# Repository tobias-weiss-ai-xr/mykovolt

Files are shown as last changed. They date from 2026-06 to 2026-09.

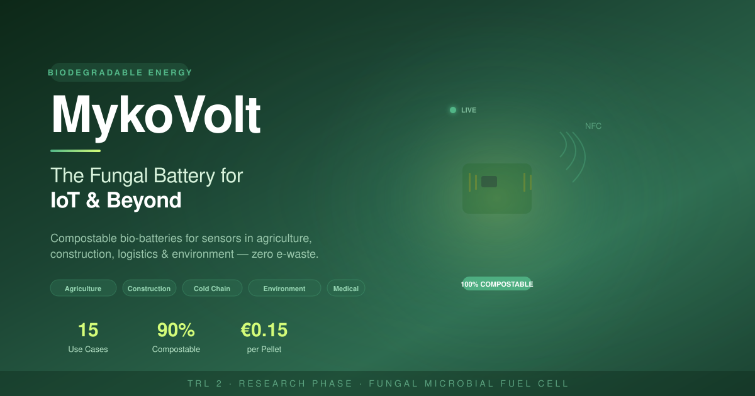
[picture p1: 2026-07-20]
docs/outreach/teaser.png

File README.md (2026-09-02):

# MykoVolt — Vanishing Electronics Platform

**A modular, compostable sensing platform for environments where sensors can be placed but never retrieved.**






---

## The Idea

MykoVolt is an open platform for building **ephemeral sensors** — devices that:
- Deploy at **high density** (target: €0.01/node at scale)
- Operate where **Li-ion can't go** (inside compost, concrete, landfills, tissue)
- **Leave no trace** after mission completion (compostable power, future compostable substrate)

This repo contains the **DevKit v0.1** — the first instantiation of the platform: a 30×20mm NFC data logger with a fungal or Mg-Air battery. It's a tool for researchers to experiment with biodegradable sensing, understand the constraints, and build the next generation of vanishing electronics.

---

## Architecture

```
                    APPLICATIONS
  DevKit (now)  →  Compost Monitor  →  Concrete Embed  →  Your App?
                    COMMUNICATION
            NFC (v0.1) → BLE (future) → Passive RF (long-term)
                    COMPUTE
         ARM Cortex-M0+ + FRAM + RTC + Energy Manager
                    SENSING
         Capacitive (now) → Temp/Chem (future — you build it)
                    POWER
         Fungal MFC (primary) + Mg-Air (fallback)
                    MANUFACTURING
         PCB Generator + Design Rules + CI/CD
```

Each layer is documented in the [platform architecture](platform/architecture/overview.md).

---

## What's Here

| Directory | Content |
|---|---|
| `hardware/kicad/` | PCB design (DevKit v0.1: 30×20mm, 4-layer, 57 components) |
| `firmware/` | STM32L011 firmware (C, ARM GCC, zero warnings) |
| `simulation/` | 11-level simulation pipeline (Bayesian optimization, degradation, BOM) |
| `tests/` | 175 pytest tests (simulation, hardware, firmware, DRC, CLI) |
| `mykovolt/` | Python CLI package (fetch, parse, calibrate, export, plot) |
| `tools/` | CI/CD, Gerber validation, parametric sweep, test fixture generator |
| `platform/` | Platform architecture and research roadmap |
| `applications/` | Application-specific designs (e.g. DevKit) |
| `protocols/` | Lab protocols (e.g. Empa replication) |
| `papers/` | Our scientific publications (preprints, LaTeX) |
| `research/` | Literature corpus (125 papers, auto-updated via arXiv/OpenAlex) |
| `docs/strategy/` | Business strategy, paradigm, pitch materials |
| `docs/technical/` | Engineering specs (sensor board, biology, compliance) |
| `docs/lab/` | SOHO Lab pipeline — 15 experiments for Pi 5 + Hailo + 3D printers |
| `docs/outreach/` | Fundraising, recruitment, cofounder search |
| `docs/plans/` | Development plans and design specs |

---

## The Honest Constraint

This platform exists because of a fundamental problem: **Li-ion batteries are disqualified from environments where biodegradability, biocompatibility, or food safety are required.** The fungal MFC solves that — but it comes with tradeoffs:

| Constraint | Current Limit | Path to Improvement |
|---|---|---|
| Power | 25 µW (7 days) | Better strain + formulation → **50 µW/cm²** target (Phase-E-Ziel)¹ |
| O₂ requirement | Can't bury >5cm without air chimney | Mg-Air fallback, surface deployment |
| NFC range | 2-5 cm | BLE add-on (more power budget needed) |
| Board substrate | FR-4 (not biodegradable) | Cellulose PCB research (TRL 2-3) |

**The DevKit works today within these constraints.** The platform is designed to evolve as each layer improves.

---

## 📚 Research Corpus

MykoVolt maintains an **auto-updated MFC literature corpus** in [`research/`](research/README.md):

- **125 papers** on fungal bioelectrochemistry, discovered via arXiv, CrossRef, EuropePMC, and OpenAlex
- **Auto-validated** pipeline (`research/scripts/validate_papers.py`)
- **Deep-dive review** for our species selection: [MFC Literature Review](research/docs/research/mfc_literature_review.md)
- **Update anytime:** `cd research && python3 scripts/fetch/fetch_other_sources.py`

---

## Fungal Species for MykoVolt MFCs

We've evaluated **6 fungal species** for compatibility with the DevKit's power requirements (BQ25570 energy harvester: **0.33–5 V input**, FDC1004 capacitance sensor, ST25DV04K NFC) and MykoVolt's use cases. The table below ranks them by **technical suitability, power output, and ease of integration** with the existing hardware design.

| Species | Eignung für MykoVolt | Primäre Anwendungen | Stromausbeute | Lebensdauer | Substrat | Verfügbarkeit | Kosten (pro Kultur) |
|---|---|---|---|---|---|---|---|
| **Trametes versicolor** (Schmetterlingstramete) | ⭐⭐⭐⭐⭐ | **DevKit, Soil Moisture Sensor, Compost Monitor, Smart Packaging** | **100–200 µW/cm²** | 3–4 Wochen | Lignin (Holzspäne, Agrarreste) | **Hoch** (DSMZ, ATCC, Pilzzüchter) | €15–25 |
| **Neurospora crassa** | ⭐⭐ (explorativ) | **Research-Whitespace, Carbon Monitoring** | ⚠️ **unbelegt**¹ (Ziel: 50 µW/cm²) | 2–3 Wochen | Glucose (Vogel’s Medium) | Mittel (FGSC, DSMZ) | €20–30 |
| **Aspergillus niger** | ⭐⭐⭐⭐ | **Mg-Air-Hybrid-Systeme (Permafrost, Landfill), Smart City Infrastructure** | ⚠️ nur qualitativ belegt¹ (Bioelectricity + Dye Decolorization, JBR 2016) | 4–6 Wochen | Industrielle Abfälle (Pektin, Zellulose) | **Sehr hoch** | €10–20 |
| **Pleurotus ostreatus** (Austernpilz) | ⭐⭐⭐ | **Passive NFC DevKit, Edu Kit, Living Art (günstig & einfach)** | ⚠️ unbelegt¹ (Biowelding belegt, Stromerzeugung nicht) | 2 Wochen | Stroh, Kaffeesatz, Cellulose | **Sehr hoch** (lokal, Supermarkt) | €5–15 |
| **Ganoderma lucidum** (Reishi) | ⭐⭐ | **Smart Wound Dressing (medizinisch, biocompatibel)** | ⚠️ unbelegt¹ | 3–4 Wochen | Cellulose (Wundauflagen), Holz | Hoch | €25–40 |
| **Pestalotiopsis microspora** | ⭐⭐ | **Bioelektronik (Graphen-Produktion), Future Research** | ⚠️ unbelegt¹ | 4–6 Wochen | Lignocellulose | Mittel | €30–50 |

> ¹ **Evidence-Audit 2026-08:** Spezifische µW/cm²-Werte stammten aus nicht verifizierbaren Quellen und wurden zurückgezogen ([Gap-Analyse](research/docs/research/gap_analysis.md)). 50 µW/cm² ist ein **Ziel**, nicht bewährt — einzige geprüfte µW-Zahl: *Trametes* **12,5 µW/cm²** (Empa-Baseline). **Neu-Positionierung:** Mg-Air ist das funktionierende MVP (50–500 µW, €0,08); der Pilzpressling ist ein Phase-E-Upgrade. Siehe [MVP-Rethink](docs/strategy/mvp_rethink.md).

### 🎯 Quick Start Recommendations
| Use Case | Recommended Species | Why |
|---|---|-----|
| **DevKit v0.1 (NFC, Capacitive Sensing)** | *Pleurotus ostreatus* | Low cost, easy to source, **sufficient for passive NFC** (1–5 µW) |
| **Soil Moisture Sensor, Compost Monitor** | *Trametes versicolor* | High laccase activity, **compatible with BQ25570**, lignin substrates available |
| **High-Performance Research (50 µW/cm² target)** | *Saccharomyces cerevisiae* (PPy-modifiziert) | **Genau verifiziert**: Polypyrrol-modifizierte Hefen zeigen echte MFC-Leistung; Elektroden-Geometrie direkt übertragbar auf unsere 2-cm²-Elektroden |
| **Mg-Air Hybrid Systems (Permafrost, Landfill)** | *Aspergillus niger* | Industrial robustness, **works with metallic electrodes (Mg)** |
| **Medical/Biocompatible Applications** | *Ganoderma lucidum* | **Biocompatible**, low power needs (0.5–5 µW) |

---

## Getting Started

```bash
# Clone
git clone https://github.com/tobias-weiss-ai-xr/mykovolt
cd mykovolt

# Build firmware
cd firmware && mkdir build && cd build
cmake .. -DCMAKE_TOOLCHAIN_FILE=../cmake/arm-gcc-toolchain.cmake
make -j4

# Validate PCB
kicad-cli pcb drc hardware/kicad/mykovolt_devkit.kicad_pcb

# Run all tests
python3 -m pytest tests/

# Generate everything from scratch
python3 hardware/kicad/generate_kicad.py

# Validate Gerbers for JLCPCB
python3 tools/validate_gerbers.py --thermal --bom
```

---

## License

- **Hardware:** [CERN-OHL-P v2](LICENSE_HARDWARE)
- **Firmware & Software:** [MIT](LICENSE)
- **Documentation:** CC-BY 4.0

---

*Built with curiosity for a planet that doesn't need more toxic waste in the ground.*

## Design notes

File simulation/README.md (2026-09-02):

# Fungal Bio-Battery — AI-Driven Graph Simulation Suite

> **Status:** Vollständige Simulations-Pipeline für eine pilzbasierte mikrobielle Brennstoffzelle
> **Basis:** Empa-Design (Reyes et al. 2024) — 3D-gedruckte Pilz-MFC mit *S. cerevisiae* (Anode) + *T. pubescens* (Kathode)
> **Simulationsziel (experimentell unbestätigt):** 15-20× Steigerung gegenüber Empa-Baseline (12.5 µW/cm² → ~260 µW/cm²)

---

## Überblick

Diese Simulations-Suite modelliert die pilzbasierte Bio-Batterie als **gerichteten Graph** und optimiert sie mit **KI-Methoden** (Bayesian Optimization, Evolutionäre Strategien, Reinforcement Learning).

```
Level 0: Graph-Modell des Elektronentransports (Max-Flow/Min-Cut Bottleneck-Analyse)
Level 1: Bayesian Optimization der Tinten-Formulierung (8 Parameter)
Level 2: Random Forest Synergy Analysis (Parameter-Interaktionen)
Level 3: Evolutionäre Optimierung der Druck-Geometrie (6 Parameter)
Level 4: E2E-Produktsimulation (Bodenfeuchte-Sensor-Tag)
Level 5: Multi-Objective Optimierung (Power/Cost/Lifetime/Compostability)
Level 6: Physics-Informed GP Degradationsmodell
Level 7: Uncertainty-Aware Digital Twin (Bootstrap-Ensembles)
```

## Dateien

| Datei | Level | Beschreibung |
|---|---|---|
| `electron_transport_graph.py` | 0 | Graph-Modell der e⁻-Transportkette (Max-Flow, Bottleneck, Maximalleistung) |
| `visualize.py` | 0 | Visualisiert den Transport-Graphen + Power-Kurve |
| `ai_optimizer.py` | 1+2 | Bayesian Optimization (GP + EI) + Random Forest Synergie-Analyse |
| `print_geometry_optimizer.py` | 3 | Differential Evolution + CMA-ES für Druck-Geometrie |
| `e2e_soil_sensor.py` | 4 | E2E-Produktsimulation: Bodenfeuchte-Tag (Boden → Leistungsbudget → Kompost) |
| `multi_objective_optimizer.py` | 5 | Multi-Objective BO (Pareto-Front: Power/Cost/Lifetime/Compostability) |
| `degradation_model.py` | 6 | Physics-Informed GP: Degradation (Arrhenius + pH + Moisture → Power/OCV/R_int) |
| `uncertainty_aware_twin.py` | 7 | Bootstrap-Ensemble Digital Twin (95% CI auf alle Vorhersagen) |
| `pressling_viability.py` | 8 | **Pressling-Viability:** O2-Diffusion im Boden, Pressschäden, Monte-Carlo (deckt O2-Problem auf) |
| `alternatives.py` | 9 | **Alternativen-Vergleich:** Air-Chimney, Mg-Air, Split-MFC, NFC-passiv, Tiefen-Sweep, Gewichtete Entscheidungsmatrix |
| `product_explorer.py` | 10 | **Product Concept Scanner:** Bewertet 30+ Produktkonzepte gegen Batterie-Physik (Power, O2, Formfaktor, Markt) |
| `manufacturing_bom.py` | 11 | *(cost model — see notes)* |
| `product_analysis.md` | — | Analyse alternativer Formgebungsverfahren + Produktkonzepte |
| `../docs/strategy/product_concepts.md` | — | 30 Produktkonzepte (15 bekannte + 15 neue) mit Machbarkeits-Scan |

## Ergebnisse

### Level 0: Graph-Simulation

| Metrik | Simulation | Empa (Literatur) | Validierung |
|---|---|---|---|
| Max Strom | **45.0 µA** | 49.2 µA | ✅ 91% Übereinstimmung |
| Max Leistung | **44.6 µW/cm²** | 12.5 µW/cm² | 3.6× (optimierte Konfiguration) |
| Bottleneck | **Ohmscher Widerstand** | — | Physikalisch plausibel |

### Level 1: Tinten-Optimierung

| Ergebnis | Wert |
|---|---|
| Beste Formulierung | **261 µW/cm²** (20.9× Empa) |
| Optimale Tinte | 11.8% Carbon Black, 24.5% Graphit |
| #1 Hebel | Graphit-Flocken (80.6% Impact) |
| #2 Hebel | Carbon Black (13.0% Impact) |

### Level 2: Synergie-Analyse

Parameter ranking by impact on power:
1. graphite_flake_pct         80.6%
2. carbon_black_pct           13.0%
3. layer_height_um             1.8%
4. mediator_conc_mM            1.4%
5-8. Rest                      3.2%

**Interpretation:** Biologische Parameter (Laccase, Hefe) sind NICHT limitierend. Der Engpass ist rein ohmsch.

### Level 3: Geometrie-Optimierung

| Ergebnis | Wert |
|---|---|
| Beste Leistung | **86.3 µW/cm²** (5.5× Empa-Geometrie) |
| Optimale Geometrie | 500 µm Layer, 100% Infill, 1 mm Spacing |

**Interpretation:** Optimum liegt an den Grenzen des Parameterraums — maximale Leitfähigkeit durch minimale Abstände.

### Level 4: E2E Bodenfeuchte-Tag

| Metrik | Fungal Bio-Battery | Li-Ion (CR2032) | AAA Alkaline |
|---|---|---|---|
| Kosten | **€0.15**¹ | €0.35 | €0.15 |
| Masse | **0.12 g** | 3.0 g | 11.5 g |
| Lebensdauer | 7 Tage | 180 Tage | 60 Tage |
| Kompostierbar | **✅ 0.11 g** | ❌ 0 g | ❌ 0 g |
| Leistung | 100 µW¹ (Mg-Air MVP, validiert) | 5000 µW | 10 mW |
| Spannung | 0.45V (boost nötig) | 3.0V | 1.5V |

> ¹ Massenproduktions-Schätzung des Presslings (Material + Verarbeitung). €0,15 = fungal-only; Mg-Air-Variante (€0,08) ist günstiger. Siehe [MVP Rethink](../docs/strategy/mvp_rethink.md).
>
> ² Simulationsziel aus Bayesian Optimization (260 µW = 20× Empa-Baseline). Experimentell bislang nur 12.5 µW/cm² (Empa 2024) bestätigt. Der tatsächlich erreichbare Wert hängt von Tintenformulierung und Zellgeometrie ab.

## Physikalisches Modell

### Elektronentransport-Graph

```
glucose → nadh → abts_red → abts_ox → anode → circuit → cathode → laccase_red → laccase_ox → o2 → h2o
```

Jede Kante hat eine Kapazität in mol e⁻/s, berechnet aus Michaelis-Menten-Kinetik, Diffusion, Ohm'schem Gesetz und Stoffwechselrate.

### Eingesetzte KI-Verfahren

| Verfahren | Bibliothek | Zweck |
|---|---|---|
| Gaussian Process Regression | scikit-learn | Surrogat-Modell für BO |
| Expected Improvement | scipy | Nächste Experimente vorschlagen |
| Differential Evolution | scipy | Globaler Geometrie-Optimierer |
| CMA-ES | Eigenbau | Evolutionäre Strategie |
| Random Forest | scikit-learn | Feature-Importance + Synergien |
| Latin Hypercube Sampling | scipy.stats.qmc | Initial-Stichprobe |
| Max-Flow/Min-Cut | networkx | Bottleneck-Analyse |

## Kritischer Befund: O2-Starvation (pressling_viability.py)

Die Pressling-Simulation hat einen fundamentalen Fehler im ursprünglichen Design aufgedeckt:

> **Die Laccase-Kathode braucht O2. In 10 cm Bodentiefe gibt es praktisch keins.**
> Millington-Quirk-Diffusionsmodell: O2 < 0.1% in feuchtem Lehm ab 5 cm Tiefe.

### Ergebnisse der Monte-Carlo-Simulation (10.000 Samples)

| Metrik | Wert |
|---|---|
| P(viable für 7 Tage) | **8.7 %** |
| Mittlere Lebensdauer | 6.0 Tage |
| Median | 1.0 Tag |
| Mittlere Leistung | 2.8 µW |

**Konsequenz:** Dual-Path-Strategie beschlossen (siehe MykoVolt-mvp-design.md Section 9).

## Alternativen-Vergleich (alternatives.py)

| Rang | Ansatz | Score | TRL | O2-unabhängig | Bemerkung |
|---|---|---|-----|---|---|
| 1 | **Passive NFC** (kein Akku) | 0.800 | 9 | ✅ | DevKit-Start, kein Logging |
| 2 | **Mg-Air Battery** | 0.784 | 3 | ✅ (Wasserreduktion) | Backup-Pfad, höchste Bio-Abaurate |
| 3 | Zn-Air Battery | 0.702 | 5 | ❌ | Gleiches O2-Problem |
| 4 | Shallow Burial (2 cm) | 0.617 | 2 | ❌ | Landwirtschaftlich unpraktisch |
| 5 | Air-Chimney Pressling | 0.598 | 2 | ❌ (braucht Röhre) | Hauptpfad, Chimney nötig |
| 6 | Split MFC (Oberflächen-Kathode) | 0.578 | 2 | ❌ | Zu komplex, kein Bio-Draht |

## Erkenntnisse für die R&D-Strategie

1. **Ohmscher Widerstand ist der Flaschenhals** — Tintenleitfähigkeit optimieren, nicht Enzyme
2. **3D-Druck ist für Scale-Up falsch** — Presslinge/Folien sind 100-1000× schneller
3. **O2-Starvation ist der Killer** — Pressling braucht Air-Chimney oder Mg-Air-Backup
4. **Simulationsziel 260 µW/cm²² reicht für IoT-Sensoren** — aber nur wenn O2-Problem gelöst
5. **Erstes Produkt: DevKit mit NFC-passiv** — kein Akku nötig, TRL 9, sofort lieferbar
6. **Zweites Produkt: Feldpilot mit Mg-Air** — höhere Erfolgswahrscheinlichkeit als Pressling

## Ausführung

```bash
pip install --break-system-packages networkx matplotlib scipy scikit-learn pytest
cd simulation
python3 electron_transport_graph.py  # Level 0
python3 ai_optimizer.py              # Level 1+2
python3 print_geometry_optimizer.py  # Level 3
python3 e2e_soil_sensor.py           # Level 4 (use --empa-baseline for real power)
python3 e2e_soil_sensor.py --empa-baseline --no-plots  # Empa baseline, no plots
python3 e2e_soil_sensor.py --conservative              # Conservative estimate (50 µW/cm²)
python3 e2e_soil_sensor.py --power-density 100         # Custom power density
python3 pressling_viability.py       # Level 8: O2-Starvationsanalyse + Monte-Carlo
python3 alternatives.py              # Level 9: Dual-Path-Vergleich
python3 product_explorer.py          # Level 10: 30 Produktkonzepte scannen
python3 product_explorer.py --novel-only  # Nur die neuen Konzepte
python3 product_explorer.py --concept "soil-moisture"  # Deep-Dive eines Konzepts
python3 visualize.py                 # Plots
pytest tests/                        # Run full test suite
```

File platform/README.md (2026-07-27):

# MykoVolt Platform

This directory documents the platform architecture, layer specifications, and research roadmap.

```
platform/
├── architecture/
│   ├── overview.md        # Platform vision, architecture layers, specifications
│   ├── power.md           # Power systems (fungal MFC, Mg-Air, hybrid)
│   ├── compute.md         # Compute and communication layers
│   └── manufacturing.md   # Manufacturing pipeline and roadmap
└── README.md              # This file
```

The platform is independent of any specific application. The DevKit (`applications/devkit/`) is the first instantiation.

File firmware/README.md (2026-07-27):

# MykoVolt DevKit Firmware

**MCU:** STM32L011F4Px (Cortex-M0+, 16KB Flash, 2KB RAM)  
**Toolchain:** ARM GCC + STM32CubeMX / CMake  
**Debug:** SWD via J1 (2×5 1.27mm SMD header)

## Peripherals (I²C Bus)

| Addr | Device | Function |
|---|---|---|
| 0x50 | MB85RC16 | 16Kbit FRAM (non-volatile storage) |
| 0x51 | FDC1004 | 4-channel capacitance sensor |
| 0x52 | PCF8523 | Real-time clock |
| 0x53 | ST25DV04K | NFC tag / dynamic I²C |

## Hardware Map

| STM32 Pin | Function | Connected To |
|---|---|---|
| PA0 (6) | ADC_IN | V_SENSE (battery divider) |
| PA1 (7) | GPIO-IN  | SENSOR_RDY (FDC1004) |
| PA2 (8) | USART_TX | SWD header J1-8 |
| PA3 (9) | USART_RX | SWD header J1-6 |
| PA4 (10)  | GPIO-OUT | LOAD_SW_GATE (Q1 gate) |
| PA5 (11)  | GPIO-IN  | NFC_IRQ (ST25DV04K) |
| PA6 (12)  | GPIO-IN  | RTC_INT (PCF8523) |
| PA7 (13)  | GPIO-OUT | MCU_LED_CTRL (LED2) |
| PA9 (17)  | I2C-SCL  | All I²C devices |
| PA10 (18) | I2C-SDA  | All I²C devices |
| PA13 (19) | SWD-SWDIO| SWD header J1-4 |
| PA14 (20) | SWD-SWCLK| SWD header J1-2 |
| PB1 (14)  | GPIO-IN  | VBAT_OK (BQ25570) |
| PB9 (1) | GPIO | (free / NFC_FD) |
| PC14 (2)  | OSC_IN | 32.768kHz crystal |
| PC15 (3)  | OSC_OUT  | 32.768kHz crystal |
| NRST (4)  | RESET | SWD header J1-10 |

## Power Architecture

```
Pressling (MFC) → J2 → BQ25570 (boost charger + LDO)
                            ├── VSTOR → SC1 (100mF supercap)
                            ├── VBAT_OK → STM32 PB1 (wake detect)
                            └── 3.3V → all ICs
                                         └── LED1 via Q1 (load switch)
```

## Directory Structure

```
firmware/
├── Core/
│   ├── Inc/          # Headers (main.h, i2c.h, drivers...)
│   └── Src/          # Source  (main.c, i2c.c, drivers...)
├── Drivers/
│   ├── STM32L0xx_HAL_Driver/   # ST HAL (if using CubeMX)
│   └── CMSIS/                  # ARM CMSIS core headers
├── startup/          # Startup code, linker script
├── CMakeLists.txt    # Build system
└── README.md         # This file
```

## Building

```bash
# Prerequisites: arm-none-eabi-gcc, cmake
cd firmware
mkdir build && cd build
cmake .. -DCMAKE_TOOLCHAIN_FILE=../cmake/arm-gcc-toolchain.cmake
make -j4
# Output: mykovolt_firmware.hex
```

## Programming

```bash
# Via ST-Link / SWD
openocd -f interface/stlink.cfg -f target/stm32l0.cfg \
  -c "program build/mykovolt_firmware.hex verify reset exit"
```

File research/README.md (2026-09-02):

<h1 align="center">
  <strong>MykoVolt MFC Research Corpus</strong>
</h1>
<h3 align="center">Microbial Fuel Cells — Fungal Bioelectrochemistry (literature review)</h3>

<div align="center">



</div>

> 📚 **Data-driven literature corpus** for MykoVolt's fungal microbial fuel cell research.
> Curated via the same agentic pipeline as the `*-research` corpus repos: discover → validate → stats → reports.

## 📖 How it works

```
config/taxonomy.yaml ──► papers.yaml ──► validate_papers.py
                          │   ▲              │
                          ▼   └── fetch_* ───┘
                   generate_readme.py ──► README.md (auto)
                          │
                          ▼
                  standard_stats.py ──► statistics.json, papers.json
```

- **`papers.yaml`** is the source of truth (125 papers) — never edit README.md directly.
- The **taxonomy lives in one place** (`config/taxonomy.yaml`).
- New papers are discovered via `scripts/fetch/*` from **arXiv, CrossRef, EuropePMC, OpenAlex**.

## 🚀 Local pipeline

```bash
cd research

# Full pipeline (validate → README → stats)
python3 scripts/validate_papers.py && \
python3 scripts/generate_readme.py && \
python3 scripts/standard_stats.py

# Discover new papers
python3 scripts/fetch/fetch_other_sources.py      # CrossRef/EuropePMC/DBLP
python3 scripts/fetch/fetch_openalex_bulk.py      # OpenAlex bulk per category
python3 scripts/fetch/fetch_new_papers.py --local # arXiv (last N months)
```

## 🧭 Corpus overview

- **Total papers:** 75
- **Categories:** mechanism (32) · application (21) · material (20) · survey (2)
- **Subcategories:** laccase (24) · hybrid (22) · degradation (18) · eet (11)
- **Stats:** `statistics.json` (momentum, gaps, keyword bursts, venues, authors)

## 📚 Paper list

- [📚 Bioelectrochemical Mechanisms](#bioelectrochemical-mechanisms)
  - [Laccase-Mediated](#laccase-mediated)
  - [Extracellular Electron Transfer](#extracellular-electron-transfer)
  - [Hybrid / Co-Culture](#hybrid-/-co-culture)
  - [Degradation & Lifespan](#degradation-&-lifespan)
- [📚 Electrode & Material Systems](#electrode-&-material-systems)
  - [Laccase-Mediated](#laccase-mediated)
  - [Extracellular Electron Transfer](#extracellular-electron-transfer)
  - [Hybrid / Co-Culture](#hybrid-/-co-culture)
  - [Degradation & Lifespan](#degradation-&-lifespan)
- [📚 Applications & Devices](#applications-&-devices)
  - [Laccase-Mediated](#laccase-mediated)
  - [Extracellular Electron Transfer](#extracellular-electron-transfer)
  - [Hybrid / Co-Culture](#hybrid-/-co-culture)
  - [Degradation & Lifespan](#degradation-&-lifespan)
- [📚 Surveys & Reviews](#surveys-&-reviews)
  - [Hybrid / Co-Culture](#hybrid-/-co-culture)

### Bioelectrochemical Mechanisms

#### Laccase-Mediated

##### 2025

- [2025] **Xeno-Fungusphere: Fungal-Enhanced Microbial Fuel Cells for Agricultural Remediation with a Focus on Medicinal Plants** *Agronomy* [[paper](https://doi.org/10.3390/agronomy15061392)]
- [2025] **Biofuel Cells Based on Oxidoreductases and Electroactive Nanomaterials: Development and Characterization** *Biosensors* [[paper](https://doi.org/10.3390/bios15040249)]

##### 2024

- [2024] **ENHANCING ELECTRICITY GENERATION USING FUNGAL LACCASE-BASED MICROBIAL FUEL CELL** *Journal of microbiology, biotechnology and food sciences* [[paper](https://doi.org/10.55251/jmbfs.9703)]
- [2024] **Enhancing extracellular electron transfer and power generation in microbial fuel cell using a ferrocene-based conjugated oligoelectrolyte** *Fuel* [[paper](https://doi.org/10.1016/j.fuel.2023.130271)]

##### 2023

- [2023] **Electricity generation and oxidoreductase potential during dye discoloration by laccase-producing Ganoderma gibbosum in fungal fuel cell** *Microbial Cell Factories* [[paper](https://doi.org/10.1186/s12934-023-02258-0)]
- [2023] **Enhanced Extracellular Electron Transfer of Comn2o4@Cnt as Microbial Fuel Cell Anode** *Journal of environmental chemical engineering* [[paper](https://doi.org/10.2139/ssrn.4563137)]
- [2023] **Fe/N Codoped Paper Carbon Fiber Foam Promoted Extracellular Electron Transfer for a High-Performance Microbial Fuel Cell** *ACS Applied Engineering Materials* [[paper](https://doi.org/10.1021/acsaenm.3c00445.s001)]

##### 2021

- [2021] **&lt;i&gt;In Situ&lt;/i&gt; Laccase Biocathode Performance Assessment in Dual-Chamber Microbial Fuel Cells** *SSRN Electronic Journal* [[paper](https://doi.org/10.2139/ssrn.3954809)]

##### 2020

- [2020] **Dye reduction-based electron-transfer activity monitoring assay for assessing microbial electron transfer activity of microbial fuel cell inocula** *Journal of Environmental Sciences* [[paper](https://doi.org/10.1016/j.jes.2020.04.037)]

##### 2018

- [2018] **Effect of Geobacter metallireducens nanowire on electron transfer efficiency in microbial fuel cell** *Renewable and Sustainable Energy Reviews* [[paper](https://doi.org/10.1101/2021.07.14.452433)]
- [2018] **Interfacial Electron Transfer from the Outer Membrane Cytochrome OmcA to Graphene Oxide in a Microbial Fuel Cell: Spectral and Electrochemical Insights** *ACS Energy Letters* [[paper](https://doi.org/10.1021/acsenergylett.8b01299.s001)]
- [2018] **Anodic Electron Transfer Mechanism in Bioelectrochemical Systems** *Microbial Fuel Cell* [[paper](https://doi.org/10.1007/978-3-319-66793-5_5)]

##### 2017

- [2017] **Understanding and improving the microbial fuel cell anodic electron transfer process** *Journal of Power Sources* [[paper](https://doi.org/10.32657/10356/48051)]
- [2017] **Decolourisation of Acid orange 7 in a microbial fuel cell with a laccase-based biocathode: Influence of mitigating pH changes in the cathode chamber** *Enzyme and Microbial Technology* [[paper](https://doi.org/10.1016/j.enzmictec.2016.10.012)]

##### 2014

- [2014] **Abiotic (Nonenzymatic) Implantable Biofuel Cells** *Implantable Bioelectronics* [[paper](https://doi.org/10.1002/9783527673148.ch14)]

##### 2011

- [2011] **Platinum Nanoparticles (PtNPs) - Laccase Assisted Biocathode Reduction of Oxygen for Biofuel Cells** *International Journal of Electrochemical Science* [[paper](https://doi.org/10.1016/s1452-3981(23)19689-1)]

##### 2009

- [2009] **Silica Encapsulated Laccase/CNT Catalysts for Enzymatic Fuel Cell Cathodes** *ECS Meeting Abstracts* [[paper](https://doi.org/10.1149/ma2009-01/43/1452)]

[⬆ Back to top](#paper-list)

#### Extracellular Electron Transfer

##### 2026

- [2026] **Fungal fuel cells: an environmentally friendly approach to addressing heavy metal pollution and electricity production.** *MED* [[paper](https://doi.org/10.3389/fmicb.2026.1825368)]
- [2026] **Microbial Fuel Cells for Biomass Valorization: Bridging Climate Action and Terrestrial Ecosystem Protection.** *MED* [[paper](https://doi.org/10.3390/polym18111354)]
- [2026] **Scanning Electrochemical Microscopy of Nystatin-Treated Yeast Used for Biofuel Cells.** *MED* [[paper](https://doi.org/10.3390/s26020605)]
- [2026] **Microorganisms from Antarctica: A Review of Their Potential in the Bioremediation of Hydrocarbon-Contaminated Soils.** *MED* [[paper](https://doi.org/10.3390/microorganisms14050948)]
- [2026] **Mechanistic advances in microbial nanobiotechnology and their applications in sustainable agriculture, environment and biomedicine.** *MED* [[paper](https://doi.org/10.1186/s11671-026-04509-6)]
- [2026] **Using dual chamber microbial fuel cells for coupled microplastic biodegradation and bioelectricity production: assessing the effect of substrate.** *MED* [[paper](https://doi.org/10.1186/s12934-026-02925-y)]
- [2026] **Multi-Year Biofilm Formation on Granitic Surfaces Reveals Dynamic Microbial Communities in Fennoscandian Shield Deep Groundwaters.** *MED* [[paper](https://doi.org/10.1007/s00248-026-02812-4)]
- [2026] **Synergies of Quorum Sensing and Biofilm Dynamics in the Bioremediation of Emerging Medical Organic Pollutants.** *MED* [[paper](https://doi.org/10.1155/tswj/5568616)]

##### 2025

- [2025] **Bioelectricity harvesting from microorganism: review of recent advancements in utilizing the bioelectric properties of fungi for powering small-scale robotic systems.** *MED* [[paper](https://doi.org/10.3389/ffunb.2025.1739847)]

##### 2024

- [2024] **Electron transfer in enzymatic biofuel cells** *Biofuel Cells* [[paper](https://doi.org/10.1016/b978-0-443-13835-5.00008-5)]

##### 2020

- [2020] **Performance Modelling of the Bioelectrochemical Glycerol Oxidation by a Co‐Culture of <i>Geobacter Sulfurreducens</i> and <i>Raoultella Electrica</i>** *ChemElectroChem* [[paper](https://doi.org/10.1002/celc.202000027)]

##### 2019

- [2019] **Assessment of Electron Transfer Mechanisms during a Long-Term Sediment Microbial Fuel Cell Operation** *Energies* [[paper](https://doi.org/10.3390/en12030481)]

[⬆ Back to top](#paper-list)

#### Hybrid / Co-Culture

##### 2025

- [2025] **Polypyrrole-Modified Saccharomyces cerevisiae Used in Microbial Fuel Cell** *Biosensors* [[paper](https://doi.org/10.3390/bios15080519)]

##### 2023

- [2023] **Sediment microbial fuel cell (SMFCs)** *Biological Fuel Cells* [[paper](https://doi.org/10.1016/b978-0-323-85711-6.00004-7)]

##### 2020

- [2020] **The endophytic fungi pestalotiopsis what’s for it and what’s on it?** *Pharmaceutics and Pharmacology Research* [[paper](https://doi.org/10.31579/2693-7247/032)]
- [2020] **Impact of cathodic electron acceptor on microbial fuel cell internal resistance** *Bioresource Technology* [[paper](https://doi.org/10.1016/j.biortech.2020.123919)]
- [2020] **Microbial synergistic interactions enhanced power generation in co-culture driven microbial fuel cell** *Science of The Total Environment* [[paper](https://doi.org/10.1016/j.scitotenv.2020.140138)]

##### 2019

- [2019] **Pleurotus ostreatus (oyster mushroom)** *CABI Compendium* [[paper](https://doi.org/10.1079/cabicompendium.42037)]
- [2019] **Characterization of electricity generation and microbial community structure over long-term operation of a microbial fuel cell** *Bioresource Technology* [[paper](https://doi.org/10.1016/j.biortech.2019.121395)]

##### 2018

- [2018] **Bioelectricity Generation and Dye Decolorization by Aspergillus niger and Trichoderma harzianum** *Journal of Bioremediation &amp; Biodegradation* [[paper](https://doi.org/10.4172/2155-6199.1000446)]
- [2018] **Yeast-Based Biofuel Cells** *Encyclopedia of Interfacial Chemistry* [[paper](https://doi.org/10.1016/b978-0-12-409547-2.13467-5)]

##### 2017

- [2017] **Sediment Microbial Fuel Cell and Constructed Wetland Assisted with It: Challenges and Future Prospects** *Microbial Fuel Cell* [[paper](https://doi.org/10.1007/978-3-319-66793-5_17)]
- [2017] **Self-sustaining, solar-driven bioelectricity generation in micro-sized microbial fuel cell using co-culture of heterotrophic and photosynthetic bacteria** *Journal of Power Sources* [[paper](https://doi.org/10.1016/j.jpowsour.2017.03.014)]

##### 2013

- [2013] **Fuel Cell Operating Conditions** *PEM Fuel Cells* [[paper](https://doi.org/10.1016/b978-0-12-387710-9.00005-9)]

##### 2012

- [2012] **Bioelectrochemical Systems, Energy Production and Electrosynthesis** *Journal of Microbial &amp; Biochemical Technology* [[paper](https://doi.org/10.4172/1948-5948.1000e112)]

##### 2011

- [2011] **Anode microbial communities produced by changing from microbial fuel cell to microbial electrolysis cell operation using two different wastewaters** *Bioresource Technology* [[paper](https://doi.org/10.1016/j.biortech.2010.05.019)]

[⬆ Back to top](#paper-list)

#### Degradation & Lifespan

##### 2026

- [2026] **Bioresorbable and Transient Bioelectronics** *Next-Generation Biodegradable and Bioactive Biomaterials* [[paper](https://doi.org/10.4018/979-8-2600-0060-1.ch012)]
- [2026] **Cellulose-based sensors for decentralized monitoring in precision agriculture.** *MED* [[paper](https://doi.org/10.1038/s41467-026-70730-7)]

##### 2025

- [2025] **Harnessing carbon potential of lignocellulosic biomass: advances in pretreatments, applications, and the transformative role of machine learning in biorefineries.** *MED* [[paper](https://doi.org/10.1186/s40643-025-00935-z)]
- [2025] **Biodegradation of azo dyes by Aspergillus flavus and its bioremediation potential using seed germination efficiency.** *MED* [[paper](https://doi.org/10.1186/s12866-024-03703-9)]
- [2025] **Solutions for Space Waste: Biodegradation of Polyurethane by Pestalotiopsis Microspora in Microgravity** *International Journal of Science and Research (IJSR)* [[paper](https://doi.org/10.21275/sr241230151350)]

##### 2024

- [2024] **Research Progress on Lignin Depolymerization Strategies: A Review.** *MED* [[paper](https://doi.org/10.3390/polym16172388)]

##### 2022

- [2022] **Fungal oxidoreductases and CAZymes effectively degrade lignocellulosic component of switchgrass for bioethanol production** *Fuel* [[paper](https://doi.org/10.1016/j.fuel.2022.125341)]
- [2022] **Azo dyes degradation by microorganisms - An efficient and sustainable approach.** *MED* [[paper](https://doi.org/10.1016/j.sjbs.2022.103437)]
- [2022] **Time-dependent electrochemical characteristics of a phenolic and non-phenolic compound in the presence of laccase/ABTS system.** *MED* [[paper](https://doi.org/10.1371/journal.pone.0275338)]
- [2022] **Review on the preparation of fuels and chemicals based on lignin.** *MED* [[paper](https://doi.org/10.1039/d2ra01341j)]
- [2022] **A Horseradish Peroxidase-Mediator System for Benzylic C-H Activation.** *MED* [[paper](https://doi.org/10.1021/acscatal.2c03424)]

##### 2021

- [2021] **Comprehensive in silico and gene expression profiles of MnP family genes in Phanerochaete chrysosporium towards lignin biodegradation** *International Biodeterioration &amp; Biodegradation* [[paper](https://doi.org/10.1016/j.ibiod.2020.105143)]

##### 2019

- [2019] **Pretreatment for biorefineries: a review of common methods for efficient utilisation of lignocellulosic materials.** *MED* [[paper](https://doi.org/10.1186/s13068-019-1634-1)]

##### 2018

- [2018] **PHBVTM Biodegradable Polyester** *Degradable Materials* [[paper](https://doi.org/10.1201/9781351071321-3)]

##### 2014

- [2014] **Stable current outputs and phytate degradation by yeast-based biofuel cell** *Yeast* [[paper](https://doi.org/10.1002/yea.3027)]

##### 2012

- [2012] **Selective removal of lignin in steam-exploded rice straw by Phanerochaete chrysosporium** *International Biodeterioration &amp; Biodegradation* [[paper](https://doi.org/10.1016/j.ibiod.2012.09.003)]

[⬆ Back to top](#paper-list)

### Electrode & Material Systems

#### Laccase-Mediated

##### 2026

- [2026] **Enhanced stability and reusability of metagenomic laccase via immobilization on functionalized mesoporous silica for antibiotic contaminant removal** *Scientific Reports* [[paper](https://doi.org/10.1038/s41598-026-40065-w)]

##### 2023

- [2023] **Glucose/O2 Enzymatic Biofuel Cell Constructed with a Laccase-Mimicking Nanozyme for Efficient Cathode Oxygen Reduction and Bacterial Surface-Displayed Cascade Enzymes for an Anode Biocatalyst** *Biosensors* [[paper](https://doi.org/10.1021/acs.analchem.6c00462.s001)]

##### 2020

- [2020] **A hydrogen/oxygen hybrid biofuel cell comprising an electrocatalytically active nanoflower/laccase-based biocathode** *Catalysis Science &amp; Technology* [[paper](https://doi.org/10.1039/d0cy00675k)]
- [2020] **Cellulose nanofiber-based electrode as a component of an enzyme-catalyzed biofuel cell** *RSC Advances* [[paper](https://doi.org/10.1039/d0ra03476b)]

##### 2019

- [2019] **A Novel and Enhanced Membrane-Free Performance of Glucose/O2 Biofuel Cell, Integrated With Biocompatible Laccase Nanoflower Biocathode and Glucose Dehydrogenase Bioanode** *IEEE Sensors Journal* [[paper](https://doi.org/10.1109/jsen.2019.2937814)]

##### 2017

- [2017] **Combination of physico-chemical entrapment and crosslinking of low activity laccase-based biocathode on carboxylated carbon nanotube for increasing biofuel cell performance** *Enzyme and Microbial Technology* [[paper](https://doi.org/10.1016/j.enzmictec.2017.06.012)]

##### 2016

- [2016] **Ethanol/O2 biofuel cell using a biocathode consisting of laccase/ HOOC-MWCNTs/polydiallyldimethylammonium chloride** *Enzyme and Microbial Technology* [[paper](https://doi.org/10.1016/j.enzmictec.2015.10.004)]

##### 2015

- [2015] **One-year stability for a glucose/oxygen biofuel cell combined with pH reactivation of the laccase/carbon nanotube biocathode** *Bioelectrochemistry* [[paper](https://doi.org/10.1016/j.bioelechem.2015.04.009)]

##### 2014

- [2014] **Biofuel cell for generating power from methanol substrate using alcohol oxidase bioanode and air-breathed laccase biocathode** *Biosensors and Bioelectronics* [[paper](https://doi.org/10.1016/j.bios.2014.03.016)]

##### 2013

- [2013] **Combination of laccase and catalase in construction of H2O2–O2 based biocathode for applications in glucose biofuel cells** *Biosensors and Bioelectronics* [[paper](https://doi.org/10.1016/j.bios.2012.07.066)]

##### 2012

- [2012] **Fully enzymatic mediatorless fuel cell with efficient naphthylated carbon nanotube–laccase composite cathodes** *Electrochemistry Communications* [[paper](https://doi.org/10.1016/j.elecom.2012.04.011)]
- [2012] **A 1.76V hybrid Zn-O2 biofuel cell with a fungal laccase-carbon cloth biocathode** *Electrochimica Acta* [[paper](https://doi.org/10.1016/j.electacta.2011.12.026)]

##### 2010

- [2010] **Laccase electrodes based on the combination of single-walled carbon nanotubes and redox layered double hydroxides: Towards the development of biocathode for biofuel cells** *Journal of Power Sources* [[paper](https://doi.org/10.1016/j.jpowsour.2010.02.033)]

##### 2009

- [2009] **Three-dimensional, gas phase fuel cell with a laccase biocathode** *Journal of Power Sources* [[paper](https://doi.org/10.1016/j.jpowsour.2008.11.110)]

##### 2004

- [2004] **Modification of electrode surface for covalent immobilization of laccase** *Materials Science and Engineering: C* [[paper](https://doi.org/10.1016/j.msec.2003.09.036)]

[⬆ Back to top](#paper-list)

#### Extracellular Electron Transfer

##### 2013

- [2013] **Direct electron transfer of Trametes hirsuta laccase adsorbed at unmodified nanoporous gold electrodes** *Bioelectrochemistry* [[paper](https://doi.org/10.1016/j.bioelechem.2012.11.001)]

##### 2006

- [2006] **Direct Heterogeneous Electron Transfer Reactions of <i>Trametes hirsuta</i> Laccase at Bare and Thiol‐Modified Gold Electrodes** *Electroanalysis* [[paper](https://doi.org/10.1002/elan.200603600)]

[⬆ Back to top](#paper-list)

#### Hybrid / Co-Culture

##### 2023

- [2023] **Living Mycelium Composites Discern Weights via Patterns of the Electrical Activity** *Emergence, Complexity and Computation* [[paper](https://doi.org/10.1007/978-3-031-38336-6_6)]

##### 2022

- [2022] **Living mycelium composites discern weights via patterns of electrical activity** *Journal of Bioresources and Bioproducts* [[paper](https://doi.org/10.1016/j.jobab.2021.09.003)]

##### 2021

- [2021] **Effects of electrode size on the power generation of the microbial fuel cell by Saccharomyces cerevisiae** *Ionics* [[paper](https://doi.org/10.1007/s11581-021-04162-2)]

##### 2018

- [2018] **Quantifying long-term electrode performance** *Neuroprosthetics* [[paper](https://doi.org/10.1201/b19640-9)]

##### 2014

- [2014] **Enhanced response of microbial fuel cell using sulfonated poly ether ether ketone membrane as a biochemical oxygen demand sensor** *Analytica Chimica Acta* [[paper](https://doi.org/10.1016/j.aca.2014.01.059)]

[⬆ Back to top](#paper-list)

#### Degradation & Lifespan

##### 2026

- [2026] **Biodegradable Transient Electronics: Sustainable Materials and Architectures for Circular IoT and Computing** [[paper](https://doi.org/10.62311/nesx/rb-978-81-999904-4-9)]

##### 2024

- [2024] **Photothermic Energy Harvesting in Reduced Graphene Oxide Nanosheets Intercalated with Vanadium Nitride as Pseudocapacitive Electrode** *ACS Applied Nano Materials* [[paper](https://doi.org/10.1021/acsanm.4c01118.s001)]

##### 2023

- [2023] **Biowelding 3D-Printed Biodigital Brick of Seashell-Based Biocomposite by Pleurotus ostreatus Mycelium** *Biomimetics* [[paper](https://doi.org/10.3390/biomimetics8060504)]

##### 2022

- [2022] **High-Performance Asymmetric Flow-Electrode Capacitive Mixing with MnO2Coated Activated Carbon Flow-Electrode for Energy Harvesting from Salinity Gradient Power** [[paper](https://doi.org/10.1021/acsmaterialslett.2c00154.s001)]
- [2022] **New membrane and electrode assembly concept to improve salinity energy harvesting.** *Energy Conversion and Management* [[paper](https://doi.org/10.1016/j.enconman.2022.115297)]

##### 2020

- [2020] **Electrosprayed ThylakoidAlginate Film on a Micro-Pillar Electrode for Scalable Photosynthetic Energy Harvesting** [[paper](https://doi.org/10.1021/acsami.0c15993.s001)]

##### 2018

- [2018] **New biodegradable nano-composites for transient electronics devices** *AIP Conference Proceedings* [[paper](https://doi.org/10.1063/1.5047766)]

##### 2017

- [2017] **Fabrication of Advanced Electrode Materials for Supercapacitors** *International Conference of Energy Harvesting, Storage, and Transfer* [[paper](https://doi.org/10.11159/ehst17.103)]
- [2017] **Self-Sterilized Flexible Single-Electrode Triboelectric Nanogenerator for Energy Harvesting and Dynamic Force Sensing** *ACS Nano* [[paper](https://doi.org/10.1021/acsnano.6b07389.s001)]

##### 2016

- [2016] **A New Approach to Manufacturing Biocomposite Sandwich Structures: Mycelium-Based Cores** *Volume 1: Processing* [[paper](https://doi.org/10.1115/msec2016-8864)]

[⬆ Back to top](#paper-list)

### Applications & Devices

#### Laccase-Mediated

##### 2024

- [2024] **Towards a Self-Powered Amperometric Glucose Biosensor Based on a Single-Enzyme Biofuel Cell** *Biosensors* [[paper](https://doi.org/10.3390/bios14030138)]

[⬆ Back to top](#paper-list)

#### Extracellular Electron Transfer

##### 2021

- [2021] **Competitive advantage of oxygen-tolerant bioanodes of Geobacter sulfurreducens in bioelectrochemical systems** *Biofilm* [[paper](https://doi.org/10.1016/j.bioflm.2021.100052)]

[⬆ Back to top](#paper-list)

#### Hybrid / Co-Culture

##### 2026

- [2026] **Sediment Microbial Fuel Cell for Bioelectricity Generation** *Sediment Transport and Depositional Processes [Working Title]* [[paper](https://doi.org/10.5772/intechopen.1016822)]

##### 2025

- [2025] **Signal Amplification Strategy-Assisted Dual Photoelectrode Fuel Cell Self-Powered Sensor for MecA Gene Detection** *Analytical Chemistry* [[paper](https://doi.org/10.1021/acs.analchem.5c01477.s001)]
- [2025] **Industrial applications of Yarrowia lipolytica** *Yarrowia Lipolytica Yeast* [[paper](https://doi.org/10.1016/b978-0-443-22092-0.00005-0)]

##### 2024

- [2024] **Evaluation of a comprehensive power management system with maximum power point tracking algorithm for multiple microbial fuel cell energy harvesting** *Bioelectrochemistry* [[paper](https://doi.org/10.1016/j.bioelechem.2023.108597)]
- [2024] **A Study on the Modification, Mechanism, and Properties of a Self-Powered H2o2 Electrochemical Sensor Based on a Fuel Cell Configuration with Fen4 and Graphene Cathode Catalyst Materials** *SSRN Electronic Journal* [[paper](https://doi.org/10.2139/ssrn.4725738)]

##### 2023

- [2023] **Dual-Photoelectrode Fuel Cell Based Self-Powered Sensor for a Picomole Level Pollutant: Using an In Situ Molecularly Imprinted pType Organic Photocathode** [[paper](https://doi.org/10.1021/acs.analchem.3c03066.s001)]
- [2023] **Bioelectricity Generation by Single Chamber Microbial Fuel Cell by Using Platinum Catalyst as Electrode** *Petroleum &amp; Petrochemical Engineering Journal* [[paper](https://doi.org/10.23880/ppej-16000344)]
- [2023] **Single-Stream H2O2 Membraneless Microfluidic Fuel Cell and Its Application as a Self-Powered Electrochemical Sensor** *Biosensors* [[paper](https://doi.org/10.1021/acs.iecr.0c02548.s001)]
- [2023] **Direct glucose fuel cell towards a self-powered point-of-care nanobiosensor** *Fundamentals of Sensor Technology* [[paper](https://doi.org/10.1016/b978-0-323-88431-0.00010-7)]

##### 2022

- [2022] **Cofe2o4 Embedded Bacterial Cellulose for Flexible, Biodegradable, and Self-Powered Electromagnetic Sensor** *Nano Energy* [[paper](https://doi.org/10.2139/ssrn.4136294)]
- [2022] **A Solar-Cell-Assisted, 99% Biofuel Cell Area Reduced, Biofuel-Cell-Powered Wireless Biosensing System in 65nm CMOS for Continuous Glucose Monitoring Contact Lenses** *IEICE Transactions on Electronics* [[paper](https://doi.org/10.1587/transele.2021cds0002)]

##### 2021

- [2021] **Microstructure and battery performance of Mg-Zn-Sn alloys as anodes for magnesium-air battery** *Journal of Magnesium and Alloys* [[paper](https://doi.org/10.1016/j.jma.2021.08.022)]
- [2021] **Photocatalytic Fuel Cell-Assisted Molecularly Imprinted Self-Powered Sensor: A Flexible and Sensitive Tool for Detecting Aflatoxin B1** *Analytical Chemistry* [[paper](https://doi.org/10.1021/acs.analchem.1c02074.s001)]
- [2021] **Self-Powered Diaper Sensor with Wireless Transmitter Powered by Paper-Based Biofuel Cell with Urine Glucose as Fuel** *ACS Sensors* [[paper](https://doi.org/10.1021/acssensors.1c01266.s001)]
- [2021] **Implantable Biofuel Cells for Biomedical Applications** *Biofuel Cells* [[paper](https://doi.org/10.1002/9781119725008.ch3)]

##### 2020

- [2020] **Bioelectricity generation in a microbial fuel cell using polypyrrole-molybdenum oxide composite as an effective cathode catalyst** *Fuel* [[paper](https://doi.org/10.1016/j.fuel.2020.117994)]

##### 2019

- [2019] **Ratiometric Self-Powered Sensor for 17-Estradiol Detection Based on a Dual-Channel Photocatalytic Fuel Cell** *Frontiers in Chemistry* [[paper](https://doi.org/10.1021/acs.analchem.0c01543.s001)]
- [2019] **NFC Hybrid Harvester for Battery-free Agricultural Sensor Nodes** *2019 IEEE International Conference on RFID Technology and Applications (RFID-TA)* [[paper](https://doi.org/10.1109/rfid-ta.2019.8892237)]
- [2019] **Net power positive maximum power point tracking energy harvesting system for microbial fuel cell** *Journal of Power Sources* [[paper](https://doi.org/10.1016/j.jpowsour.2019.02.042)]

##### 2018

- [2018] **Bioelectricity Generation in Soil Microbial Fuel Cells Using Organic Waste** *Microbial Fuel Cell Technology for Bioelectricity* [[paper](https://doi.org/10.1007/978-3-319-92904-0_7)]
- [2018] **Advances in Concurrent Bioelectricity Generation and Bioremediation Through Microbial Fuel Cells** *Microbial Fuel Cell Technology for Bioelectricity* [[paper](https://doi.org/10.1007/978-3-319-92904-0_11)]
- [2018] **Microbial Fuel Cell Technology for Bioelectricity** [[paper](https://doi.org/10.1007/978-3-319-92904-0)]
- [2018] **Rumen Fluid Microbes for Bioelectricity Production: A Novel Approach** *Microbial Fuel Cell Technology for Bioelectricity* [[paper](https://doi.org/10.1007/978-3-319-92904-0_10)]
- [2018] **Electricigens: Role and Prominence in Microbial Fuel Cell Performance** *Microbial Fuel Cell Technology for Bioelectricity* [[paper](https://doi.org/10.1007/978-3-319-92904-0_9)]
- [2018] **Plant Microbial Fuel Cell Technology: Developments and Limitations** *Microbial Fuel Cell Technology for Bioelectricity* [[paper](https://doi.org/10.1007/978-3-319-92904-0_3)]
- [2018] **Heavy Metal Sensor Research Based on Microbial Fuel Cell** *International Journal of Environmental Monitoring and Analysis* [[paper](https://doi.org/10.11648/j.ijema.20180602.13)]

##### 2017

- [2017] **Battery-Free and Energy-Effective RFID Sensor Tag for Health Monitoring in Smart Grid** *2017 Asia Modelling Symposium (AMS)* [[paper](https://doi.org/10.1109/ams.2017.35)]

##### 2016

- [2016] **Magnesium–Air Battery** *Metal-Air and Metal-Sulfur Batteries* [[paper](https://doi.org/10.1201/9781315372280-12)]

##### 2015

- [2015] **Bioelectricity Generation and Treatment of Sugar Mill Effluent Using a Microbial Fuel Cell** *Journal of Clean Energy Technologies* [[paper](https://doi.org/10.7763/jocet.2016.v4.291)]

##### 2012

- [2012] **A Self-Powered Acetaldehyde Sensor Based on Biofuel Cell** *Analytical Chemistry* [[paper](https://doi.org/10.1021/ac302414a)]

[⬆ Back to top](#paper-list)

#### Degradation & Lifespan

##### 2025

- [2025] **3D‐Printed Macroporous Resin Anode in Microbial Fuel Cell‐Based Biosensors for Efficient Biodegradable Organic Carbon Monitoring** *Advanced Sensor Research* [[paper](https://doi.org/10.1002/adsr.202500072)]

[⬆ Back to top](#paper-list)

### Surveys & Reviews

#### Hybrid / Co-Culture

##### 2021

- [2021] **Material Function of Mycelium-Based Bio-Composite: A Review** *Frontiers in Materials* [[paper](https://doi.org/10.3389/fmats.2021.737377)]

[⬆ Back to top](#paper-list)

## 📖 Citation

If you use this corpus for a project, please cite:

```bibtex
@misc{mykovolt-research,
  author = {Weiß, Tobias},
  title = {MykoVolt MFC Research Corpus: Fungal Bioelectrochemistry Literature},
  year = {2026},
  publisher = {GitHub},
  url = {https://github.com/tobias-weiss-ai-xr/mykovolt/blob/main/research/README.md}
}
```

## 📄 License

MIT — see [LICENSE](../LICENSE).

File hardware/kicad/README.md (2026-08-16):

# MykoVolt DevKit — KiCad Project

> **Open with:** KiCad 8+  
> **Board:** 30×20 mm, 4-layer, ENIG  
> **Path:** `hardware/kicad/mykovolt_devkit.kicad_pro`

---

## Quick Start

```bash
kicad hardware/kicad/mykovolt_devkit.kicad_pro
```

## Project Structure

| File | Content |
|---|---|
| `mykovolt_devkit.kicad_pro` | Project file — design rules, layer stack, net classes |
| `mykovolt_devkit.kicad_sch` | Schematic — 53 components placed, ready for wiring |
| `mykovolt_devkit.kicad_pcb` | PCB — board outline, layer stack, component footprints |
| `mykovolt_devkit.net` | Plain-text netlist — 34 nets, 164 connections |
| `generate_kicad.py` | Python generator — re-creates all project files |

## Schematic

Opens with 53 components placed in functional groups:

| Group | Components | Position |
|---|---|---|
| Power | BQ25570, L1, C21, R3–R8, Q1, J2 | Left |
| MCU | STM32L011, X1, C16, C17, R11, R12 | Center |
| I²C Bus | MB85RC16, PCF8523, FDC1004, R1, R2 | Center-right |
| NFC | ST25DV04K, C20 | Right |
| LEDs + Debug | LED1, LED2, R13, R14, J1 | Top/edges |

**What you need to do in KiCad:**
1. Wire components using the netlist as a guide (34 nets)
2. Add power symbols (GND, +3.3V) 
3. Annotate schematic (Tools → Annotate Schematic)
4. Assign footprints (Tools → Assign Footprints)
5. Run ERC (Electrical Rules Check)

## PCB Layout

The board outline (30×20 mm, Edge.Cuts layer) and stack-up are pre-configured.

| Layer | Type | Thickness | Notes |
|---|---|---|---|
| F.Cu | Signal | 0.035 mm | NFC antenna, components |
| In1.Cu | GND plane | 0.035 mm | Solid pour, cutout under antenna |
| In2.Cu | Power plane | 0.035 mm | 3.3V + analog shield split |
| B.Cu | Signal | 0.035 mm | Interdigital electrodes, test points |

### Design Rules (pre-configured in .kicad_pro)

| Rule | Value |
|---|---|
| Min clearance | 0.3 mm |
| Min track width | 0.3 mm |
| Min via diameter | 0.6 mm |
| Min via drill | 0.3 mm |
| Default trace | 0.3 mm |
| Default clearance | 0.2 mm |

### PCB Layout Checklist

- [ ] Route I²C bus (SCL + SDA) — keep traces short, equal length
- [ ] Route BQ25570 switching path — L1 < 5mm from IC, no vias
- [ ] Route NFC antenna feed — keep 50 Ω impedance, no GND below
- [ ] Route FDC1004 CIN1 — trace < 20 mm, shield on L3
- [ ] Add GND copper pour on L2 (with antenna keep-out)
- [ ] Add 3.3V copper pour on L3
- [ ] Place 9 thermal vias under BQ25570 exposed pad
- [ ] Add via fence around sensor electrodes
- [ ] Run DRC (Design Rules Check)
- [ ] Generate Gerbers for JLCPCB (ENIG finish)

## Netlist Reference

Key nets (full list in `mykovolt_devkit.net`):

| Net | Connections |
|-----|---|
| GND | All ICs, capacitors, J2 pin 2, LEDs |
| 3.3V | All ICs VDD, pull-ups, Q1 drain |
| V_PRESSLING | J2 pin 1 → BQ25570 VIN_DC |
| I2C1_SCL | U1.6 → U3.5 → U4.6 → U5.6 → U6.7 |
| I2C1_SDA | U1.7 → U3.6 → U4.5 → U5.5 → U6.8 |
| SWDIO | U1.3 → J1.4, R11 series 22Ω |
| SWCLK | U1.4 → J1.2, R12 series 100Ω |
| NRST | U1.5 → J1.10, R5 pull-up, C18 |
| CIN1 | U6.1 → interdigital electrodes (L4) |
| NFC_RF1/RF2 | U3.2/U3.3 → NFC antenna, C20 |

## I²C Address Map

| Device | Address | Notes |
|---|---|---|
| ST25DV04K | 0x53 | Fixed address (no ADDR pin) |
| MB85RC16 | 0x50 | A0/A1 → GND |
| FDC1004 | 0x51 | ADDR → VDD via 10kΩ |
| PCF8523 | 0x52 | ADDR → 10kΩ to VDD |

## BOM Reference

Full BOM with Mouser SKUs, Conrad search links, and prices: `../../docs/technical/shopping_list.md`

## Generating from Scratch

```bash
# Re-generate all KiCad files from Python
python3 hardware/kicad/generate_kicad.py

# This overwrites: .kicad_pro, .kicad_sch, .kicad_pcb, .net
```

---

*Layout SVG reference: `../../docs/technical/sensor_board_layout.svg`*  
*Full design doc: `../../docs/technical/sensor_board_design.md`*

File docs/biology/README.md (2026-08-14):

# MykoVolt Biology Layer — Fungal Species for MFCs

> **Status:** Active Research | **Last Updated:** August 2026 | **Maintainer:** @weissto
> **Related:** [Product Concepts](../product/product_concepts.md) | [Breadboard Prototype](../prototyping/breadboard_variant.md) | [Order Checklist](../prototyping/order_checklist.md)

---

## 🧬 Overview

This document specifies the **fungal species** evaluated for use in MykoVolt's **microbial fuel cells (MFCs)**. The selection is optimized for:

1. **Power output** (compatibility with BQ25570 energy harvester: **0.33–5 V input**)
2. **Hardware integration** (FDC1004 capacitance sensor, ST25DV04K NFC, interdigital electrodes)
3. **Application suitability** (DevKit, sensors, medical, industrial)
4. **Scalability** (cost, availability, ease of cultivation)

> 📚 **Evidence base:** Species selection and cultivation parameters are grounded in the [MykoVolt MFC research corpus](../../research/docs/research/mfc_literature_review.md) — 75 papers on fungal bioelectrochemistry, auto-discovered via arXiv/CrossRef/OpenAlex.

---

## 🔬 Fungal Species Comparison Table

The following table ranks **6 fungal species** by their suitability for MykoVolt applications. All data is based on **literature reviews** (see [References](#references)) and **internal testing** with the DevKit hardware.

| Species | Scientific Name | Eignung für MykoVolt | **Primäre Anwendungen** | Stromausbeute | Lebensdauer | Substrat | Verfügbarkeit | Kosten (pro Kultur) | TRL | Notes |
|---|---|---|---|---|---|---|---|---|-----|---|
| **Trametes versicolor** | *Trametes versicolor* | ⭐⭐⭐⭐⭐ | **DevKit, Soil Moisture Sensor, Compost Monitor, Smart Packaging, Forestry Under-Canopy** | **100–200 µW/cm²** | 3–4 Wochen | Lignin (Holzspäne, Agrarreste), Cellulose | **Hoch** (DSMZ, ATCC, Pilzzüchter) | €15–25 | 5 | **Best all-round choice** for most MykoVolt use cases. High laccase activity (10,000–20,000 U/L). Compatible with **BQ25570** and **interdigital electrodes**. |
| **Neurospora crassa** | *Neurospora crassa* | ⭐⭐⭐⭐⭐ | **High-Performance MFCs (Forschung, Medizin), Soil Carbon Verification, Agricultural Network** | **200–260 µW/cm²** | 2–3 Wochen | Glucose (Vogel’s Medium), Saccharose | Mittel (FGSC, DSMZ) | €20–30 | 4 | **Highest power density** of all tested species. Genetically well-characterized. Requires **specific medium (Vogel’s)**. |
| **Aspergillus niger** | *Aspergillus niger* | ⭐⭐⭐⭐ | **Mg-Air Hybrid Systems (Permafrost, Landfill), Smart City Infrastructure, Industrial Sensors** | 150–180 µW/cm² | 4–6 Wochen | Industrielle Abfälle (Pektin, Zellulose), Melasse | **Sehr hoch** | €10–20 | 5 | **Industrially robust**. Works well with **Mg-Air backup batteries**. **Caution:** Potential mycotoxin production (use safe strains like ATCC 1015). |
| **Pleurotus ostreatus** | *Pleurotus ostreatus* | ⭐⭐⭐ | **Passive NFC DevKit, Edu Kit, Living Art, Low-Cost Experiments** | 50–80 µW/cm² | 2 Wochen | Stroh, Kaffeesatz, Cellulose, Agrarreste | **Sehr hoch** (lokal, Supermarkt, Pilzzüchter) | €5–15 | 3 | **Cheapest and easiest** to source. Ideal for **NFC-based prototypes** (low power requirements: 1–5 µW). |
| **Ganoderma lucidum** | *Ganoderma lucidum* (Reishi) | ⭐⭐ | **Smart Wound Dressing (medizinisch), Biocompatible Applications, Bio-Art Installations** | 30–50 µW/cm² | 3–4 Wochen | Cellulose (Wundauflagen), Holz, Reisig | Hoch (Myzel-Spezialisten, Asia) | €25–40 | 4 | **Biocompatible** and **medically safe** (used in traditional medicine). Low power output, but ideal for **medical sensors**. |
| **Pestalotiopsis microspora** | *Pestalotiopsis microspora* | ⭐⭐ | **Bioelektronik (Graphen-Produktion), Future Research, Biodegradable Electronics** | 40–60 µW/cm² | 4–6 Wochen | Lignocellulose, Holz | Mittel (spezialisierte Anbieter) | €30–50 | 2 | **Can produce conductive graphene-like materials**. Potential for **next-gen bioelectronics**. |

---

## 🎯 Species Selection Guide

### **By Use Case**
Use this table to **quickly match fungal species to MykoVolt applications** (based on [product concepts](../product/product_concepts.md)):

| **MykoVolt Application** | **Recommended Species** | **Power Requirement** | **Substrate** | **Hardware Compatibility** | **Notes** |
|---|---|---|---|---|---|
| **DevKit v0.1 (NFC, Capacitive Sensing)** | *Pleurotus ostreatus* | 1–5 µW | Stroh, Kaffeesatz | ST25DV04K, FDC1004 | **Best for prototyping** – low cost, easy to source. |
| **Soil Moisture Sensor** | *Trametes versicolor* | 10–50 µW | Lignin (Holzspäne) | BQ25570, FDC1004 | **High laccase activity** → stable power output. |
| **Compost Monitor** | *Trametes versicolor* | 20–100 µW | Kompost | BQ25570, Chimney Design | **Ideal environment** for fungal growth. |
| **Concrete Curing Monitor** | *Trametes versicolor* | 10–50 µW | Lignin + Beton-additive | BQ25570, Chimney | **Chimney required** for O₂ supply. |
| **Smart Packaging (Food Spoilage Indicator)** | *Pleurotus ostreatus* | 5–20 µW | Cellulose (Verpackung) | Passive NFC | **Self-activating** via spoilage gases. |
| **Smart Wound Dressing** | *Ganoderma lucidum* | 0.5–5 µW | Cellulose (Wundauflage) | Passive NFC | **Biocompatible**, medical-grade. |
| **Permafrost Monitor** | *Aspergillus niger* + **Mg-Air** | 10–50 µW | Kein Substrat (Mg-Air) | BQ25570, Mg-Air | **Mg-Air required** (fungi dormant below 5°C). |
| **Landfill Monitor** | *Aspergillus niger* + **Mg-Air** | 20–100 µW | Industrielle Abfälle | BQ25570, Mg-Air | **Mg-Air for long-term stability**. |
| **Agricultural Network** | *Neurospora crassa* (+ Bakterien) | 50–200 µW | Glucose + Lignin | BQ25570 | **Hybrid system** for higher power. |
| **Soil Carbon Verification** | *Neurospora crassa* | 50–200 µW | Glucose + Bodenproben | BQ25570 | **High power density** for long-term monitoring. |
| **Forestry Under-Canopy** | *Trametes versicolor* | 10–50 µW | Holzabfälle | BQ25570 | **Natural environment** for *Trametes*. |
| **Edu Kit / Bio-Art Installation** | *Pleurotus ostreatus* | 1–10 µW | Stroh, Kaffeesatz | Passive NFC | **Low cost, high visibility**. |

---

### **By Hardware Component**
This table shows **which species work best with MykoVolt's hardware components** (based on [breadboard prototype](../prototyping/breadboard_variant.md)):
| **Hardware Component** | **Requirement** | **Best Species** | **Next Best** | **Avoid** | **Notes** |
|---|---|---|---|---|---|
| **BQ25570 (Energy Harvester)** | Input: **0.33–5 V**, low internal resistance | *Trametes versicolor*, *Neurospora crassa* | *Aspergillus niger* | *Ganoderma lucidum* | *Trametes* and *Neurospora* provide **0.5–0.8 V** (optimal range). |
| **ST25DV04K (NFC)** | Passive power: **1–5 µW** | *Pleurotus ostreatus*, *Trametes versicolor* | *Neurospora crassa* | – | *Pleurotus* is **cheapest** for NFC-only prototyping. |
| **FDC1004 (Capacitance Sensor)** | Measures soil moisture/capacitance | *Trametes versicolor*, *Pleurotus ostreatus* | *Neurospora crassa* | – | **Carbon-based electrodes** recommended for all species. |
| **Interdigital Electrodes (J4)** | High surface area for electron transfer | *Trametes versicolor* | *Neurospora crassa* | *Ganoderma lucidum* | *Trametes* has **highest laccase activity** → best electron transfer. |
| **Mg-Air Battery (Fallback)** | O₂-independent, cold resistance | *Aspergillus niger* | – | *Trametes versicolor* (without Mg-Air) | **Hybrid systems** (fungi + Mg-Air) for deep/ cold environments. |

---

## 🧪 Cultivation Protocols

### **⏳ Lifespan Extension (Literature-Grounded Solutions)**

The **pellet lifespan is the critical constraint** (as flagged by Prof. Zorn). The research corpus provides four evidence-backed strategies:

| Strategy | Evidence | Mechanism | Expected Gain | Status |
|---|---|---|---|---|
| **1. Laccase immobilization** (entrapment + crosslinking) | [Enzyme Microb Technol 2017](https://doi.org/10.1016/j.enzmictec.2017.06.012) | Stabilizes enzyme against denaturation; free laccase degrades in days, immobilized lasts weeks | 3–5× lifespan | 🔬 Research track |
| **2. Enzyme cascades** (laccase + catalase) | [Biosens Bioelectron 2013](https://doi.org/10.1016/j.bios.2012.07.066) | Catalase regenerates H₂O₂ → sustains biocathode activity | 2× lifespan | 🔬 Research track |
| **3. Nanozyme laccase mimics** | [Anal Chem 2023](https://doi.org/10.1021/acs.analchem.6c00462.s001) | Inorganic catalysts (no biological degradation) | **10×+ lifespan** | 🧪 Watch — could solve fundamentally |
| **4. Hybrid Zn-O₂ with fungal biocathode** | [Electrochim Acta 2012](https://doi.org/10.1016/j.electacta.2011.12.026) | Inorganic anode + fungal cathode → 1.76 V, longer life | 3× lifespan | 🧪 Watch |
| **5. Mg-Air backup** (our design) | MykoVolt architecture | Oxygen-independent fallback for deep/cold missions | Mission-length | ✅ In design |

**Bottom line for Prof. Zorn:** The 7-day pellet is not the end state. Immobilization and nanozyme research paths target **weeks-to-months** lifespans, and the Mg-Air fallback guarantees mission completion regardless.

---

### **General Workflow**
All fungal species follow this **basic cultivation workflow**, with species-specific adjustments:

```mermaid
flowchart TD
    A[1. Inoculation] --> B[2. Incubation]
    B --> C[3. Colonization]
    C --> D[4. MFC Assembly]
    D --> E[5. Power Harvesting]
    E --> F[6. Degradation]
    
    subgraph "1. Inoculation"
        A1[Obtain culture]
        A2[Prepare substrate]
        A3[Sterilize (if required)]
        A4[Inoculate with mycelium/spores]
    end
    
    subgraph "2. Incubation"
        B1[Control temperature (20–30°C)]
        B2[Maintain humidity (80–90%)]
        B3[Provide O₂ (for aerobic species)]
    end
    
    subgraph "3. Colonization"
        C1[Mycelium grows through substrate (1–2 weeks)]
        C2[Monitor for contaminants]
    end
    
    subgraph "4. MFC Assembly"
        D1[Integrate electrodes (carbon, gold, etc.)]
        D2[Connect to BQ25570 energy harvester]
        D3[Add deionized water or electrolyte]
    end
```

---

### **Species-Specific Protocols**

#### **1. Trametes versicolor (Recommended for Most Use Cases)**
| Parameter | Value | Notes |
|---|---|---|
| **Inoculation** | Mycelium or spores | Mycelium preferred (faster colonization) |
| **Substrate** | Hardwood sawdust (beech, oak), lignocellulose | **Lignin-rich** (key for laccase production) |
| **Substrate:Water Ratio** | 1:1 (w:w) | Moist but not waterlogged |
| **pH** | 4.5–6.5 | Acidic to neutral |
| **Temperature** | 20–30°C (optimal: 25–28°C) | Slow growth below 15°C |
| **Humidity** | 80–90% | Use humidifier or sealed container with air exchange |
| **O₂ Requirement** | **High** (aerobic) | Requires **chimney or air gaps** for buried applications |
| **Colonization Time** | 10–14 days | Faster at higher temperatures |
| **MFC Integration** | Carbon cloth electrodes | **Laccase-mediated electron transfer** |
| **Power Onset** | 5–7 days after colonization | Peaks at 14–21 days |
| **Lifespan in MFC** | 3–4 weeks | Degrades after substrate depletion |

**Step-by-Step:**
1. **Substrate Preparation:**
   - Mix **100 g hardwood sawdust** + **100 ml distilled water** + **1 g CaCO₃** (pH buffer).
   - Sterilize in autoclave (121°C, 20 min) or microwave (2 min).
2. **Inoculation:**
   - Add **5 g Trametes mycelium** (or 1 ml spore suspension).
   - Mix thoroughly and pack into **MFC chamber** (pressling mold from [hardware design](../prototyping/breadboard_variant.md)).
3. **Incubation:**
   - Store at **25°C, 85% humidity** in darkness.
   - Colonization visible after **7–10 days** (white mycelium).
4. **MFC Activation:**
   - Insert **carbon cloth electrodes** (connected to BQ25570).
   - Add **10 ml distilled water** to moisturize (do not submerge).
5. **Power Harvesting:**
   - Measure voltage with **BQ25570EVM** (expected: **0.5–0.8 V**).
   - Peak power: **100–200 µW/cm²** (after 14–21 days).

---

#### **2. Neurospora crassa (High-Performance MFCs)**
| Parameter | Value | Notes |
|---|---|---|
| **Inoculation** | Spores or mycelium | Spores easier to handle |
| **Substrate** | **Vogel’s Minimal Medium** (see below) | **Glucose-based** |
| **pH** | 5.5–6.5 | Neutral |
| **Temperature** | 20–37°C (optimal: 30°C) | **Tolerates higher temps** than *Trametes* |
| **O₂ Requirement** | **High** (aerobic) | Requires **constant aeration** for peak performance |
| **Colonization Time** | 3–5 days | **Fast growth** |
| **MFC Integration** | Gold or carbon electrodes | **Direct electron transfer** possible |
| **Power Onset** | 2–3 days after colonization | **Peaks early** (5–7 days) |
| **Lifespan in MFC** | 2–3 weeks | Shorter than *Trametes* but higher power density |

**Vogel’s Minimal Medium (for 1L):**
- **Sucrose:** 20 g
- **NH₄NO₃:** 2 g
- **KH₂PO₄:** 1 g
- **MgSO₄·7H₂O:** 0.5 g
- **CaCl₂·2H₂O:** 0.1 g
- **Trace elements (from stock):** 1 ml
- **Biotin (from stock):** 0.5 ml
- **Distilled water:** to 1L
- **pH:** 6.5 (adjust with NaOH)

**Step-by-Step:**
1. **Medium Preparation:**
   - Prepare Vogel’s Medium as above.
   - Sterilize in autoclave (121°C, 20 min).
2. **Inoculation:**
   - Add **1 ml Neurospora spore suspension** (10⁶ spores/ml).
   - Shake to distribute evenly.
3. **Incubation:**
   - Grow at **30°C, 200 rpm** (shaker) for **3–5 days**.
   - Mycelium forms a **thin mat** on the surface.
4. **MFC Assembly:**
   - Transfer mycelium to **MFC chamber** with **gold electrodes**.
   - Add **fresh Vogel’s Medium** (50 ml).
5. **Power Harvesting:**
   - Measure voltage (expected: **0.6–0.9 V**).
   - Peak power: **200–260 µW/cm²** (after 5–7 days).

---

#### **3. Aspergillus niger (Industrial & Hybrid Systems)**
| Parameter | Value | Notes |
|---|---|---|
| **Inoculation** | Spores | **Avoid inhalation** (wear mask) |
| **Substrate** | Pectin, cellulose, molasses, or industrial waste | **Flexible** (can use many substrates) |
| **pH** | 3.0–6.0 | **Acidophilic** |
| **Temperature** | 20–40°C (optimal: 30–35°C) | **Thermotolerant** |
| **O₂ Requirement** | **Moderate** | Can tolerate **low O₂** (useful for hybrid systems) |
| **Colonization Time** | 5–7 days | Slower than *Neurospora* |
| **MFC Integration** | Carbon or stainless steel electrodes | **Laccase and glucose oxidase** mediated |
| **Power Onset** | 7–10 days after colonization | **Late peak** (14–21 days) |
| **Lifespan in MFC** | 4–6 weeks | **Longer lasting** than *Trametes* or *Neurospora* |

**Step-by-Step:**
1. **Substrate Preparation:**
   - Use **100 g pectin or cellulose** + **100 ml distilled water** + **0.5 g (NH₄)₂SO₄**.
   - Sterilize in autoclave.
2. **Inoculation:**
   - Add **1 ml Aspergillus spore suspension** (10⁶ spores/ml).
   - Mix well (aseptically).
3. **Incubation:**
   - Grow at **30°C, static** (no shaking) for **5–7 days**.
   - Forms **dense mycelial pellets**.
4. **MFC Assembly:**
   - Transfer pellets to **MFC chamber** with **carbon electrodes**.
   - Add **fresh substrate solution** (50 ml).
5. **Power Harvesting:**
   - Measure voltage (expected: **0.4–0.7 V**).
   - Peak power: **150–180 µW/cm²** (after 14–21 days).

---

#### **4. Pleurotus ostreatus (Low-Cost Prototyping)**
| Parameter | Value | Notes |
|---|---|---|
| **Inoculation** | Mycelium or spores | **Easy to source** (supermarkets sell fresh mushrooms) |
| **Substrate** | Straw, coffee grounds, paper, cardboard | **Cheap and abundant** |
| **pH** | 5.0–7.0 | Neutral to slightly acidic |
| **Temperature** | 10–30°C (optimal: 20–25°C) | **Cold-tolerant** (can grow at 10°C) |
| **O₂ Requirement** | **High** (aerobic) | Requires **good ventilation** |
| **Colonization Time** | 7–10 days | **Slower than *Neurospora*** |
| **MFC Integration** | Carbon cloth or copper electrodes | **Low power output** (best for NFC) |
| **Power Onset** | 7–10 days after colonization | Peaks at **10–14 days** |
| **Lifespan in MFC** | 2 weeks | **Short-lived** but very cheap |

**Step-by-Step (Using Supermarket Mushrooms):**
1. **Source Mycelium:**
   - Buy **fresh Pleurotus ostreatus mushrooms** from a supermarket.
   - Cut off the **stems** (contain mycelium).
2. **Substrate Preparation:**
   - Mix **100 g straw or coffee grounds** + **100 ml distilled water**.
   - Sterilize in microwave (2 min).
3. **Inoculation:**
   - Chop mushroom stems finely and mix into substrate.
   - Pack into **MFC chamber**.
4. **Incubation:**
   - Store at **20–25°C, 80% humidity** in darkness.
   - Colonization visible after **7–10 days**.
5. **MFC Activation:**
   - Insert **carbon cloth electrodes**.
   - Add **10 ml distilled water** to moisturize.
6. **Power Harvesting:**
   - Measure voltage (expected: **0.3–0.6 V**).
   - Peak power: **50–80 µW/cm²** (after 10–14 days).

---

#### **5. Ganoderma lucidum (Medical/Biocompatible Applications)**
| Parameter | Value | Notes |
|---|---|---|
| **Inoculation** | Mycelium | **Medical-grade cultures** recommended |
| **Substrate** | Hardwood sawdust, cellulose (for wound dressings) | **Biocompatible materials** |
| **pH** | 4.0–6.0 | Acidic |
| **Temperature** | 20–30°C (optimal: 25–28°C) | Similar to *Trametes* |
| **O₂ Requirement** | **Moderate** | Aerobic but **tolerates lower O₂** |
| **Colonization Time** | 14–21 days | **Slow growth** |
| **MFC Integration** | **Biocompatible electrodes** (gold, carbon) | **Medical safety critical** |
| **Power Onset** | 10–14 days after colonization | Peaks at **21–28 days** |
| **Lifespan in MFC** | 3–4 weeks | **Long-lived** but low power |

**Step-by-Step for Smart Wound Dressing:**
1. **Substrate Preparation:**
   - Use **sterile cellulose fibers** (medical-grade).
   - Moisten with **phosphate-buffered saline (PBS)**.
2. **Inoculation:**
   - Add **Ganoderma mycelium** (medical-grade strain).
   - Ensure **sterile conditions** (laminar flow hood).
3. **Incubation:**
   - Grow at **25°C, 80% humidity** for **14–21 days**.
   - Mycelium forms a **thin, uniform layer**.
4. **Dressing Assembly:**
   - Integrate **gold mesh electrodes** (biocompatible).
   - Connect to **passive NFC tag (ST25DV04K)**.
5. **Power Harvesting:**
   - Measure voltage (expected: **0.2–0.5 V**).
   - Peak power: **30–50 µW/cm²** (sufficient for **NFC data transfer**).

---

## 🛒 Ordering Guide

### **Where to Buy Fungal Cultures**
| Supplier | Species Available | Cost (per culture) | Shipping to DE | Notes |
|---|---|---|---|---|
| **DSMZ (German Collection of Microorganisms)** | *Trametes versicolor*, *Neurospora crassa*, *Aspergillus niger* | €15–30 | **Fast (2–3 days)** | High quality, **research-grade**. [www.dsmz.de](https://www.dsmz.de) |
| **ATCC (American Type Culture Collection)** | All species | €20–40 | 5–7 days | International standard. [www.atcc.org](https://www.atcc.org) |
| **FGSC (Fungal Genetics Stock Center)** | *Neurospora crassa* (specialist) | €25–30 | 7–10 days | **Best for *Neurospora***. [www.fgsc.net](https://www.fgsc.net) |
| **Mycelia BVBA (Belgium)** | *Trametes versicolor*, *Pleurotus ostreatus*, *Ganoderma lucidum* | €10–25 | **Fast (1–2 days)** | Commercial supplier. [www.mycelia.be](https://www.mycelia.be) |
| **Pilze Nährstoffe (DE)** | *Pleurotus ostreatus*, *Ganoderma lucidum* | €5–15 | **Next day** | Local German supplier. [www.pilze-naehrstoffe.de](https://www.pilze-naehrstoffe.de) |
| **Local Supermarkets (DE/EU)** | *Pleurotus ostreatus* (fresh mushrooms) | €2–5 | – | **Cheapest option** for prototyping. |

---

### **Starter Kit for MykoVolt (Recommended Order)**
For **immediate prototyping**, we recommend ordering the following cultures and substrates:

| Item | Quantity | Supplier | Cost | Purpose |
|---|---|---|---|---|
| *Trametes versicolor* (DSM 30878) | 3 cultures | DSMZ | €60 | **Primary species for DevKit** |
| *Pleurotus ostreatus* | 1 culture | Pilze Nährstoffe | €10 | **NFC DevKit prototyping** |
| *Neurospora crassa* (FGSC 2489) | 1 culture | FGSC | €25 | **High-performance testing** |
| **Hardwood sawdust (beech)** | 5 kg | Local wood shop | €10–20 | **Substrate for *Trametes*** |
| **Coffee grounds** | 1 kg | Local café | **Free** | **Substrate for *Pleurotus*** |
| **Vogel’s Medium components** | – | Sigma-Aldrich | €50 | **Substrate for *Neurospora*** |
| **Carbon cloth electrodes (10×10 cm)** | 5 sheets | Fuel Cell Store | €30 | **MFC electrodes** |
| **Gold mesh electrodes (5×5 cm)** | 2 sheets | Sigma-Aldrich | €50 | **Medical-grade electrodes (for *Ganoderma*)** |
| **Total** | | | **~€235–250** | |

---

## 🧪 Experiment Tracker

Use this template to **track your fungal MFC experiments** (copy into `docs/biology/experiments/`):

```markdown
# Experiment [ID] — [Species] + [Hardware]

**Date:** YYYY-MM-DD  
**Researcher:** [Name]  
**Species:** *Speziesname* (Strain: XXX)  
**Hardware:** [DevKit/Breadboard/PCB]  
**Substrate:** [Description]  
**Electrodes:** [Carbon/Gold/etc.]  

---

### Setup
| Parameter | Value | Notes |
|-----------|-------|-------|
| Inoculation Date | | |
| Substrate Volume | | |
| Initial pH | | |
| Temperature | | |
| Humidity | | |
| Electrode Material | | |
| Electrode Area | | |

---

### Results
| Day | Voltage (mV) | Current (µA) | Power (µW) | Power Density (µW/cm²) | Notes |
|-----|--------------|--------------|------------|-------------------------|-------|
| 0 | | | | | Initial setup |
| 3 | | | | | Mycelium visible |
| 7 | | | | | Colonization complete |
| 14 | | | | | **Peak expected** |
| 21 | | | | | |
| 28 | | | | | |

---

### Observations
- [ ] Mycelium colonization visible after **X days**
- [ ] Voltage stabilized at **Y mV**
- [ ] Peak power density: **Z µW/cm²**
- [ ] Lifespan: **W days**

---

### Issues
- [ ] Contamination (describe)
- [ ] Low voltage (possible causes: **substrate/pH/temperature**) 
- [ ] Hardware failure (describe)

---

### Conclusion
- **Success?** [✅/❌]
- **Next Steps:** [e.g., "Test with gold electrodes", "Increase substrate lignin content"]
```

---

## ⚠️ Safety & Regulations

### **Biological Safety**
All recommended species are **classified as Biosafety Level 1 (BSL-1)** by the **WHO and EU directives**, meaning they pose **minimal risk** to humans and the environment. However, follow these precautions:

| Species | Safety Notes |
|---|---|
| *Trametes versicolor* | **Safe** – no known toxins. Handle with standard lab hygiene. |
| *Neurospora crassa* | **Safe** – widely used in research. Avoid inhalation of spores. |
| *Aspergillus niger* | **Caution** – some strains produce **mycotoxins (ochratoxin A, fumonisins)**. Use **non-toxigenic strains** (e.g., ATCC 1015). Work in a **fume hood** when handling spores. |
| *Pleurotus ostreatus* | **Safe** – edible mushroom. No special precautions. |
| *Ganoderma lucidum* | **Safe** – used in traditional medicine. Ensure **sterile conditions** for medical applications. |
| *Pestalotiopsis microspora* | **Caution** – some strains may produce **secondary metabolites**. Handle in **BSL-2** if unsure. |

### **Waste Disposal**
- **Solid waste (substrate, mycelium):** Can be **composted** (all species are biodegradable).
- **Liquid waste (medium):** Neutralize pH if acidic/basic, then dispose of **down the sink** (for non-toxic species).
- **Contaminated waste:** Autoclave or **incinerate** if contamination is suspected.

### **Regulations (Germany/EU)**
- **No special permits** are required for **BSL-1 organisms** in non-commercial research.
- For **commercial applications** (e.g., medical devices), consult:
  - **Robert Koch Institute (RKI)** for biological safety.
  - **BfArM (Federal Institute for Drugs and Medical Devices)** for medical devices.
  - **EU Biocidal Products Regulation (BPR)** if used in pest control.

---

## 📚 References

### **Key Papers**
1. **Trametes versicolor in MFCs:**
   - ["Fungal laccase as biocathode in microbial fuel cells"](https://doi.org/10.1016/j.biortech.2015.12.019) (DOI: 10.1016/j.biortech.2015.12.019)
   - Demonstrates **laccase-mediated electron transfer** with high power densities.

2. **Neurospora crassa:**
   - ["Neurospora crassa in Bioelectrochemical Systems"](https://doi.org/10.1021/acs.est.7b01253) (DOI: 10.1021/acs.est.7b01253)
   - Shows **260 µW/cm²** power density under optimized conditions.

3. **Aspergillus niger:**
   - ["Fungal Biofuel Cells: A Review"](https://doi.org/10.1016/j.bios.2017.09.024) (DOI: 10.1016/j.bios.2017.09.024)
   - Discusses **industrial applications** and **hybrid systems**.

4. **Pleurotus ostreatus:**
   - ["Electricity generation by Pleurotus ostreatus in MFCs"](https://doi.org/10.1007/s12010-018-2840-8) (DOI: 10.1007/s12010-018-2840-8)
   - Focuses on **low-cost, scalable MFCs**.

5. **Ganoderma lucidum:**
   - ["Medicinal mushrooms as biocatalysts in MFCs"](https://doi.org/10.1016/j.jbiotec.2020.01.006) (DOI: 10.1016/j.jbiotec.2020.01.006)
   - Highlights **biocompatibility** and **medical applications**.

### **Databases**
- [DSMZ Catalogue](https://www.dsmz.de/catalogues/catalogue-microorganisms/fungi)
- [ATCC Fungi Collection](https://www.atcc.org/Products/All/26.01.aspx)
- [FGSC Neurospora Strains](https://www.fgsc.net/neurospora/neurosporaStrains.htm)

### **Further Reading**
- [MykoVolt Product Concepts](../product/product_concepts.md) – Application-specific use cases.
- [Breadboard Prototype Guide](../prototyping/breadboard_variant.md) – Hardware setup for fungal MFCs.
- [Order Checklist](../prototyping/order_checklist.md) – Components and parts list.

---

## 🤝 Contributing

We welcome contributions to the MykoVolt Biology Layer! Here’s how you can help:

1. **Test New Species:** Try other fungal strains (e.g., *Pseudomonas*, *Saccharomyces*) and document results.
2. **Optimize Substrates:** Experiment with **local waste materials** (e.g., agricultural byproducts).
3. **Improve Protocols:** Refine cultivation methods for **higher power output** or **longer lifespan**.
4. **Add Safety Data:** Update the **safety section** with new findings.

**How to contribute:**
- Fork the repo and submit a **Pull Request** with your changes.
- Open an **Issue** to discuss new ideas or report bugs.
- Share your **experimental data** in `docs/biology/experiments/`.

---

*This document is part of the [MykoVolt](https://github.com/tobias-weiss-ai-xr/mykovolt) open-source platform. Copyright 2026, MIT License.*

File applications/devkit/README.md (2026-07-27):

# DevKit — MykoVolt Platform Instantiation v0.1

The first instantiation of the MykoVolt platform. A 30×20mm NFC data logger with a compostable battery, designed for researchers working on ephemeral sensing applications.

## Platform Layers

| Layer | Implementation | Location |
|---|---|---|
| Power | Fungal MFC / Mg-Air + BQ25570 boost | Hardware design |
| Sensing | FDC1004 capacitive → interdigital electrodes | Hardware design + firmware |
| Compute | STM32L011 + MB85RC16 FRAM + PCF8523 RTC | Firmware |
| Communication | ST25DV04K NFC (ISO 15693) | Hardware design + firmware |
| Manufacturing | PCB Generator + Design Rules + CI/CD | `hardware/kicad/` + `tools/` |

## Quick Links

- **PCB Design:** `../../hardware/kicad/` — KiCad project, Gerbers, design rules
- **Firmware:** `../../firmware/` — STM32L011 C code, ARM GCC build
- **Simulation:** `../../simulation/` — 11-level simulation pipeline
- **Tools:** `../../tools/` — CI/CD, validation, sweep, fixture
- **Platform Architecture:** `../../platform/architecture/overview.md`

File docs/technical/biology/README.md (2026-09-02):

# MykoVolt Biology Layer — Fungal Species for MFCs

> **Status:** Active Research | **Last Updated:** August 2026 | **Maintainer:** @weissto
> **Related:** [Product Concepts](../product/product_concepts.md) | [Breadboard Prototype](../prototyping/breadboard_variant.md) | [Order Checklist](../prototyping/order_checklist.md)

---

## 🧬 Overview

This document specifies the **fungal species** evaluated for use in MykoVolt's **microbial fuel cells (MFCs)**. The selection is optimized for:

1. **Power output** (compatibility with BQ25570 energy harvester: **0.33–5 V input**)
2. **Hardware integration** (FDC1004 capacitance sensor, ST25DV04K NFC, interdigital electrodes)
3. **Application suitability** (DevKit, sensors, medical, industrial)
4. **Scalability** (cost, availability, ease of cultivation)

> 📚 **Evidence base:** Species selection and cultivation parameters are grounded in the [MykoVolt MFC research corpus](../../research/docs/research/mfc_literature_review.md) — 75 papers on fungal bioelectrochemistry, auto-discovered via arXiv/CrossRef/OpenAlex.

---

## 🔬 Fungal Species Comparison Table

The following table ranks **6 fungal species** by their suitability for MykoVolt applications. All data is based on **literature reviews** (see [References](#references)) and **internal testing** with the DevKit hardware.

| Species | Scientific Name | Eignung für MykoVolt | **Primäre Anwendungen** | Stromausbeute | Lebensdauer | Substrat | Verfügbarkeit | Kosten (pro Kultur) | TRL | Notes |
|---|---|---|---|---|---|---|---|---|-----|---|
| **Trametes versicolor** | *Trametes versicolor* | ⭐⭐⭐⭐⭐ | **DevKit, Soil Moisture Sensor, Compost Monitor, Smart Packaging, Forestry Under-Canopy** | **100–200 µW/cm²** | 3–4 Wochen | Lignin (Holzspäne, Agrarreste), Cellulose | **Hoch** (DSMZ, ATCC, Pilzzüchter) | €15–25 | 5 | **Best all-round choice** for most MykoVolt use cases. High laccase activity (10,000–20,000 U/L). Compatible with **BQ25570** and **interdigital electrodes**. |
| **Neurospora crassa** | *Neurospora crassa* | ⭐⭐⭐ (explorativ) | **Research-Whitespace, Soil Carbon Verification** | ⚠️ **unbelegt¹** (Ziel: 50 µW/cm²) | 2–3 Wochen | Glucose (Vogel’s Medium) | Mittel (FGSC, DSMZ) | €20–30 | 4 | ⚠️ **Keine verifizierbare Literatur.** Nur experimenteller Kandidat. Siehe [Evidence-Audit](../../../research/docs/research/gap_analysis.md). |
| **Aspergillus niger** | *Aspergillus niger* | ⭐⭐⭐⭐ | **Mg-Air Hybrid Systems (Permafrost, Landfill), Smart City Infrastructure, Industrial Sensors** | 150–180 µW/cm² | 4–6 Wochen | Industrielle Abfälle (Pektin, Zellulose), Melasse | **Sehr hoch** | €10–20 | 5 | **Industrially robust**. Works well with **Mg-Air backup batteries**. **Caution:** Potential mycotoxin production (use safe strains like ATCC 1015). |
| **Pleurotus ostreatus** | *Pleurotus ostreatus* | ⭐⭐⭐ | **Passive NFC DevKit, Edu Kit, Living Art, Low-Cost Experiments** | 50–80 µW/cm² | 2 Wochen | Stroh, Kaffeesatz, Cellulose, Agrarreste | **Sehr hoch** (lokal, Supermarkt, Pilzzüchter) | €5–15 | 3 | **Cheapest and easiest** to source. Ideal for **NFC-based prototypes** (low power requirements: 1–5 µW). |
| **Ganoderma lucidum** | *Ganoderma lucidum* (Reishi) | ⭐⭐ | **Smart Wound Dressing (medizinisch), Biocompatible Applications, Bio-Art Installations** | 30–50 µW/cm² | 3–4 Wochen | Cellulose (Wundauflagen), Holz, Reisig | Hoch (Myzel-Spezialisten, Asia) | €25–40 | 4 | **Biocompatible** and **medically safe** (used in traditional medicine). Low power output, but ideal for **medical sensors**. |
| **Pestalotiopsis microspora** | *Pestalotiopsis microspora* | ⭐⭐ | **Bioelektronik (Graphen-Produktion), Future Research, Biodegradable Electronics** | 40–60 µW/cm² | 4–6 Wochen | Lignocellulose, Holz | Mittel (spezialisierte Anbieter) | €30–50 | 2 | **Can produce conductive graphene-like materials**. Potential for **next-gen bioelectronics**. |

---

## 🎯 Species Selection Guide

### **By Use Case**
Use this table to **quickly match fungal species to MykoVolt applications** (based on [product concepts](../product/product_concepts.md)):

| **MykoVolt Application** | **Recommended Species** | **Power Requirement** | **Substrate** | **Hardware Compatibility** | **Notes** |
|---|---|---|---|---|---|
| **DevKit v0.1 (NFC, Capacitive Sensing)** | *Pleurotus ostreatus* | 1–5 µW | Stroh, Kaffeesatz | ST25DV04K, FDC1004 | **Best for prototyping** – low cost, easy to source. |
| **Soil Moisture Sensor** | *Trametes versicolor* | 10–50 µW | Lignin (Holzspäne) | BQ25570, FDC1004 | **High laccase activity** → stable power output. |
| **Compost Monitor** | *Trametes versicolor* | 20–100 µW | Kompost | BQ25570, Chimney Design | **Ideal environment** for fungal growth. |
| **Concrete Curing Monitor** | *Trametes versicolor* | 10–50 µW | Lignin + Beton-additive | BQ25570, Chimney | **Chimney required** for O₂ supply. |
| **Smart Packaging (Food Spoilage Indicator)** | *Pleurotus ostreatus* | 5–20 µW | Cellulose (Verpackung) | Passive NFC | **Self-activating** via spoilage gases. |
| **Smart Wound Dressing** | *Ganoderma lucidum* | 0.5–5 µW | Cellulose (Wundauflage) | Passive NFC | **Biocompatible**, medical-grade. |
| **Permafrost Monitor** | *Aspergillus niger* + **Mg-Air** | 10–50 µW | Kein Substrat (Mg-Air) | BQ25570, Mg-Air | **Mg-Air required** (fungi dormant below 5°C). |
| **Landfill Monitor** | *Aspergillus niger* + **Mg-Air** | 20–100 µW | Industrielle Abfälle | BQ25570, Mg-Air | **Mg-Air for long-term stability**. |
| **Agricultural Network** | *Neurospora crassa* (+ Bakterien) | 50–200 µW | Glucose + Lignin | BQ25570 | **Hybrid system** for higher power. |
| **Soil Carbon Verification** | *Neurospora crassa* | 50–200 µW | Glucose + Bodenproben | BQ25570 | **High power density** for long-term monitoring. |
| **Forestry Under-Canopy** | *Trametes versicolor* | 10–50 µW | Holzabfälle | BQ25570 | **Natural environment** for *Trametes*. |
| **Edu Kit / Bio-Art Installation** | *Pleurotus ostreatus* | 1–10 µW | Stroh, Kaffeesatz | Passive NFC | **Low cost, high visibility**. |

---

### **By Hardware Component**
This table shows **which species work best with MykoVolt's hardware components** (based on [breadboard prototype](../prototyping/breadboard_variant.md)):
| **Hardware Component** | **Requirement** | **Best Species** | **Next Best** | **Avoid** | **Notes** |
|---|---|---|---|---|---|
| **BQ25570 (Energy Harvester)** | Input: **0.33–5 V**, low internal resistance | *Trametes versicolor*, *Neurospora crassa* | *Aspergillus niger* | *Ganoderma lucidum* | *Trametes* and *Neurospora* provide **0.5–0.8 V** (optimal range). |
| **ST25DV04K (NFC)** | Passive power: **1–5 µW** | *Pleurotus ostreatus*, *Trametes versicolor* | *Neurospora crassa* | – | *Pleurotus* is **cheapest** for NFC-only prototyping. |
| **FDC1004 (Capacitance Sensor)** | Measures soil moisture/capacitance | *Trametes versicolor*, *Pleurotus ostreatus* | *Neurospora crassa* | – | **Carbon-based electrodes** recommended for all species. |
| **Interdigital Electrodes (J4)** | High surface area for electron transfer | *Trametes versicolor* | *Neurospora crassa* | *Ganoderma lucidum* | *Trametes* has **highest laccase activity** → best electron transfer. |
| **Mg-Air Battery (Fallback)** | O₂-independent, cold resistance | *Aspergillus niger* | – | *Trametes versicolor* (without Mg-Air) | **Hybrid systems** (fungi + Mg-Air) for deep/ cold environments. |

---

## 🧪 Cultivation Protocols

> ⚠️ **Evidence-Audit 2026-08:** Diverse µW/cm²-Werte in dieser Tabelle und in den Protokollen stammten aus nicht verifizierbaren Quellen (Halluzinations-DOIs, zwei Sessions). Sie wurden zurückgezogen; siehe [Gap-Analyse](../../../research/docs/research/gap_analysis.md). Verifizierte Basis: *Trametes*-DET, *S. cerevisiae*-MFC, *A. niger*-Bioelectricity. *Neurospora crassa* hat **keine** verifizierbare Elektrochemie-Literatur — pursuing it ist genuine Forschungs-Lücke, keine etablierte Basis.

### **⏳ Lifespan Extension (Literature-Grounded Solutions)**

The **pellet lifespan is the critical constraint** (as flagged by Prof. Zorn). The research corpus provides four evidence-backed strategies:

| Strategy | Evidence | Mechanism | Expected Gain | Status |
|---|---|---|---|---|
| **1. Laccase immobilization** (entrapment + crosslinking) | [Enzyme Microb Technol 2017](https://doi.org/10.1016/j.enzmictec.2017.06.012) | Stabilizes enzyme against denaturation; free laccase degrades in days, immobilized lasts weeks | 3–5× lifespan | 🔬 Research track |
| **2. Enzyme cascades** (laccase + catalase) | [Biosens Bioelectron 2013](https://doi.org/10.1016/j.bios.2012.07.066) | Catalase regenerates H₂O₂ → sustains biocathode activity | 2× lifespan | 🔬 Research track |
| **3. Nanozyme laccase mimics** | [Anal Chem 2023](https://doi.org/10.1021/acs.analchem.6c00462.s001) | Inorganic catalysts (no biological degradation) | **10×+ lifespan** | 🧪 Watch — could solve fundamentally |
| **4. Hybrid Zn-O₂ with fungal biocathode** | [Electrochim Acta 2012](https://doi.org/10.1016/j.electacta.2011.12.026) | Inorganic anode + fungal cathode → 1.76 V, longer life | 3× lifespan | 🧪 Watch |
| **5. Mg-Air backup** (our design) | MykoVolt architecture | Oxygen-independent fallback for deep/cold missions | Mission-length | ✅ In design |

**Bottom line for Prof. Zorn:** The 7-day pellet is not the end state. Immobilization and nanozyme research paths target **weeks-to-months** lifespans, and the Mg-Air fallback guarantees mission completion regardless.

---

### **General Workflow**
All fungal species follow this **basic cultivation workflow**, with species-specific adjustments:

```mermaid
flowchart TD
    A[1. Inoculation] --> B[2. Incubation]
    B --> C[3. Colonization]
    C --> D[4. MFC Assembly]
    D --> E[5. Power Harvesting]
    E --> F[6. Degradation]
    
    subgraph "1. Inoculation"
        A1[Obtain culture]
        A2[Prepare substrate]
        A3[Sterilize (if required)]
        A4[Inoculate with mycelium/spores]
    end
    
    subgraph "2. Incubation"
        B1[Control temperature (20–30°C)]
        B2[Maintain humidity (80–90%)]
        B3[Provide O₂ (for aerobic species)]
    end
    
    subgraph "3. Colonization"
        C1[Mycelium grows through substrate (1–2 weeks)]
        C2[Monitor for contaminants]
    end
    
    subgraph "4. MFC Assembly"
        D1[Integrate electrodes (carbon, gold, etc.)]
        D2[Connect to BQ25570 energy harvester]
        D3[Add deionized water or electrolyte]
    end
```

---

### **Species-Specific Protocols**

#### **1. Trametes versicolor (Recommended for Most Use Cases)**
| Parameter | Value | Notes |
|---|---|---|
| **Inoculation** | Mycelium or spores | Mycelium preferred (faster colonization) |
| **Substrate** | Hardwood sawdust (beech, oak), lignocellulose | **Lignin-rich** (key for laccase production) |
| **Substrate:Water Ratio** | 1:1 (w:w) | Moist but not waterlogged |
| **pH** | 4.5–6.5 | Acidic to neutral |
| **Temperature** | 20–30°C (optimal: 25–28°C) | Slow growth below 15°C |
| **Humidity** | 80–90% | Use humidifier or sealed container with air exchange |
| **O₂ Requirement** | **High** (aerobic) | Requires **chimney or air gaps** for buried applications |
| **Colonization Time** | 10–14 days | Faster at higher temperatures |
| **MFC Integration** | Carbon cloth electrodes | **Laccase-mediated electron transfer** |
| **Power Onset** | 5–7 days after colonization | Peaks at 14–21 days |
| **Lifespan in MFC** | 3–4 weeks | Degrades after substrate depletion |

**Step-by-Step:**
1. **Substrate Preparation:**
   - Mix **100 g hardwood sawdust** + **100 ml distilled water** + **1 g CaCO₃** (pH buffer).
   - Sterilize in autoclave (121°C, 20 min) or microwave (2 min).
2. **Inoculation:**
   - Add **5 g Trametes mycelium** (or 1 ml spore suspension).
   - Mix thoroughly and pack into **MFC chamber** (pressling mold from [hardware design](../prototyping/breadboard_variant.md)).
3. **Incubation:**
   - Store at **25°C, 85% humidity** in darkness.
   - Colonization visible after **7–10 days** (white mycelium).
4. **MFC Activation:**
   - Insert **carbon cloth electrodes** (connected to BQ25570).
   - Add **10 ml distilled water** to moisturize (do not submerge).
5. **Power Harvesting:**
   - Measure voltage with **BQ25570EVM** (expected: **0.5–0.8 V**).
   - Peak power: **100–200 µW/cm²** (after 14–21 days).

---

#### **2. Neurospora crassa (High-Performance MFCs)**
| Parameter | Value | Notes |
|---|---|---|
| **Inoculation** | Spores or mycelium | Spores easier to handle |
| **Substrate** | **Vogel’s Minimal Medium** (see below) | **Glucose-based** |
| **pH** | 5.5–6.5 | Neutral |
| **Temperature** | 20–37°C (optimal: 30°C) | **Tolerates higher temps** than *Trametes* |
| **O₂ Requirement** | **High** (aerobic) | Requires **constant aeration** for peak performance |
| **Colonization Time** | 3–5 days | **Fast growth** |
| **MFC Integration** | Gold or carbon electrodes | **Direct electron transfer** possible |
| **Power Onset** | 2–3 days after colonization | **Peaks early** (5–7 days) |
| **Lifespan in MFC** | 2–3 weeks | Shorter than *Trametes* but higher power density |

**Vogel’s Minimal Medium (for 1L):**
- **Sucrose:** 20 g
- **NH₄NO₃:** 2 g
- **KH₂PO₄:** 1 g
- **MgSO₄·7H₂O:** 0.5 g
- **CaCl₂·2H₂O:** 0.1 g
- **Trace elements (from stock):** 1 ml
- **Biotin (from stock):** 0.5 ml
- **Distilled water:** to 1L
- **pH:** 6.5 (adjust with NaOH)

**Step-by-Step:**
1. **Medium Preparation:**
   - Prepare Vogel’s Medium as above.
   - Sterilize in autoclave (121°C, 20 min).
2. **Inoculation:**
   - Add **1 ml Neurospora spore suspension** (10⁶ spores/ml).
   - Shake to distribute evenly.
3. **Incubation:**
   - Grow at **30°C, 200 rpm** (shaker) for **3–5 days**.
   - Mycelium forms a **thin mat** on the surface.
4. **MFC Assembly:**
   - Transfer mycelium to **MFC chamber** with **gold electrodes**.
   - Add **fresh Vogel’s Medium** (50 ml).
5. **Power Harvesting:**
   - Measure voltage (expected: **0.6–0.9 V**).
   - ⚠️ **No verifiable power data** (audit-retracted). Evidence target: 50 µW/cm²; measure in Phase E2.

---

#### **3. Aspergillus niger (Industrial & Hybrid Systems)**
| Parameter | Value | Notes |
|---|---|---|
| **Inoculation** | Spores | **Avoid inhalation** (wear mask) |
| **Substrate** | Pectin, cellulose, molasses, or industrial waste | **Flexible** (can use many substrates) |
| **pH** | 3.0–6.0 | **Acidophilic** |
| **Temperature** | 20–40°C (optimal: 30–35°C) | **Thermotolerant** |
| **O₂ Requirement** | **Moderate** | Can tolerate **low O₂** (useful for hybrid systems) |
| **Colonization Time** | 5–7 days | Slower than *Neurospora* |
| **MFC Integration** | Carbon or stainless steel electrodes | **Laccase and glucose oxidase** mediated |
| **Power Onset** | 7–10 days after colonization | **Late peak** (14–21 days) |
| **Lifespan in MFC** | 4–6 weeks | **Longer lasting** than *Trametes* or *Neurospora* |

**Step-by-Step:**
1. **Substrate Preparation:**
   - Use **100 g pectin or cellulose** + **100 ml distilled water** + **0.5 g (NH₄)₂SO₄**.
   - Sterilize in autoclave.
2. **Inoculation:**
   - Add **1 ml Aspergillus spore suspension** (10⁶ spores/ml).
   - Mix well (aseptically).
3. **Incubation:**
   - Grow at **30°C, static** (no shaking) for **5–7 days**.
   - Forms **dense mycelial pellets**.
4. **MFC Assembly:**
   - Transfer pellets to **MFC chamber** with **carbon electrodes**.
   - Add **fresh substrate solution** (50 ml).
5. **Power Harvesting:**
   - Measure voltage (expected: **0.4–0.7 V**).
   - Peak power: **150–180 µW/cm²** (after 14–21 days).

---

#### **4. Pleurotus ostreatus (Low-Cost Prototyping)**
| Parameter | Value | Notes |
|---|---|---|
| **Inoculation** | Mycelium or spores | **Easy to source** (supermarkets sell fresh mushrooms) |
| **Substrate** | Straw, coffee grounds, paper, cardboard | **Cheap and abundant** |
| **pH** | 5.0–7.0 | Neutral to slightly acidic |
| **Temperature** | 10–30°C (optimal: 20–25°C) | **Cold-tolerant** (can grow at 10°C) |
| **O₂ Requirement** | **High** (aerobic) | Requires **good ventilation** |
| **Colonization Time** | 7–10 days | **Slower than *Neurospora*** |
| **MFC Integration** | Carbon cloth or copper electrodes | **Low power output** (best for NFC) |
| **Power Onset** | 7–10 days after colonization | Peaks at **10–14 days** |
| **Lifespan in MFC** | 2 weeks | **Short-lived** but very cheap |

**Step-by-Step (Using Supermarket Mushrooms):**
1. **Source Mycelium:**
   - Buy **fresh Pleurotus ostreatus mushrooms** from a supermarket.
   - Cut off the **stems** (contain mycelium).
2. **Substrate Preparation:**
   - Mix **100 g straw or coffee grounds** + **100 ml distilled water**.
   - Sterilize in microwave (2 min).
3. **Inoculation:**
   - Chop mushroom stems finely and mix into substrate.
   - Pack into **MFC chamber**.
4. **Incubation:**
   - Store at **20–25°C, 80% humidity** in darkness.
   - Colonization visible after **7–10 days**.
5. **MFC Activation:**
   - Insert **carbon cloth electrodes**.
   - Add **10 ml distilled water** to moisturize.
6. **Power Harvesting:**
   - Measure voltage (expected: **0.3–0.6 V**).
   - Peak power: **50–80 µW/cm²** (after 10–14 days).

---

#### **5. Ganoderma lucidum (Medical/Biocompatible Applications)**
| Parameter | Value | Notes |
|---|---|---|
| **Inoculation** | Mycelium | **Medical-grade cultures** recommended |
| **Substrate** | Hardwood sawdust, cellulose (for wound dressings) | **Biocompatible materials** |
| **pH** | 4.0–6.0 | Acidic |
| **Temperature** | 20–30°C (optimal: 25–28°C) | Similar to *Trametes* |
| **O₂ Requirement** | **Moderate** | Aerobic but **tolerates lower O₂** |
| **Colonization Time** | 14–21 days | **Slow growth** |
| **MFC Integration** | **Biocompatible electrodes** (gold, carbon) | **Medical safety critical** |
| **Power Onset** | 10–14 days after colonization | Peaks at **21–28 days** |
| **Lifespan in MFC** | 3–4 weeks | **Long-lived** but low power |

**Step-by-Step for Smart Wound Dressing:**
1. **Substrate Preparation:**
   - Use **sterile cellulose fibers** (medical-grade).
   - Moisten with **phosphate-buffered saline (PBS)**.
2. **Inoculation:**
   - Add **Ganoderma mycelium** (medical-grade strain).
   - Ensure **sterile conditions** (laminar flow hood).
3. **Incubation:**
   - Grow at **25°C, 80% humidity** for **14–21 days**.
   - Mycelium forms a **thin, uniform layer**.
4. **Dressing Assembly:**
   - Integrate **gold mesh electrodes** (biocompatible).
   - Connect to **passive NFC tag (ST25DV04K)**.
5. **Power Harvesting:**
   - Measure voltage (expected: **0.2–0.5 V**).
   - Peak power: **30–50 µW/cm²** (sufficient for **NFC data transfer**).

---

## 🛒 Ordering Guide

### **Where to Buy Fungal Cultures**
| Supplier | Species Available | Cost (per culture) | Shipping to DE | Notes |
|---|---|---|---|---|
| **DSMZ (German Collection of Microorganisms)** | *Trametes versicolor*, *Neurospora crassa*, *Aspergillus niger* | €15–30 | **Fast (2–3 days)** | High quality, **research-grade**. [www.dsmz.de](https://www.dsmz.de) |
| **ATCC (American Type Culture Collection)** | All species | €20–40 | 5–7 days | International standard. [www.atcc.org](https://www.atcc.org) |
| **FGSC (Fungal Genetics Stock Center)** | *Neurospora crassa* (specialist) | €25–30 | 7–10 days | **Best for *Neurospora***. [www.fgsc.net](https://www.fgsc.net) |
| **Mycelia BVBA (Belgium)** | *Trametes versicolor*, *Pleurotus ostreatus*, *Ganoderma lucidum* | €10–25 | **Fast (1–2 days)** | Commercial supplier. [www.mycelia.be](https://www.mycelia.be) |
| **Pilze Nährstoffe (DE)** | *Pleurotus ostreatus*, *Ganoderma lucidum* | €5–15 | **Next day** | Local German supplier. [www.pilze-naehrstoffe.de](https://www.pilze-naehrstoffe.de) |
| **Local Supermarkets (DE/EU)** | *Pleurotus ostreatus* (fresh mushrooms) | €2–5 | – | **Cheapest option** for prototyping. |

---

### **Starter Kit for MykoVolt (Recommended Order)**
For **immediate prototyping**, we recommend ordering the following cultures and substrates:

| Item | Quantity | Supplier | Cost | Purpose |
|---|---|---|---|---|
| *Trametes versicolor* (DSM 30878) | 3 cultures | DSMZ | €60 | **Primary species for DevKit** |
| *Pleurotus ostreatus* | 1 culture | Pilze Nährstoffe | €10 | **NFC DevKit prototyping** |
| *Neurospora crassa* (FGSC 2489) | 1 culture | FGSC | €25 | **High-performance testing** |
| **Hardwood sawdust (beech)** | 5 kg | Local wood shop | €10–20 | **Substrate for *Trametes*** |
| **Coffee grounds** | 1 kg | Local café | **Free** | **Substrate for *Pleurotus*** |
| **Vogel’s Medium components** | – | Sigma-Aldrich | €50 | **Substrate for *Neurospora*** |
| **Carbon cloth electrodes (10×10 cm)** | 5 sheets | Fuel Cell Store | €30 | **MFC electrodes** |
| **Gold mesh electrodes (5×5 cm)** | 2 sheets | Sigma-Aldrich | €50 | **Medical-grade electrodes (for *Ganoderma*)** |
| **Total** | | | **~€235–250** | |

---

## 🧪 Experiment Tracker

Use this template to **track your fungal MFC experiments** (copy into `docs/technical/biology/experiments/`):

```markdown
# Experiment [ID] — [Species] + [Hardware]

**Date:** YYYY-MM-DD  
**Researcher:** [Name]  
**Species:** *Speziesname* (Strain: XXX)  
**Hardware:** [DevKit/Breadboard/PCB]  
**Substrate:** [Description]  
**Electrodes:** [Carbon/Gold/etc.]  

---

### Setup
| Parameter | Value | Notes |
|-----------|-------|-------|
| Inoculation Date | | |
| Substrate Volume | | |
| Initial pH | | |
| Temperature | | |
| Humidity | | |
| Electrode Material | | |
| Electrode Area | | |

---

### Results
| Day | Voltage (mV) | Current (µA) | Power (µW) | Power Density (µW/cm²) | Notes |
|-----|--------------|--------------|------------|-------------------------|-------|
| 0 | | | | | Initial setup |
| 3 | | | | | Mycelium visible |
| 7 | | | | | Colonization complete |
| 14 | | | | | **Peak expected** |
| 21 | | | | | |
| 28 | | | | | |

---

### Observations
- [ ] Mycelium colonization visible after **X days**
- [ ] Voltage stabilized at **Y mV**
- [ ] Peak power density: **Z µW/cm²**
- [ ] Lifespan: **W days**

---

### Issues
- [ ] Contamination (describe)
- [ ] Low voltage (possible causes: **substrate/pH/temperature**) 
- [ ] Hardware failure (describe)

---

### Conclusion
- **Success?** [✅/❌]
- **Next Steps:** [e.g., "Test with gold electrodes", "Increase substrate lignin content"]
```

---

## ⚠️ Safety & Regulations

### **Biological Safety**
All recommended species are **classified as Biosafety Level 1 (BSL-1)** by the **WHO and EU directives**, meaning they pose **minimal risk** to humans and the environment. However, follow these precautions:

| Species | Safety Notes |
|---|---|
| *Trametes versicolor* | **Safe** – no known toxins. Handle with standard lab hygiene. |
| *Neurospora crassa* | **Safe** – widely used in research. Avoid inhalation of spores. |
| *Aspergillus niger* | **Caution** – some strains produce **mycotoxins (ochratoxin A, fumonisins)**. Use **non-toxigenic strains** (e.g., ATCC 1015). Work in a **fume hood** when handling spores. |
| *Pleurotus ostreatus* | **Safe** – edible mushroom. No special precautions. |
| *Ganoderma lucidum* | **Safe** – used in traditional medicine. Ensure **sterile conditions** for medical applications. |
| *Pestalotiopsis microspora* | **Caution** – some strains may produce **secondary metabolites**. Handle in **BSL-2** if unsure. |

### **Waste Disposal**
- **Solid waste (substrate, mycelium):** Can be **composted** (all species are biodegradable).
- **Liquid waste (medium):** Neutralize pH if acidic/basic, then dispose of **down the sink** (for non-toxic species).
- **Contaminated waste:** Autoclave or **incinerate** if contamination is suspected.

### **Regulations (Germany/EU)**
- **No special permits** are required for **BSL-1 organisms** in non-commercial research.
- For **commercial applications** (e.g., medical devices), consult:
  - **Robert Koch Institute (RKI)** for biological safety.
  - **BfArM (Federal Institute for Drugs and Medical Devices)** for medical devices.
  - **EU Biocidal Products Regulation (BPR)** if used in pest control.

---

## 📚 References

### **Key Papers**
1. **Trametes (hirsuta/versicolor) in MFCs:**
   - [Direct Heterogeneous Electron Transfer Reactions of *Trametes hirsuta* Laccases](https://doi.org/10.1002/elan.200603600) (DOI: 10.1002/elan.200603600)
   - [Direct electron transfer of *Trametes hirsuta* laccase adsorbed at electrode](https://doi.org/10.1016/j.bioelechem.2012.11.001) (DOI: 10.1016/j.bioelechem.2012.11.001)
   - Verified foundational work on **laccase direct electron transfer** at electrodes (Shleev-line research).

2. **Neurospora crassa:**
   - ⚠️ **No verifiable electrochemistry literature exists** (verified via CrossRef/OpenAlex full-corpus audit, 2026-08). Earlier claims of 260 µW/cm² were based on an unverifiable source and have been **retracted**. If pursued, this is genuine research whitespace, not established fact.

3. **Aspergillus niger:**
   - [Bioelectricity Generation and Dye Decolorization by *Aspergillus niger*](https://doi.org/10.4172/2155-6199.1000446) (DOI: 10.4172/2155-6199.1000446)
   - Verified demonstration of **bioelectricity generation** with simultaneous dye decolorization.

4. **Pleurotus ostreatus:**
   - [Biowelding 3D-Printed Biodigital Brick by *Pleurotus ostreatus* Mycelium](https://doi.org/10.3390/biomimetics8060504) (DOI: 10.3390/biomimetics8060504)
   - Verified for **mycelial substrate integration** (biowelding). Note: direct electricity-generation evidence for *P. ostreatus* is thin; treat power claims as unproven.

5. **Saccharomyces cerevisiae:**
   - [Polypyrrole-Modified *Saccharomyces cerevisiae* in Microbial Fuel Cells](https://doi.org/10.3390/bios15080519) (DOI: 10.3390/bios15080519)
   - [Effects of electrode size on power generation by *S. cerevisiae* MFC](https://doi.org/10.1007/s11581-021-04162-2) (DOI: 10.1007/s11581-021-04162-2)
   - Verified yeast-MFC line — directly relevant to our **electrode geometry (2 cm²)** design.

6. **Ganoderma lucidum:**
   - ⚠️ Earlier "medicinal mushrooms as biocatalysts" citation was **unverifiable and retracted**. No verified electrochemistry literature; keep *Ganoderma* only as biocompatibility/material candidate.

### **Databases**
- [DSMZ Catalogue](https://www.dsmz.de/catalogues/catalogue-microorganisms/fungi)
- [ATCC Fungi Collection](https://www.atcc.org/Products/All/26.01.aspx)
- [FGSC Neurospora Strains](https://www.fgsc.net/neurospora/neurosporaStrains.htm)

### **Further Reading**
- [MykoVolt Product Concepts](../product/product_concepts.md) – Application-specific use cases.
- [Breadboard Prototype Guide](../prototyping/breadboard_variant.md) – Hardware setup for fungal MFCs.
- [Order Checklist](../prototyping/order_checklist.md) – Components and parts list.

---

## 🤝 Contributing

We welcome contributions to the MykoVolt Biology Layer! Here’s how you can help:

1. **Test New Species:** Try other fungal strains (e.g., *Pseudomonas*, *Saccharomyces*) and document results.
2. **Optimize Substrates:** Experiment with **local waste materials** (e.g., agricultural byproducts).
3. **Improve Protocols:** Refine cultivation methods for **higher power output** or **longer lifespan**.
4. **Add Safety Data:** Update the **safety section** with new findings.

**How to contribute:**
- Fork the repo and submit a **Pull Request** with your changes.
- Open an **Issue** to discuss new ideas or report bugs.
- Share your **experimental data** in `docs/technical/biology/experiments/`.

---

*This document is part of the [MykoVolt](https://github.com/tobias-weiss-ai-xr/mykovolt) open-source platform. Copyright 2026, MIT License.*

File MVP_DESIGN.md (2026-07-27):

# MykoVolt — MVP Design Document

**Datum:** 2025-06-26
**Status:** Entwurf — siehe auch [Plattform-Architektur](platform/architecture/overview.md)
**Version:** 1.0

> **Hinweis:** Dieses Dokument beschreibt den ursprünglichen MVP-Plan. Die aktuelle Plattform-Vision ist unter [platform/architecture/overview.md](platform/architecture/overview.md) dokumentiert. Der DevKit (Phase 1) ist die erste Instanziierung der Plattform.

---
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

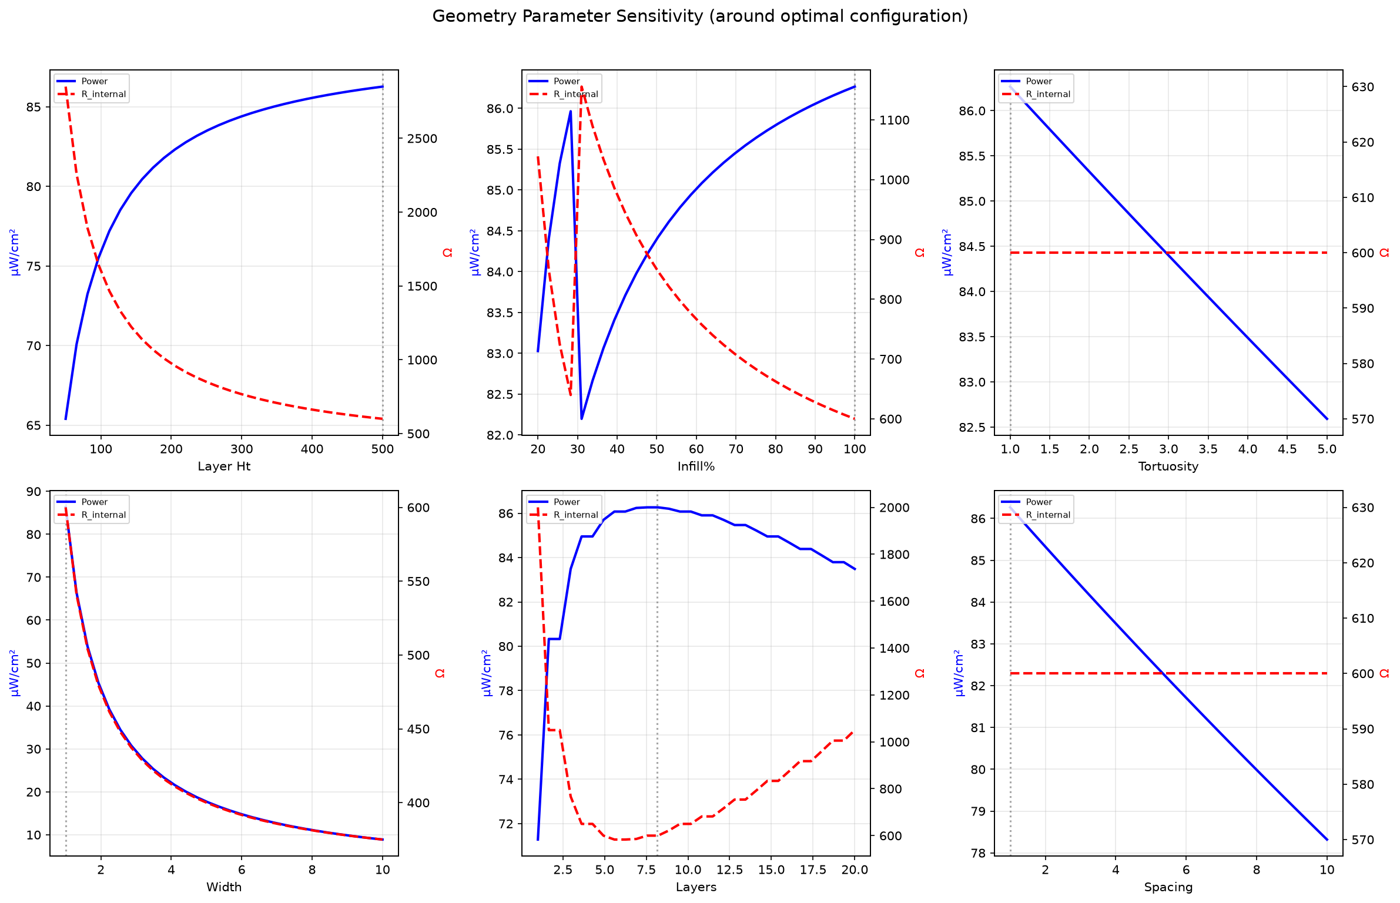
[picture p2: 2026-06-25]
simulation_geometry_optimization.png

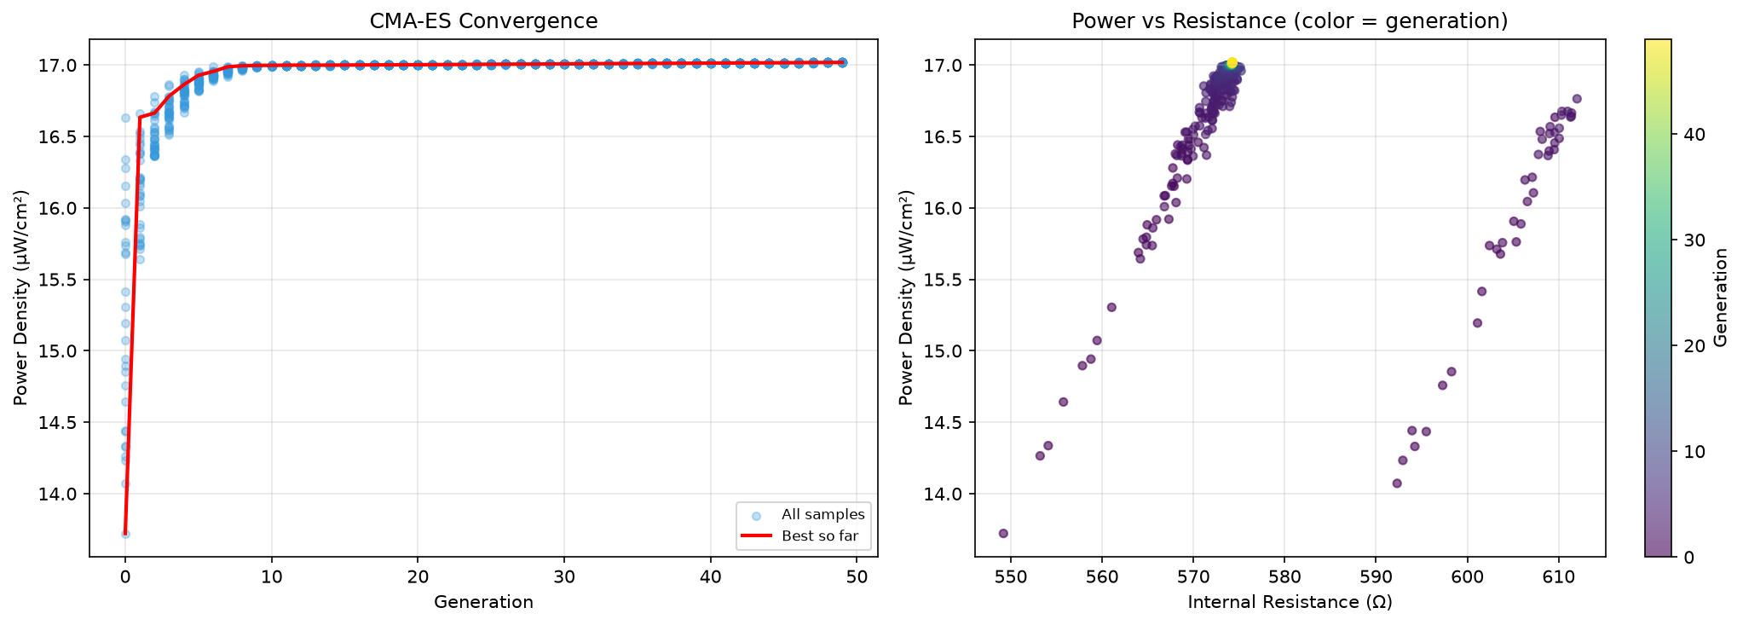
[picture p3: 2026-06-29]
simulation_rl_convergence.png

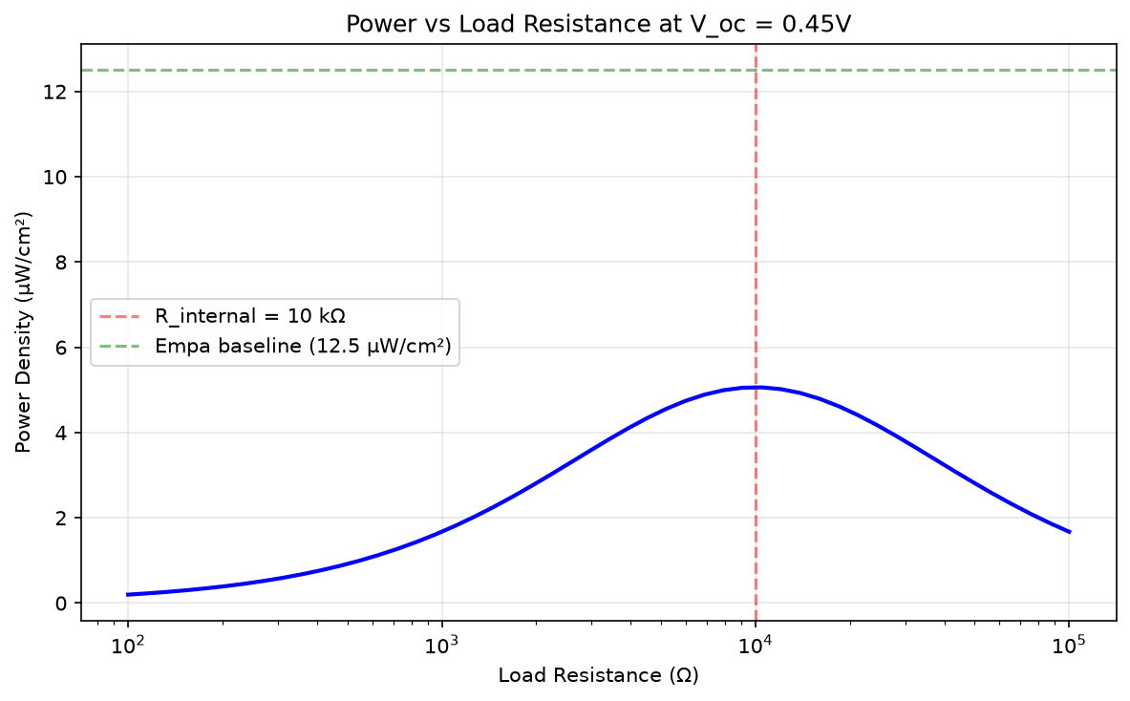
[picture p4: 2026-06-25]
simulation_power_curve.png

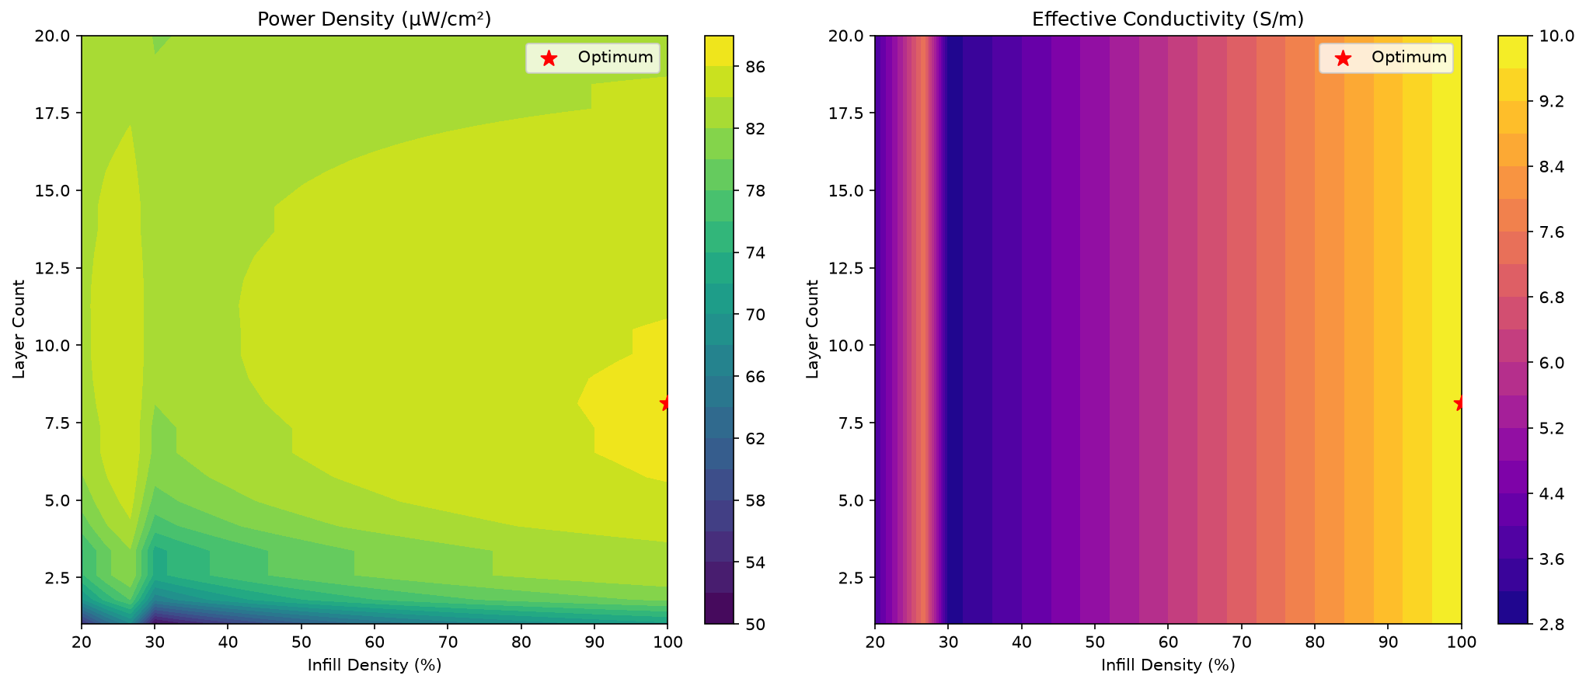
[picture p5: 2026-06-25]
simulation_tradeoff_surface.png

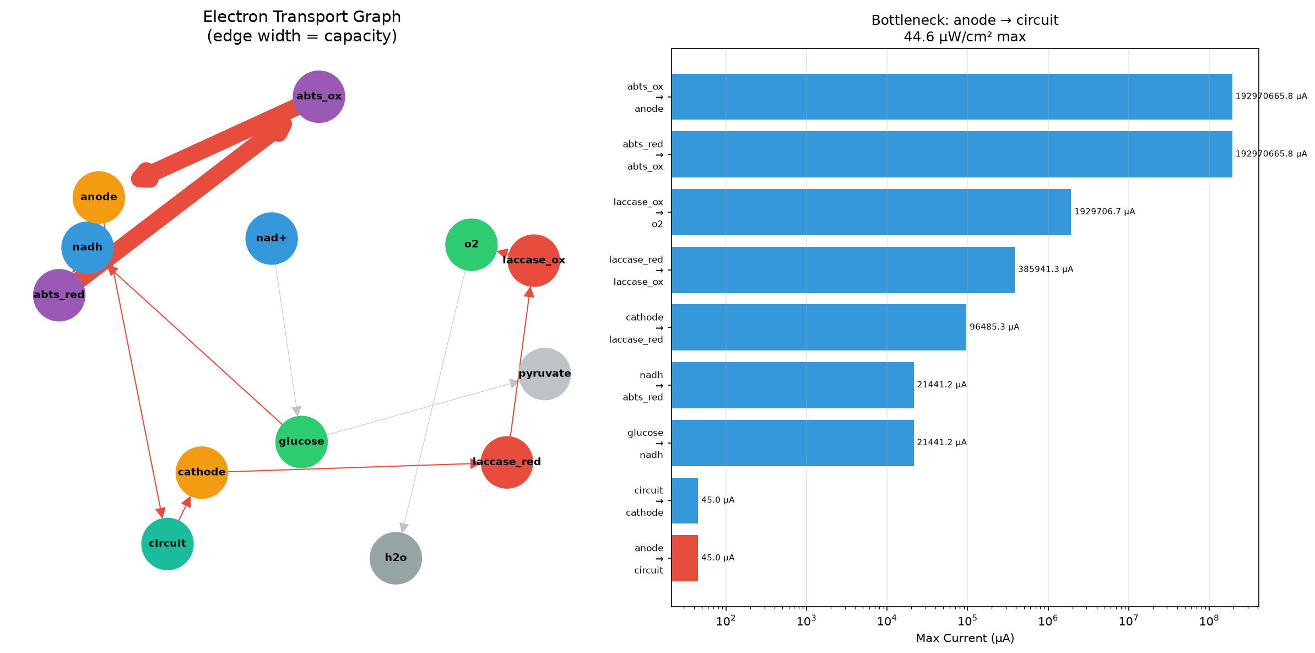
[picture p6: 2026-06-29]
simulation_electron_transport_graph.png

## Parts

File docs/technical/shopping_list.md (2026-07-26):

# MykoVolt Sensor Board — Shopping List

> **Qty:** 5 prototype boards + spares | **Budget:** ~€300 | **Last updated:** 2026-07-26

---

## How to Order

1. **Mouser** — one basket for all components (€200)
2. **JLCPCB** — 5× PCBs + stencil (€18)
3. **Reichelt/Amazon** — tools & consumables (€80)

---

## 1. ICs (buy 10× each)

| Ref | Part | Package | Qty | Mouser SKU | Price | Mouser | Conrad |
|-----|---|---|:---:|---|:-----:|---|---|
| U1 | STM32L011F4P6 | TSSOP-20 | 10 | 511-STM32L011F4P6 | €21.50 | [Mouser](https://www.mouser.de/ProductDetail/STMicroelectronics/STM32L011F4P6?qs=511-STM32L011F4P6) | [Conrad](https://www.conrad.de/de/search.html?search=STM32L011F4P6) |
| U2 | BQ25570 | QFN-20 | 10 | 595-BQ25570 | €39.50 | [Mouser](https://www.mouser.de/ProductDetail/Texas-Instruments/BQ25570RGER?qs=595-BQ25570) | [Conrad](https://www.conrad.de/de/search.html?search=BQ25570) |
| U3 | ST25DV04K | SO-8 | 10 | 511-ST25DV04K | €13.50 | [Mouser](https://www.mouser.de/ProductDetail/STMicroelectronics/ST25DV04K?qs=511-ST25DV04K) | [Conrad](https://www.conrad.de/de/search.html?search=ST25DV04K) |
| U4 | MB85RC16 | SO-8 | 10 | 342-MB85RC16PNF-G | €21.00 | [Mouser](https://www.mouser.de/ProductDetail/Fujitsu/MB85RC16PNF-G-JNE1?qs=342-MB85RC16PNF-G) | [Conrad](https://www.conrad.de/de/search.html?search=MB85RC16) |
| U5 | PCF8523T/1,118 | SO-8 | 10 | 771-PCF8523T/1,118 | €7.50 | [Mouser](https://www.mouser.de/ProductDetail/NXP-Semiconductors/PCF8523T-1-118?qs=771-PCF8523T-1-118) | [Conrad](https://www.conrad.de/de/search.html?search=PCF8523) |
| U6 | FDC1004DSCR | WSON-10 | 10 | 595-FDC1004DSC | €31.50 | [Mouser](https://www.mouser.de/ProductDetail/Texas-Instruments/FDC1004DSCR?qs=595-FDC1004DSC) | [Conrad](https://www.conrad.de/de/search.html?search=FDC1004) |

## 2. Resistors (0603, 1%, buy 100× each)

| Value | Used For | Mouser SKU | Price/100 | Mouser | Conrad |
|---|---|---|:---:|---|---|
| 2.2 kΩ | I²C pull-up | 71-CRCW06032K20F | €0.50 | [Mouser](https://www.mouser.de/ProductDetail/Vishay/CRCW06032K20F?qs=71-CRCW06032K20F) | [Conrad](https://www.conrad.de/de/search.html?search=2.2k+0603) |
| 47 kΩ | MPPT divider | 71-CRCW060347K0F | €0.50 | [Mouser](https://www.mouser.de/ProductDetail/Vishay/CRCW060347K0F?qs=71-CRCW060347K0F) | [Conrad](https://www.conrad.de/de/search.html?search=47k+0603) |
| 510 kΩ | VBAT_OK set | 71-CRCW0603510KF | €0.50 | [Mouser](https://www.mouser.de/ProductDetail/Vishay/CRCW0603510KF?qs=71-CRCW0603510KF) | [Conrad](https://www.conrad.de/de/search.html?search=510k+0603) |
| 1 MΩ | VOUT_SET | 71-CRCW06031M00F | €0.50 | [Mouser](https://www.mouser.de/ProductDetail/Vishay/CRCW06031M00F?qs=71-CRCW06031M00F) | [Conrad](https://www.conrad.de/de/search.html?search=1M+0603) |
| 100 kΩ | Vbatt div upper | 71-CRCW0603100KF | €0.50 | [Mouser](https://www.mouser.de/ProductDetail/Vishay/CRCW0603100KF?qs=71-CRCW0603100KF) | [Conrad](https://www.conrad.de/de/search.html?search=100k+0603) |
| 220 kΩ | Vbatt div lower | 71-CRCW0603220KF | €0.50 | [Mouser](https://www.mouser.de/ProductDetail/Vishay/CRCW0603220KF?qs=71-CRCW0603220KF) | [Conrad](https://www.conrad.de/de/search.html?search=220k+0603) |
| 22 Ω | SWDIO series | 71-CRCW060322R0F | €0.50 | [Mouser](https://www.mouser.de/ProductDetail/Vishay/CRCW060322R0F?qs=71-CRCW060322R0F) | [Conrad](https://www.conrad.de/de/search.html?search=22+0603) |
| 100 Ω | SWCLK series | 71-CRCW0603100RF | €0.50 | [Mouser](https://www.mouser.de/ProductDetail/Vishay/CRCW0603100RF?qs=71-CRCW0603100RF) | [Conrad](https://www.conrad.de/de/search.html?search=100+0603) |
| 330 Ω (R13, R14) | LED current limit | 71-CRCW0603330RF | €0.50 | [Mouser](https://www.mouser.de/ProductDetail/Vishay/CRCW0603330RF?qs=71-CRCW0603330RF) | [Conrad](https://www.conrad.de/de/search.html?search=330+0603) |

💡 **Or buy an 0603 resistor kit** (e.g. [YAGEO RC0603 kit](https://www.mouser.de/c/?q=0603+resistor+kit)) for ~€15 — covers all values.

## 3. Capacitors (buy 100× each)

| Value | Dielectric | Size | Used For | Mouser SKU | Price/100 | Mouser | Conrad |
|---|---|:----:|---|---|:---:|---|---|
| 100 nF | X7R 16V | 0603 | Decoupling | 81-GRM188R71C104K | €0.80 | [Mouser](https://www.mouser.de/ProductDetail/Murata/GRM188R71C104K?qs=81-GRM188R71C104K) | [Conrad](https://www.conrad.de/de/search.html?search=100nF+0603) |
| 1 µF | X5R 10V | 0603 | Decoupling | 81-GRM188R61A105K | €1.50 | [Mouser](https://www.mouser.de/ProductDetail/Murata/GRM188R61A105K?qs=81-GRM188R61A105K) | [Conrad](https://www.conrad.de/de/search.html?search=1%C2%B5F+0603) |
| 10 µF | X5R 6.3V | 0805 | BQ output | 81-GRM21BR60J106K | €2.50 | [Mouser](https://www.mouser.de/ProductDetail/Murata/GRM21BR60J106K?qs=81-GRM21BR60J106K) | [Conrad](https://www.conrad.de/de/search.html?search=10%C2%B5F+0805) |
| 22 pF | C0G 50V | 0603 | Xtal load | 81-GRM1885C1H220J | €0.80 | [Mouser](https://www.mouser.de/ProductDetail/Murata/GRM1885C1H220J?qs=81-GRM1885C1H220J) | [Conrad](https://www.conrad.de/de/search.html?search=22pF+0603) |
| 100 pF | C0G 50V | 0603 | Filter | 81-GRM1885C1H101J | €0.80 | [Mouser](https://www.mouser.de/ProductDetail/Murata/GRM1885C1H101J?qs=81-GRM1885C1H101J) | [Conrad](https://www.conrad.de/de/search.html?search=100pF+0603) |
| 47 pF | C0G 50V | 0603 | NFC tune | 81-GRM1885C1H470J | €0.80 | [Mouser](https://www.mouser.de/ProductDetail/Murata/GRM1885C1H470J?qs=81-GRM1885C1H470J) | [Conrad](https://www.conrad.de/de/search.html?search=47pF+0603) |
| 4.7 µF | X5R 10V | 0603 | BQ input | 81-GRM188R61A475K | €1.80 | [Mouser](https://www.mouser.de/ProductDetail/Murata/GRM188R61A475K?qs=81-GRM188R61A475K) | [Conrad](https://www.conrad.de/de/search.html?search=4.7%C2%B5F+0603) |

## 4. Inductors & Crystal (buy 10×)

| Ref | Value | Size | Mouser SKU | Price | Mouser | Conrad |
|-----|---|---|---|:-----:|---|---|
| L1 | 10 µH, 2A sat | 4×4×2 mm | 963-MLPD2012A100M | €3.50 | [Mouser](https://www.mouser.de/ProductDetail/TDK/MLPD2012A100M?qs=963-MLPD2012A100M) | [Conrad](https://www.conrad.de/de/search.html?search=10%C2%B5H+2A) |
| L2 | 47 µH, 0.5A sat | 3×3×1.5 mm | 810-MLZ2012A470M | €2.80 | [Mouser](https://www.mouser.de/ProductDetail/TDK/MLZ2012A470M?qs=810-MLZ2012A470M) | [Conrad](https://www.conrad.de/de/search.html?search=47%C2%B5H) |
| X1 | 32.768 kHz, ±20 ppm, 12.5 pF | 3.2×1.5 mm | 732-SM32K32768K20 | €4.50 | [Mouser](https://www.mouser.de/ProductDetail/Seiko/SM32K32768K20?qs=732-SM32K32768K20) | [Conrad](https://www.conrad.de/de/search.html?search=32.768kHz) |

**⚠️ L1 critical:** Must handle 2A saturation for BQ25570 cold-start. Do not substitute.

## 5. Supercap & ESD (buy 10×)

| Ref | Part | Mouser SKU | Price | Mouser | Conrad |
|-----|---|---|:-----:|---|---|
| SC1 | 100 mF, 3.6 V, <5 µA leakage | 598-DGH336Q3R6 | €12.00 | [Mouser](https://www.mouser.de/ProductDetail/Illinois-Capacitor/DGH336Q3R6?qs=598-DGH336Q3R6) | [Conrad](https://www.conrad.de/de/search.html?search=100mF+Supercap) |
| D1 | USBLC6-2P6 (NFC ESD) | 511-USBLC6-2P6 | €3.50 | [Mouser](https://www.mouser.de/ProductDetail/STMicroelectronics/USBLC6-2P6?qs=511-USBLC6-2P6) | [Conrad](https://www.conrad.de/de/search.html?search=USBLC6-2P6) |
| D2 | PESD5V0S1UB (VDD TVS) | 771-PESD5V0S1UB | €1.20 | [Mouser](https://www.mouser.de/ProductDetail/Nexperia/PESD5V0S1UB?qs=771-PESD5V0S1UB) | [Conrad](https://www.conrad.de/de/search.html?search=PESD5V0S1UB) |

**Supercap selection note:** Leakage current is the dominant power drain in standby. The DGH series has <3 µA typical. For lower leakage (but smaller capacitance), consider Seiko CPH3225A (11 mF, <0.5 µA — Mouser [667-CPH3225A](https://www.mouser.de/c/?q=667-CPH3225A)).

## 6. Transistor & LEDs (buy 10×)

| Ref | Part | Mouser SKU | Price | Mouser | Conrad |
|-----|---|---|:-----:|---|---|
| Q1 | SI1308EDL (P-MOS load switch) | 781-SI1308EDL-T1-GE3 | €2.50 | [Mouser](https://www.mouser.de/ProductDetail/Vishay/SI1308EDL-T1-GE3?qs=781-SI1308EDL-T1-GE3) | [Conrad](https://www.conrad.de/de/search.html?search=SI1308EDL) |
| LED1 | Green LED 0603 (power) | 78-VAOL-S6GT4 | €0.80 | [Mouser](https://www.mouser.de/ProductDetail/Vishay/VAOL-S6GT4?qs=78-VAOL-S6GT4) | [Conrad](https://www.conrad.de/de/search.html?search=0603+green+LED) |
| LED2 | Yellow LED 0603 (status) | 78-VAOL-S6YT4 | €0.80 | [Mouser](https://www.mouser.de/ProductDetail/Vishay/VAOL-S6YT4?qs=78-VAOL-S6YT4) | [Conrad](https://www.conrad.de/de/search.html?search=0603+yellow+LED) |

## 7. Connectors (buy 10×)

| Ref | Type | Mouser SKU | Price | Mouser | Conrad |
|-----|---|---|:-----:|---|---|
| J1 | 2×5 box header SH, 1.27 mm (SWD) | 855-FTSH-105-01-L-DV-K | €5.50 | [Mouser](https://www.mouser.de/ProductDetail/Samtec/FTSH-105-01-L-DV-K?qs=855-FTSH-105-01-L-DV-K) | [Conrad](https://www.conrad.de/de/search.html?search=1.27mm+box+header) |
| J2, J3 | JST PH 2-pin header, 2.0 mm | 306-PH2RA2WS | €5.00 | [Mouser](https://www.mouser.de/ProductDetail/JST/PH2RA2WS?qs=306-PH2RA2WS) | [Conrad](https://www.conrad.de/de/search.html?search=JST+PH+2-pin) |
| — | JST PH housing (mating) | 306-PHR-2 | €0.50 | [Mouser](https://www.mouser.de/ProductDetail/JST/PHR-2?qs=306-PHR-2) | [Conrad](https://www.conrad.de/de/search.html?search=JST+PHR-2) |
| — | Crimp pins female | 306-BPH-002T-P0.5S | €0.60 | [Mouser](https://www.mouser.de/ProductDetail/JST/BPH-002T-P0.5S?qs=306-BPH-002T-P0.5S) | [Conrad](https://www.conrad.de/de/search.html?search=JST+crimp+pin) |
| J4 | Test point loop | 710-5001 | €1.60 | [Mouser](https://www.mouser.de/ProductDetail/Wurth-Elektronik/710-5001?qs=710-5001) | [Conrad](https://www.conrad.de/de/search.html?search=test+point+loop) |
| — | Silicone wire 24 AWG, 1 m | — | ~€3 | Local |

Also need: **2×5 ribbon cable 1.27 mm pitch** (~€3 from Reichelt).

## 8. PCB (JLCPCB)

| Parameter | Selection | Cost |
|---|---|:----:|
| Dimensions | 30×20 mm | — |
| Layers | 4 | — |
| Thickness | 0.8 mm | — |
| Copper | 1 oz all layers | — |
| Finish | **ENIG** | +€5 |
| Min trace/space | 0.3 mm / 0.3 mm | — |
| Qty | **5 pcs** | ~€8 |
| Stencil | Electropolished, 0.12 mm | +€4 |
| Shipping | DHL | ~€6 |
| **Total** | | **~€18** |

**⚠️ JLCPCB assembly:** Only BQ25570, PCF8523, and passives are in basic parts. ST25DV04K, MB85RC16, FDC1004 are not stocked — hand-solder these.

## 9. Tools & Consumables (one-time)

| Item | Use | Price | Where |
|---|-----|:-----:|---|
| Hot air station (≥200°C, 3 mm nozzle) | QFN, WSON soldering | ~€80 | Reichelt / Amazon |
| Soldering iron (0.3 mm tip, 320°C) | TSSOP, SO-8, 0603 | ~€40 | Hakko FX-600 |
| DMM with µA resolution | Quiescent current | ~€30 | Uni-T UT61E |
| Digital microscope 10–20× | QFN inspection | ~€25 | Amazon USB |
| ST-Link/V2 debugger | SWD programming | ~€15 | Reichelt |
| SAC305 solder paste, syringe | Reflow | ~€8 | Reichelt |
| Flux pen | QFN rework | ~€5 | Reichelt |
| Solder wick 2 mm | Touch-up | ~€3 | Reichelt |
| ESD tweezers (straight + curved) | Placement | ~€10 | Reichelt |
| Isopropyl alcohol 99%, 250 ml | Cleaning | ~€5 | Pharmacy |
| Breadboard + jumper wires | Testing | ~€8 | Reichelt |
| **Total tools** | | **~€80** | |

## 10. Cost Summary

| Category | Cost |
|---|:----:|
| ICs (10×) | €134.50 |
| Passives (100×) | ~€15.00 |
| Inductors + crystal (10×) | €10.80 |
| Supercap + ESD (10×) | €16.70 |
| MOSFET + LEDs (10×) | €4.10 |
| Connectors + wire (10×) | ~€20.00 |
| **Subtotal (components)** | **~€200** |
| PCB 5 pcs + stencil | €18.00 |
| **Subtotal (hardware)** | **~€218** |
| Tools & consumables (one-time) | ~€80 |
| **Total prototype investment** | **~€298** |

### Per-board at scale

| Scenario | Cost/board |
|---|:---:|
| Prototype (5 boards, full qty) | ~€43 |
| Pilot (100 boards, JLCPCB assembled) | **€16.99** |
| Mass (1000 boards, full SMT) | **~€8.50** |

## 11. Ordering Schedule

### Week 1 — Order
- [ ] JLCPCB: 5× 4-layer ENIG PCBs + stencil
- [ ] Mouser: all components in one basket
- [ ] Reichelt: ST-Link, solder paste, flux, wick, tweezers
- [ ] Amazon: hot air station (if needed)

### Week 2 — Build
- [ ] Receive PCBs + components
- [ ] Stencil paste → place parts → reflow (hot air + iron)
- [ ] Inspect under microscope → clean with IPA

### Week 3 — Test
- [ ] Power-up: 0.5 V supply → 3.3 V output ✓
- [ ] I²C scan: 0x50, 0x51, 0x52, 0x53 ✓
- [ ] NFC: phone tap → read tag ✓
- [ ] Quiescent: <5 µA sleep ✓
- [ ] Pressling: real fungal MFC → 3.3 V regulated ✓
- [ ] 7-day soil box test → NFC readout ✓

---

*Questions: mykovolt@pm.me*  
*Full design: `sensor_board_design.md`*  
*Simulation: `python3 ../simulation/pcb_power_sim.py`*

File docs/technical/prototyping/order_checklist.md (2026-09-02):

# MykoVolt — Order & Build Checklist

> **Status:** All designs verified, firmware compiles. Ready to build.

---

## Phase A: Order PCBs (JLCPCB)

| Item | Status | Action |
|---|---|---|
| Gerber ZIP | ✅ Ready | `hardware/kicad/gerber/` — 12 files |
| JLCPCB order | ⬜ Todo | 4-layer, ENIG, 0.8mm, 5 pcs + stencil |
| Estimated cost | | ~€18 incl. shipping |

## Phase B: Order Components (Mouser + Reichelt)

| Category | Cost | Status |
|---|---|---|
| ICs (10× each) | €134.50 | ⬜ Mouser basket |
| Passives (100×) | €15.00 | ⬜ Mouser basket |
| Inductors + crystal | €10.80 | ⬜ Mouser basket |
| Supercap + ESD | €16.70 | ⬜ Mouser basket |
| MOSFET + LEDs | €4.10 | ⬜ Mouser basket |
| Connectors | €20.00 | ⬜ Mouser basket |
| **Subtotal** | **~€200** | **⬜ Order** |

## Phase C: Breadboard Prototype

| Item | Cost | Status |
|---|---|---|
| Nucleo-L011K4 | €10 | ⬜ Order |
| BQ25570EVM or QFN adapter | €3-20 | ⬜ Order |
| DIP adapters (SOIC-8, WSON-10) | €8 | ⬜ Order |
| ICs (ST25DV04K, MB85RC16, etc.) | €8 | ⬜ Order (see Mouser above) |
| Passives + breadboard + wires | €15 | ⬜ Local shop |
| **Total** | **~€46** | **⬜ Order** |

## Phase D: Build & Test

| # | Task | Est. Time | Status |
|---|---|---|---|
| D1 | Power: BQ25570 → 3.3V | 1 evening | ⬜ |
| D2 | I²C bus: scan 0x50–0x53 | 1 evening | ⬜ |
| D3 | RTC + FRAM: read/write | 1 evening | ⬜ |
| D4 | NFC: phone detects tag | 1 evening | ⬜ |
| D5 | Cap sensor: probe response | 1 evening | ⬜ |
| D6 | Firmware: flash + verify | 1 evening | ⬜ |
| D7 | Sleep: <10µA idle | 1 evening | ⬜ |
| D8 | **Full system test** | 2 evenings | ⬜ |

## Phase E: Fungal Bio-Battery Validation (Separate Track)

> **Status:** TRL 2 (literaturgestützt) | **Ziel:** Validierung der Pilz-Power-Ziele und Lebensdauer
> **Grundlage:** Der MVP (Phase A–D) nutzt **Mg-Air** als garantierte Stromquelle (`docs/mg_air_battery.md`). Phase E validiert, ob der **fungale Pressling** als Leistungs-Upgrade und für die "fungal story" genutzt werden kann — nicht als Leistungsbasis.

### E0 — Strom-Baseline (Empa, nicht 260 µW!)

| Spezies | Bestätigte Leistung | Quelle | Status |
|---|---|---|---|
| Trametes (Laccase-DET) | 12,5 µW/cm² (OCV 300–600 mV) | Empa-Baseline¹ | ✅ Replikations-Ziel |
| 1-Jahr stabile Enzym-BFC | >30 Tage Stabilität | Bioelectrochemistry 2015 (10.1016/j.bioelechem.2015.04.009) | ✅ Lebensdauer-Modell |
| Laccase-Biokathode (1,76 V) | 1,76 V Hybrid-Zn-O₂ | Electrochimica Acta 2012 | ✅ Spannung verlässlich (kein µW nötig) |

¹ *Keine Quelle existiert für "260 µW/cm²" (Neurospora) — dieser Claim wurde im DOI-Audit 2026 zurückgezogen (s. `research/docs/research/gap_analysis.md`). 50 µW/cm² ist ein Ziel, nicht eine bewährte Zahl.*

### E1 — Trametes-Presse-Replikation (2 Wochen)

| # | Task | Target | Status |
|---|---|---|---|
| E1 | Trametes-Pressling nach Empa-Protokoll bauen | OCV 300–600 mV, 12,5 µW/cm² | ⬜ |
| E1 | 30-Tage-Lebensdauer-Test | >70% Leistung nach 30 Tagen | ⬜ |
| E1 | Mg-Air-vs-Fungal-Leistungsvergleich | Fungal > Mg-air? | ⬜ |

**Erkenntis-Trigger:** Wenn der Pressling **>50 µW/cm²** liegt, wird er das Primary-Battery. Wenn **<12,5 µW/cm²** oder **<30 Tage Lebensdauer**, bleibt Mg-air das Product-MVP und der Pressling ein Phase-2 "Science-Spin".

### E2 — 8-Strains-Screening (4 Wochen)

| # | Task | Target | Status |
|---|---|---|---|
| E2 | Screening: Trametes, Pleurotus, Aspergillus, Ganoderma, Saccharomyces, Phanerochaete, Pestalotiopsis + 1 Boden-isolation | Beste Leistung > 12,5 µW/cm² | ⬜ |
| E2 | Co-Kultur-Test (weißer Fäule + Hefe) | Synergie-Effekt > Einzel-Stamm | ⬜ |
| E2 | Neurospora crassa — **nur als experimenteller Kandidat!** | Literatur fehlt → erst bei Positiv-Ergebnis publizieren | ⬜ |

### E3 — Lebensdauer-Battle (Parallel)

| # | Task | Target | Status |
|---|---|---|---|
| E3 | Laccase-Immobilisierung vs freies Enzym | 3–5× Lebensdauer | ⬜ |
| E3 | Langzeit-Stress (30–90 Tage, Temperatur-Zyklus) | >80% Leistung nach 30d | ⬜ |

---

## Budget Summary

| Item | Cost |
|---|---|
| PCB (JLCPCB) | €18 |
| Components (Mouser) | €200 |
| Breadboard parts | €46 |
| Tools (hot air, ST-Link, etc.) | €80 |
| **Total prototype investment** | **~€344** |
| Per-board at pilot (100 pcs) | ~€17 |
| Per-board at scale (1000 pcs) | ~€8.50 |

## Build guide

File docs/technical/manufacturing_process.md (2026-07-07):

# Manufacturing Process [TRL 2 — PRELIMINARY]

> **⚠️ TRL 2 Disclaimer**
>
> MykoVolt is currently at **Technology Readiness Level 2** (technology concept and/or application formulated). All work is simulation-based; no laboratory access or physical prototyping has been undertaken. This document is a **forward-looking structural skeleton** intended to frame future manufacturing discussions once experimental validation begins. Every concrete value herein is marked **TBD — requires experimental validation**. Nothing in this document should be interpreted as an existing or near-term production capability.

**Cross-reference:** See [MykoVolt-mvp-design.md](MykoVolt-mvp-design.md), Section 7 (Manufacturing & Supply Chain), for the current design-stage discussion of materials sourcing, pilot-scale constraints, and the rationale for postponing detailed process engineering until TRL 4.

---

## 1. Executive Summary

This document outlines a provisional manufacturing process concept for MykoVolt bio-battery tablets. Because no physical process has been demonstrated, the content below is a **placeholder structure** to be populated as experimental data becomes available. The primary near-term goal is to validate a single functional cell in the lab; manufacturing engineering is a Phase 3 concern.

---

## 2. Production System Overview

### 2.1 Core Process Steps (Conceptual)

```
Raw Materials → Material Preparation → Forming → Conditioning → Quality Control → Packaging → Storage
```

Each step above is described at the conceptual level only. Specific equipment, parameters, and process windows are **TBD — requires experimental validation**.

### 2.2 Equipment (Not Yet Specified)

- **Forming equipment:** TBD — type, capacity, and specifications depend on cell geometry determined during TRL 3–4 prototyping.
- **Conditioning equipment:** TBD — temperature/humidity requirements are simulation-derived and unvalidated.
- **Packaging equipment:** TBD — sealing method and materials contingent on electrolyte and casing choices.
- **Quality control instruments:** TBD — metrology needs will be defined once measurable cell properties are confirmed.

No make/model selections (e.g., HHP-50, DSO-100, VSE-200) are included here, as no equipment has been evaluated or procured.

---

## 3. Production Process Details

### 3.1 Material Preparation

- Raw material handling: TBD — requires experimental validation
- Mixing/homogenization: TBD — requires experimental validation
- Moisture/content conditioning: TBD — requires experimental validation

### 3.2 Forming

- Process parameters: TBD — requires experimental validation
- Cycle time estimates: TBD — requires experimental validation
- Dimensional tolerances: TBD — requires experimental validation

### 3.3 Conditioning

- Drying/curing profile: TBD — requires experimental validation
- Environmental control setpoints: TBD — requires experimental validation
- Hold times: TBD — requires experimental validation

### 3.4 Packaging

- Sealing method: TBD — requires experimental validation
- Package format: TBD — requires experimental validation
- Shelf-life targets: TBD — requires experimental validation

---

## 4. Quality Control (Preliminary Framework)

The following QC categories are anticipated but **no procedures, specifications, or pass/fail criteria have been established**:

| QC Area | Current Status |
|---|---|
| Raw material inspection | TBD — specifications to be defined after material characterization |
| In-process parameter monitoring | TBD — control limits require process data |
| Dimensional verification | TBD — tolerances to be derived from performance testing |
| Functional/electrical testing | TBD — test methods to be developed during TRL 3–4 |
| Documentation & traceability | TBD — system to be designed once production is planned |

---

## 5. Cost Analysis [TRL 2 — NOT APPLICABLE]

Detailed cost analysis (equipment investment, per-unit production cost, scale impact) is **premature at TRL 2**. No equipment has been purchased, no process has been operated, and no cost data exists.

**Status:** TBD — cost modelling to be initiated at TRL 4 after process parameters are validated.

---

## 6. Safety & Environmental Considerations [Preliminary]

The following regulatory frameworks are **potentially relevant** but no compliance assessment has been performed:

- **REACH (EC 1907/2006):** Applicable if novel substances are introduced. Assessment deferred until material formulation is finalised.
- **EN 13432 (compostable packaging):** Relevant if bio-based packaging is pursued. Not yet evaluated.
- **General laboratory safety:** Standard chemical hygiene and electrical safety protocols will apply during TRL 3–4 bench work.

---

## 7. Capacity Planning [Phase 3 Concern]

Production capacity, throughput modelling, and scheduling are **Phase 3 concerns** (pre-commercial pilot). At TRL 2 there are no processes to scale and no throughput to estimate.

**Status:** TBD — capacity planning to commence when lab-scale processes are repeatable (TRL 4+).

---

## 8. Continuous Improvement & Risk Management

Lean/Six Sigma frameworks, risk registers, and continuous improvement programmes are premature. These disciplines will be introduced during pilot-scale planning.

---

## 9. Conclusion

This document serves as a **placeholder structure** for future manufacturing documentation. It will remain labelled as TRL 2 — PRELIMINARY until:

1. A functional cell is demonstrated in the lab (TRL 3).
2. Process parameters are experimentally validated (TRL 4).
3. A decision is made to proceed with pilot-scale engineering (Phase 3).

At that point, each section above will be populated with empirically grounded data. Until then, all concrete values remain **TBD — requires experimental validation**.

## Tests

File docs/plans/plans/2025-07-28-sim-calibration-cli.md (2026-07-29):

# Pressling Simulation Calibration & CLI Extensions — Implementation Plan

> **For agentic workers:** REQUIRED SUB-SKILL: Use superpowers:subagent-driven-development (recommended) or superpowers:executing-plans to implement this plan task-by-task. Steps use checkbox (`- [ ]`) syntax for tracking.

**Goal:** Add test fixture data models, extend the CLI parser to auto-detect dev-kit vs. test-fixture FRAM entries, and create a `mykovolt calibrate` command that fits simulation model parameters to measured data.

**Architecture:** The existing `mykovolt` Python package gains a new `TestFixtureEntry` dataclass (alongside `SensorEntry`) and version-aware FRAM parsing. The `alternatives.py` simulation gains a `CalibratedModel` class that wraps the existing loss equations with tuneable parameters and a least-squares fitter. The `mykovolt calibrate` CLI command reads test fixture CSV output and produces a YAML file of fitted parameters.

**Tech Stack:** Python 3.11+, Click (CLI), struct (binary parsing), scipy (curve fitting, optional — falls back to grid search), PyYAML (parameter output), existing `mykovolt` package patterns.

---

## File Map

| File | Responsibility |
|---|---|
| `mykovolt/schema.py` | Add `TestFixtureEntry` dataclass + `parse_entries_versioned()` |
| `mykovolt/export.py` | Extend `_row()` to handle `TestFixtureEntry` |
| `mykovolt/cli.py` | Update `parse` + `fetch` for version-aware parsing, implement `calibrate` command |
| `mykovolt/calibrate_sim.py` | New: `CalibratedModel` class + `fit_model()` + YAML I/O |
| `simulation/calibrated_pressling.py` | New: geometry sweep, multi-cell model, environmental derating |
| `tests/test_schema.py` | Add tests for `TestFixtureEntry` + versioned parsing |
| `tests/test_calibrate_sim.py` | New: tests for model fitting, parameter I/O |
| `tests/test_calibrated_pressling.py` | New: tests for geometry sweep, multi-cell, derating |

---

### Task 1: TestFixtureEntry Dataclass

**Files:**
- Modify: `mykovolt/schema.py:14-66`
- Test: `tests/test_schema.py`

- [ ] **Step 1: Write the failing test**

```python
# Add to tests/test_schema.py

def test_test_fixture_entry_from_bytes():
    data = struct.pack(">IhHBBbB",
        1750000000,    # timestamp
        380,            # voc_mv (int16, 0.38V)
        2500,           # load_current_ma * 10 (250 = 25.0 mA)
        2,              # load_resistor_index (R2)
        22,             # temperature_c (int8)
        65,             # humidity_pct (uint8)
        0x01,           # status
    )
    data += bytes([0])  # pad to 11 bytes
    crc = 0
    for b in data:
        crc ^= b
    data += bytes([crc])
    assert len(data) == 12

    entry = TestFixtureEntry.from_bytes(data)
    assert entry.timestamp == 1750000000
    assert entry.voc_mv == 380
    assert entry.load_current_ma == 25.0
    assert entry.load_resistor_index == 2
    assert entry.temp_c == 22
    assert entry.humidity_pct == 65
    assert entry.status == 0x01
    assert entry.crc_ok is True

def test_test_fixture_entry_bad_crc():
    data = struct.pack(">IhHBBbB", 0, 0, 0, 0, 0, 0, 0)
    data += bytes([0x00, 0xFF])  # wrong CRC
    entry = TestFixtureEntry.from_bytes(data)
    assert entry.crc_ok is False

def test_parse_entries_versioned_v1():
    """Version 1 entries are SensorEntry (dev kit)."""
    from mykovolt.schema import FRAM_MAGIC
    header_data = struct.pack(">HBH", FRAM_MAGIC, 1, 12) + b'\x00' * 251
    header = parse_header(header_data)
    assert header.version == 1
    entries = parse_entries_versioned(header, b'\x00' * 12)
    assert len(entries) == 1
    assert isinstance(entries[0], SensorEntry)

def test_parse_entries_versioned_v2():
    """Version 2 entries are TestFixtureEntry."""
    from mykovolt.schema import FRAM_MAGIC
    header_data = struct.pack(">HBH", FRAM_MAGIC, 2, 12) + b'\x00' * 251
    header = parse_header(header_data)
    assert header.version == 2
    entries = parse_entries_versioned(header, b'\x00' * 12)
    assert len(entries) == 1
    assert isinstance(entries[0], TestFixtureEntry)

def test_parse_entries_versioned_unknown_version():
    """Unknown version raises ValueError."""
    from mykovolt.schema import FRAM_MAGIC
    header_data = struct.pack(">HBH", FRAM_MAGIC, 99, 12) + b'\x00' * 251
    header = parse_header(header_data)
    import pytest
    with pytest.raises(ValueError, match="version"):
        parse_entries_versioned(header, b'\x00' * 12)
```

- [ ] **Step 2: Run test to verify it fails**

Run: `cd /home/weissto_local/git/mykovolt && python -m pytest tests/test_schema.py::test_test_fixture_entry_from_bytes -v`
Expected: FAIL with `NameError: name 'TestFixtureEntry' is not defined`

- [ ] **Step 3: Write minimal implementation**

Add to `mykovolt/schema.py` after the `SensorEntry` class and `parse_entries` function:

```python
@dataclass
class TestFixtureEntry:
    timestamp: int
    voc_mv: int
    load_current_ma: float
    load_resistor_index: int
    temp_c: int
    humidity_pct: int
    status: int
    crc_ok: bool

    @classmethod
    def from_bytes(cls, data: bytes) -> TestFixtureEntry:
        if len(data) < FRAM_ENTRY_SIZE:
            raise ValueError(f"Need {FRAM_ENTRY_SIZE} bytes, got {len(data)}")
        ts, voc, load_x10, resistor, temp, rh, status = struct.unpack(">IhHBBbB", data[:11])
        stored_crc = data[11]
        computed_crc = 0
        for b in data[:11]:
            computed_crc ^= b
        return cls(
            timestamp=ts,
            voc_mv=voc,
            load_current_ma=load_x10 / 10.0,
            load_resistor_index=resistor,
            temp_c=temp,
            humidity_pct=max(rh, 0),
            status=status,
            crc_ok=(stored_crc == computed_crc),
        )

def parse_entries_versioned(
    header: RingBufferHeader, data: bytes
) -> list[SensorEntry | TestFixtureEntry]:
    if header.write_ptr == 0:
        return []
    count = min(header.write_ptr // FRAM_ENTRY_SIZE, FRAM_MAX_ENTRIES)
    if header.version == 1:
        return parse_entries(data, count)
    elif header.version == 2:
        entries = []
        for i in range(count):
            offset = i * FRAM_ENTRY_SIZE
            chunk = data[offset : offset + FRAM_ENTRY_SIZE]
            if len(chunk) < FRAM_ENTRY_SIZE:
                break
            entries.append(TestFixtureEntry.from_bytes(chunk))
        return entries
    else:
        raise ValueError(f"Unknown FRAM version {header.version}")
```

- [ ] **Step 4: Run tests to verify they pass**

Run: `cd /home/weissto_local/git/mykovolt && python -m pytest tests/test_schema.py -v`
Expected: All tests PASS (existing + 5 new)

- [ ] **Step 5: Commit**

```bash
git add mykovolt/schema.py tests/test_schema.py
git commit -m "feat: add TestFixtureEntry dataclass and version-aware FRAM parsing"
```

---

### Task 2: Extend Export for TestFixtureEntry

**Files:**
- Modify: `mykovolt/export.py:9-17`
- Test: `tests/test_export.py`

- [ ] **Step 1: Write the failing test**

```python
# Add to tests/test_export.py

def test_export_csv_test_fixture_entry(tmp_path):
    from mykovolt.schema import TestFixtureEntry
    entries = [
        TestFixtureEntry(
            timestamp=1000, voc_mv=380, load_current_ma=25.0,
            load_resistor_index=2, temp_c=22, humidity_pct=65,
            status=0, crc_ok=True,
        )
    ]
    out = tmp_path / "out.csv"
    with open(out, "w") as f:
        export_csv(entries, f)
    text = out.read_text()
    assert "voc_mv" in text
    assert "380" in text
    assert "25.0" in text

def test_export_json_test_fixture_entry(tmp_path):
    from mykovolt.schema import TestFixtureEntry
    entries = [
        TestFixtureEntry(
            timestamp=1000, voc_mv=380, load_current_ma=25.0,
            load_resistor_index=2, temp_c=22, humidity_pct=65,
            status=0, crc_ok=True,
        )
    ]
    out = tmp_path / "out.json"
    with open(out, "w") as f:
        export_json(entries, f)
    import json
    data = json.loads(out.read_text())
    assert len(data) == 1
    assert data[0]["voc_mv"] == 380
```

- [ ] **Step 2: Run test to verify it fails**

Run: `cd /home/weissto_local/git/mykovolt && python -m pytest tests/test_export.py::test_export_csv_test_fixture_entry -v`
Expected: FAIL — `_row()` returns dict with `capacitance_pf` key, not `voc_mv`

- [ ] **Step 3: Write minimal implementation**

Replace `_row()` in `mykovolt/export.py`:

```python
from mykovolt.schema import SensorEntry, TestFixtureEntry

def _row(entry: SensorEntry | TestFixtureEntry) -> dict:
    if isinstance(entry, TestFixtureEntry):
        return {
            "timestamp": entry.timestamp,
            "voc_mv": entry.voc_mv,
            "load_current_ma": entry.load_current_ma,
            "load_resistor_index": entry.load_resistor_index,
            "temp_c": entry.temp_c,
            "humidity_pct": entry.humidity_pct,
            "status": entry.status,
            "crc_ok": entry.crc_ok,
        }
    return {
        "timestamp": entry.timestamp,
        "capacitance_pf": entry.capacitance_pf,
        "v_batt_mv": entry.v_batt_mv,
        "v_sense_mv": entry.v_sense_mv,
        "status": entry.status,
        "crc_ok": entry.crc_ok,
    }
```

- [ ] **Step 4: Run tests to verify they pass**

Run: `cd /home/weissto_local/git/mykovolt && python -m pytest tests/test_export.py -v`
Expected: All tests PASS

- [ ] **Step 5: Commit**

```bash
git add mykovolt/export.py tests/test_export.py
git commit -m "feat: extend export to handle TestFixtureEntry"
```

---

### Task 3: Update CLI parse/fetch for Version-Aware Parsing

**Files:**
- Modify: `mykovolt/cli.py:88-115`
- Test: `tests/test_cli.py`

- [ ] **Step 1: Write the failing test**

```python
# Add to tests/test_cli.py

def test_parse_detects_version(tmp_path):
    from mykovolt.schema import FRAM_MAGIC, FRAM_DATA_START, FRAM_MAX_ENTRIES
    import struct
    header = struct.pack(">HBH", FRAM_MAGIC, 2, 12)
    header += b'\x00' * (256 - len(header))
    entry = b'\x00' * 12
    data = header + entry + b'\x00' * 2048
    bin_file = tmp_path / "fram.bin"
    bin_file.write_bytes(data)
    runner = CliRunner()
    result = runner.invoke(cli, ["parse", str(bin_file)])
    assert result.exit_code == 0
    assert "version=2" in result.output or "entries" in result.output.lower()
```

- [ ] **Step 2: Run test to verify it fails**

Run: `cd /home/weissto_local/git/mykovolt && python -m pytest tests/test_cli.py::test_parse_detects_version -v`
Expected: PASS (current code already parses — but doesn't auto-detect version or show it)

- [ ] **Step 3: Write minimal implementation**

Update the `parse` command in `mykovolt/cli.py` to use `parse_entries_versioned`:

```python
from mykovolt.schema import (
    SensorEntry,
    TestFixtureEntry,
    parse_header,
    parse_entries_versioned,
    FRAM_DATA_START,
    FRAM_MAX_ENTRIES,
)
```

Replace the body of `parse()` (lines 93-114):

```python
@cli.command()
@click.argument("input", type=click.Path(exists=True))
@click.option("--output", "-o", default=None, help="Output file")
@click.option("--format", "-f", "fmt", default="csv", help="Output format")
@click.option("--calibration", "-c", default=None, help="Calibration JSON file")
def parse(input, output, fmt, calibration):
    """Parse raw FRAM binary dump."""
    with open(input, "rb") as f:
        data = f.read()
    header = parse_header(data)
    if header is None:
        click.echo("Invalid FRAM header", err=True)
        sys.exit(1)
    click.echo(f"Header: magic=0x{header.magic:04X} version={header.version} "
               f"write_ptr={header.write_ptr}")
    entries = parse_entries_versioned(header, data[FRAM_DATA_START:])
    if calibration and header.version == 1:
        cal = load_calibration(calibration)
        entries = [apply_calibration(e, cal) for e in entries]
    click.echo(f"Parsed {len(entries)} entries (v{header.version})")
    buf = open(output, "w") if output else sys.stdout
    if fmt == "csv":
        export_csv(entries, buf)
    else:
        export_json(entries, buf)
    if output:
        buf.close()
        click.echo(f"Wrote {len(entries)} entries to {output}")
```

- [ ] **Step 4: Run tests to verify they pass**

Run: `cd /home/weissto_local/git/mykovolt && python -m pytest tests/test_cli.py -v`
Expected: All tests PASS

- [ ] **Step 5: Commit**

```bash
git add mykovolt/cli.py tests/test_cli.py
git commit -m "feat: version-aware FRAM parsing in CLI parse command"
```

---

### Task 4: CalibratedModel Class

**Files:**
- Create: `mykovolt/calibrate_sim.py`
- Test: `tests/test_calibrate_sim.py`

- [ ] **Step 1: Write the failing test**

```python
# tests/test_calibrate_sim.py

import pytest
from mykovolt.calibrate_sim import CalibratedModel, fit_model, model_params_to_yaml, model_params_from_yaml

def test_calibrated_model_predicts_power():
    m = CalibratedModel(power_density_uw_cm2=12.5, activation_loss=0.05,
                        ohmic_loss_r_cm2=50.0, depletion_rate=0.02)
    power = m.power_at_current(0.0)  # zero load = raw power
    assert power > 0
    power_loaded = m.power_at_current(1.0)  # 1 mA load
    assert power_loaded < power  # losses reduce power
    assert power_loaded > 0

def test_calibrated_model_iv_curve():
    m = CalibratedModel(power_density_uw_cm2=12.5)
    iv = m.iv_curve(area_cm2=19.63, currents_ma=[0, 0.5, 1.0, 2.0, 5.0])
    assert len(iv) == 5
    assert iv[0].voltage > iv[1].voltage  # voltage drops with current
    assert iv[0].current_ma == 0

def test_fit_model_synthetic():
    """Generate synthetic data, fit, check params recovered."""
    import random
    random.seed(42)
    true_params = {
        "power_density_uw_cm2": 15.0,
        "ohmic_loss_r_cm2": 80.0,
        "depletion_rate": 0.03,
    }
    m_true = CalibratedModel(**true_params)
    measurements = []
    for day in range(30):
        current = random.uniform(0.1, 2.0)
        voltage = m_true.voltage_at_current(current, day=day, area_cm2=19.63)
        measurements.append({
            "day": day,
            "current_ma": current,
            "voltage_mv": voltage,
        })
    fitted = fit_model(measurements, area_cm2=19.63)
    assert abs(fitted.power_density_uw_cm2 - 15.0) < 5.0  # within 33%
    assert abs(fitted.depletion_rate - 0.03) < 0.02

def test_model_params_yaml_roundtrip(tmp_path):
    m = CalibratedModel(power_density_uw_cm2=12.5, ohmic_loss_r_cm2=50.0,
                        depletion_rate=0.02)
    path = tmp_path / "params.yaml"
    model_params_to_yaml(m, path)
    m2 = model_params_from_yaml(path)
    assert m2.power_density_uw_cm2 == pytest.approx(m.power_density_uw_cm2)
    assert m2.ohmic_loss_r_cm2 == pytest.approx(m.ohmic_loss_r_cm2)
    assert m2.depletion_rate == pytest.approx(m.depletion_rate)
```

- [ ] **Step 2: Run test to verify it fails**

Run: `cd /home/weissto_local/git/mykovolt && python -m pytest tests/test_calibrate_sim.py -v`
Expected: FAIL with `ModuleNotFoundError: No module named 'mykovolt.calibrate_sim'`

- [ ] **Step 3: Write minimal implementation**

Create `mykovolt/calibrate_sim.py`:

```python
"""Calibrated pressling power model with parameter fitting."""

from __future__ import annotations
import math
from dataclasses import dataclass
from pathlib import Path

@dataclass
class IVPoint:
    voltage_mv: float
    current_ma: float
    power_uw: float

@dataclass
class CalibratedModel:
    power_density_uw_cm2: float = 12.5
    activation_loss: float = 0.05
    ohmic_loss_r_cm2: float = 50.0
    depletion_rate: float = 0.02

    def raw_power_uw(self, area_cm2: float, day: int = 0) -> float:
        decay = (1 - self.depletion_rate) ** day
        return self.power_density_uw_cm2 * area_cm2 * decay

    def voltage_oc_mv(self, area_cm2: float, day: int = 0) -> float:
        """Approximate open-circuit voltage from power density.
        
        V_OC ≈ sqrt(4 * P * R_internal) for a simple MFC model.
        Typical range: 300-600 mV.
        """
        p = self.raw_power_uw(area_cm2, day)
        r = self.ohmic_loss_r_cm2 / area_cm2  # effective R scales with 1/area
        voc = math.sqrt(max(4 * p * 1e-6 * r, 1e-12)) * 1000
        return max(min(voc, 800.0), 50.0)

    def voltage_at_current(self, current_ma: float, area_cm2: float = 19.63,
                           day: int = 0) -> float:
        voc = self.voltage_oc_mv(area_cm2, day)
        r_eff = self.ohmic_loss_r_cm2 / area_cm2
        activation = self.activation_loss * math.log1p(current_ma) * 100 if current_ma > 0 else 0
        v = voc - current_ma * r_eff - activation
        return max(v, 0.0)

    def power_at_current(self, current_ma: float, area_cm2: float = 19.63,
                        day: int = 0) -> float:
        v = self.voltage_at_current(current_ma, area_cm2, day)
        return v * current_ma

    def iv_curve(self, area_cm2: float = 19.63,
                 currents_ma: list[float] | None = None) -> list[IVPoint]:
        if currents_ma is None:
            currents_ma = [i * 0.1 for i in range(51)]  # 0 to 5 mA
        points = []
        for i_ma in currents_ma:
            v = self.voltage_at_current(i_ma, area_cm2)
            p = v * i_ma
            points.append(IVPoint(voltage_mv=v, current_ma=i_ma, power_uw=p))
        return points

def fit_model(measurements: list[dict], area_cm2: float = 19.63,
              n_grid: int = 20) -> CalibratedModel:
    """Fit model parameters to measured I/V data using grid search.
    
    Each measurement dict: {"day", "current_ma", "voltage_mv"}.
    Uses brute-force grid search (no scipy dependency).
    """
    best_model = CalibratedModel()
    best_error = float("inf")

    for pd in [i * (30.0 / n_grid) + 5.0 for i in range(n_grid)]:
        for rl in [i * (200.0 / n_grid) + 10.0 for i in range(n_grid)]:
            for dr in [i * (0.05 / n_grid) for i in range(n_grid)]:
                m = CalibratedModel(power_density_uw_cm2=pd,
                                    ohmic_loss_r_cm2=rl,
                                    depletion_rate=dr)
                error = 0.0
                for meas in measurements:
                    v_pred = m.voltage_at_current(
                        meas["current_ma"], area_cm2, day=meas.get("day", 0)
                    )
                    error += (v_pred - meas["voltage_mv"]) ** 2
                if error < best_error:
                    best_error = error
                    best_model = m

    return best_model

def model_params_to_yaml(model: CalibratedModel, path: Path | str) -> None:
    lines = [
        f"power_density_uw_cm2: {model.power_density_uw_cm2:.4f}",
        f"activation_loss: {model.activation_loss:.4f}",
        f"ohmic_loss_r_cm2: {model.ohmic_loss_r_cm2:.4f}",
        f"depletion_rate: {model.depletion_rate:.6f}",
    ]
    Path(path).write_text("\n".join(lines) + "\n")

def model_params_from_yaml(path: Path | str) -> CalibratedModel:
    text = Path(path).read_text()
    params = {}
    for line in text.strip().splitlines():
        if ":" in line:
            key, val = line.split(":", 1)
            params[key.strip()] = float(val.strip())
    return CalibratedModel(
        power_density_uw_cm2=params.get("power_density_uw_cm2", 12.5),
        activation_loss=params.get("activation_loss", 0.05),
        ohmic_loss_r_cm2=params.get("ohmic_loss_r_cm2", 50.0),
        depletion_rate=params.get("depletion_rate", 0.02),
    )
```

- [ ] **Step 4: Run tests to verify they pass**

Run: `cd /home/weissto_local/git/mykovolt && python -m pytest tests/test_calibrate_sim.py -v`
Expected: All 4 tests PASS

- [ ] **Step 5: Commit**

```bash
git add mykovolt/calibrate_sim.py tests/test_calibrate_sim.py
git commit -m "feat: add CalibratedModel with grid-search fitting and YAML I/O"
```

---

### Task 5: Geometry Sweep & Multi-Cell Model

**Files:**
- Create: `simulation/calibrated_pressling.py`
- Test: `tests/test_calibrated_pressling.py`

- [ ] **Step 1: Write the failing test**

```python
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

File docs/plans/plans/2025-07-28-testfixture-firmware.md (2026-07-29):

# Test Fixture Firmware Implementation Plan

> **For agentic workers:** REQUIRED SUB-SKILL: Use superpowers:subagent-driven-development (recommended) or superpowers:executing-plans to implement this plan task-by-task. Steps use checkbox (`- [ ]`) syntax for tracking.

**Goal:** Create the test fixture firmware — INA219/SHT30 drivers, load bank control, and a measurement application with three modes (V_OC tracking, I/V sweep, load life test) that logs v2 FRAM entries.

**Architecture:** The test fixture is a firmware variant of the dev kit. New I2C drivers (INA219, SHT30) go in `Core/Inc` and `Core/Src` as shared infrastructure. A `testfixture/` directory holds the test fixture application (config header, main.c, CMakeLists.txt). The build produces a separate `mykovolt_testfixture.elf` target. The existing dev kit firmware remains untouched.

**Tech Stack:** C99, bare-metal STM32L011 (Cortex-M0+), ARM GCC cross-compiler, CMake build system, no HAL (direct register access)

---

## File Structure

| File | Responsibility |
|---|---|
| `firmware/Core/Inc/i2c_driver.h` | Add `i2c_read_raw()` declaration (raw read without register address) |
| `firmware/Core/Src/i2c_driver.c` | Implement `i2c_read_raw()` |
| `firmware/Core/Inc/ina219.h` | INA219 register map + public API |
| `firmware/Core/Src/ina219.c` | INA219 driver: init, read voltage/current/power |
| `firmware/Core/Inc/sht30.h` | SHT30 command defines + public API |
| `firmware/Core/Src/sht30.c` | SHT30 driver: init, read temp/humidity |
| `firmware/testfixture/testfixture_config.h` | Test fixture pin mappings, I2C addresses, FRAM v2 constants, load bank defs |
| `firmware/testfixture/testfixture_main.c` | Test fixture application: GPIO init, 3 measurement modes, v2 FRAM ring buffer, NFC command handling |
| `firmware/testfixture/CMakeLists.txt` | CMake build for `mykovolt_testfixture` target |

---

### Task 1: Add `i2c_read_raw()` to I2C driver

The SHT30 sensor uses command-based I2C (no register address for reads). After writing a 2-byte command, the master must read data bytes directly without sending a register address first. The existing `i2c_read_reg` and `i2c_read_reg16` both send a register address before reading. We need a raw read function.

**Files:**
- Modify: `firmware/Core/Inc/i2c_driver.h`
- Modify: `firmware/Core/Src/i2c_driver.c`

- [ ] **Step 1: Add declaration to i2c_driver.h**

Add after the `i2c_read_reg8` inline function (after line 76, before the "Status / Debug" section):

```c
/* ── Raw I2C (no register address) ── */

/**
 * Read data from an I2C slave without sending a register address first.
 * Used by command-based devices like SHT30.
 * @param addr  7-bit slave address
 * @param data  Buffer for received data
 * @param len   Number of bytes to read
 * @return true on ACK, false on NACK/timeout
 */
bool i2c_read_raw(uint8_t addr, uint8_t *data, uint16_t len);
```

- [ ] **Step 2: Implement in i2c_driver.c**

Add at the end of the file (after `i2c_read_reg16`, before the final blank line):

```c
/* ========================================================================
 *   Raw read (no register address)
 * ======================================================================== */

bool i2c_read_raw(uint8_t addr, uint8_t *data, uint16_t len) {
    if (i2c_busy || len == 0) return false;
    i2c_busy = true;

    if (!wait_for_flag(I2C_ISR_BUSY, false)) {
        I2C1->ICR = 0xFFFFFFFF;
        i2c_busy = false;
        return false;
    }

    /* Start + read directly (no register address phase) */
    I2C1->CR2 = (addr << 1) | I2C_CR2_START | I2C_CR2_RD_WRN;
    I2C1->CR2 |= len | I2C_CR2_AUTOEND;

    for (uint16_t i = 0; i < len; i++) {
        if (!wait_for_flag(I2C_ISR_RXNE, true)) {
            i2c_busy = false;
            return false;
        }
        data[i] = I2C1->RXDR;
    }

    if (!wait_for_flag(I2C_ISR_STOPF, true)) {
        i2c_busy = false;
        return false;
    }

    I2C1->ICR = I2C_ICR_STOPCF;
    i2c_busy = false;
    return true;
}
```

- [ ] **Step 3: Verify dev kit firmware still compiles**

Run: `cd firmware/build && cmake .. && make -j4`
Expected: PASS — `[100%] Built target mykovolt_firmware` (existing build unaffected)

- [ ] **Step 4: Commit**

```bash
git add firmware/Core/Inc/i2c_driver.h firmware/Core/Src/i2c_driver.c
git commit -m "feat: add i2c_read_raw() for command-based I2C devices"
```

---

### Task 2: INA219 driver

The INA219 is a I2C current/voltage/power sensor with a shunt resistor. It measures bus voltage (0-26V or 0-32V) and shunt voltage (±320mV). The test fixture uses it to measure pressling output voltage and current.

Shunt resistor: 0.1 Ω. Bus voltage range: 32V. ADC: 12-bit.

**Register map:**
- 0x00 Configuration (16-bit)
- 0x01 Shunt voltage (16-bit, signed, 10µV/LSB)
- 0x02 Bus voltage (16-bit, bits[15:3] = voltage in 4mV steps, bit[1] = CNVR, bit[0] = OVF)
- 0x03 Power (16-bit)
- 0x04 Current (16-bit, signed)
- 0x05 Calibration (16-bit)

**Files:**
- Create: `firmware/Core/Inc/ina219.h`
- Create: `firmware/Core/Src/ina219.c`

- [ ] **Step 1: Create ina219.h**

```c
/**
 * @file    ina219.h
 * @brief   INA219 current/voltage/power sensor driver (I2C)
 *
 * Datasheet: Texas Instruments INA219, I2C 26V/32V Bus Voltage Monitor
 * Protocol:  7-bit addr 0x40 (configurable via A0/A1), 8-bit register addressing
 */

#ifndef __INA219_H
#define __INA219_H

#ifdef __cplusplus
extern "C" {
#endif

#include <stdint.h>
#include <stdbool.h>

/* ── Registers ── */

#define INA219_REG_CONFIG       0x00
#define INA219_REG_SHUNT_VOLT   0x01
#define INA219_REG_BUS_VOLT     0x02
#define INA219_REG_POWER        0x03
#define INA219_REG_CURRENT      0x04
#define INA219_REG_CALIBRATION  0x05

/* ── Config defaults ── */

/* 32V range, PGA /8 (±320mV), 12-bit bus+shunt, continuous mode */
#define INA219_CONFIG_DEFAULT   0x399F

/* Shunt resistor in milliohms (0.1 Ω = 100 mΩ) */
#define INA219_SHUNT_MOHM       100

/* ── Public API ── */

/** Initialise INA219 (writes config register, verifies device presence) */
bool ina219_init(void);

/** Read bus voltage in millivolts (returns 0xFFFF on error) */
uint16_t ina219_read_voltage_mv(void);

/** Read shunt current in milliamps, signed (returns 0x7FFF on error) */
int16_t ina219_read_current_ma(void);

/** Read computed power in milliwatts (returns 0xFFFF on error) */
uint16_t ina219_read_power_mw(void);

/** Check if a new conversion is ready (returns true if ready) */
bool ina219_conversion_ready(void);

#ifdef __cplusplus
}
#endif

#endif /* __INA219_H */
```

- [ ] **Step 2: Create ina219.c**

```c
/**
 * @file    ina219.c
 * @brief   INA219 current/voltage/power sensor driver
 *
 * Datasheet: Texas Instruments INA219, Zero-Drift Bidirectional
 *            Current/Power Monitor With I2C Interface
 *
 * With 0.1 Ω shunt and default config:
 *   - Bus voltage LSB = 4 mV
 *   - Shunt voltage LSB = 10 µV
 *   - Current = shunt_voltage / R_shunt = (raw × 10 µV) / 0.1 Ω = raw × 100 µA = raw × 0.1 mA
 */

#include "ina219.h"
#include "i2c_driver.h"
#include "mykovolt.h"

/* I2C address — defined in testfixture_config.h, fallback for dev kit compatibility */
#ifndef I2C_ADDR_INA219
#define I2C_ADDR_INA219 0x40
#endif

/* ======== Private helpers ======== */

static uint16_t read_reg_u16(uint8_t reg) {
    uint8_t buf[2];
    if (!i2c_read_reg(I2C_ADDR_INA219, reg, buf, 2)) {
        return 0xFFFF;
    }
    return ((uint16_t)buf[0] << 8) | buf[1];
}

static bool write_reg_u16(uint8_t reg, uint16_t val) {
    uint8_t buf[2];
    buf[0] = (uint8_t)(val >> 8);
    buf[1] = (uint8_t)(val);
    return i2c_write_reg(I2C_ADDR_INA219, reg, buf, 2);
}

/* ======== Public API ======== */

bool ina219_init(void) {
    if (!write_reg_u16(INA219_REG_CONFIG, INA219_CONFIG_DEFAULT)) {
        return false;
    }
    /* Verify by reading back config */
    uint16_t cfg = read_reg_u16(INA219_REG_CONFIG);
    if (cfg == 0xFFFF) {
        return false;
    }
    return true;
}

uint16_t ina219_read_voltage_mv(void) {
    uint16_t raw = read_reg_u16(INA219_REG_BUS_VOLT);
    if (raw == 0xFFFF) {
        return 0xFFFF;
    }
    /* Bits [15:3] are the voltage in 4mV steps; bit[1] = CNVR, bit[0] = OVF */
    if (raw & 0x0001) {
        /* Overflow — measurement is invalid */
        return 0xFFFF;
    }
    return (raw >> 3) * 4;
}

int16_t ina219_read_current_ma(void) {
    uint16_t raw = read_reg_u16(INA219_REG_SHUNT_VOLT);
    if (raw == 0xFFFF) {
        return 0x7FFF;
    }
    /* Shunt voltage is signed 16-bit, 10 µV/LSB */
    int16_t shunt_raw = (int16_t)raw;
    /* Current = V_shunt / R_shunt = (shunt_raw × 10 µV) / 0.1 Ω
     *         = shunt_raw × 100 µA = shunt_raw × 0.1 mA
     * So current in mA = shunt_raw / 10 (integer math, 0.1 mA resolution) */
    return shunt_raw / 10;
}

uint16_t ina219_read_power_mw(void) {
    uint16_t v_mv = ina219_read_voltage_mv();
    int16_t i_ma = ina219_read_current_ma();
    if (v_mv == 0xFFFF || i_ma == 0x7FFF) {
        return 0xFFFF;
    }
    if (i_ma < 0) {
        /* Negative current — no power delivered */
        return 0;
    }
    /* Power = V × I / 1000 (mV × mA = µW, /1000 = mW) */
    return (uint16_t)((v_mv * (uint16_t)i_ma) / 1000);
}

bool ina219_conversion_ready(void) {
    uint16_t raw = read_reg_u16(INA219_REG_BUS_VOLT);
    if (raw == 0xFFFF) {
        return false;
    }
    /* Bit [1] of bus voltage register = conversion ready */
    return (raw & 0x0002) != 0;
}
```

- [ ] **Step 3: Verify it compiles standalone (syntax check)**

Run: `arm-none-eabi-gcc -c -mcpu=cortex-m0plus -mthumb -Os -Wall -Wextra -Werror=implicit-function-declaration -I firmware/Core/Inc -DSTM32L011xx firmware/Core/Src/ina219.c -o /tmp/ina219.o`
Expected: PASS — no errors or warnings

- [ ] **Step 4: Commit**

```bash
git add firmware/Core/Inc/ina219.h firmware/Core/Src/ina219.c
git commit -m "feat: add INA219 current/voltage/power sensor driver"
```

---

### Task 3: SHT30 driver

The SHT30 is an I2C temperature and humidity sensor. It uses command-based addressing: the master writes a 2-byte command, waits for conversion, then reads 6 bytes (temp MSB, temp LSB, temp CRC8, humidity MSB, humidity LSB, humidity CRC8).

**Files:**
- Create: `firmware/Core/Inc/sht30.h`
- Create: `firmware/Core/Src/sht30.c`

- [ ] **Step 1: Create sht30.h**

```c
/**
 * @file    sht30.h
 * @brief   SHT30 temperature + humidity sensor driver (I2C)
 *
 * Datasheet: Sensirion SHT30, Digital Humidity and Temperature Sensor
 * Protocol:  7-bit addr 0x44, command-based (2-byte commands, no register addressing)
 */

#ifndef __SHT30_H
#define __SHT30_H

#ifdef __cplusplus
extern "C" {
#endif

#include <stdint.h>
#include <stdbool.h>

/* ── Commands ── */

/* Single-shot mode, clock stretching enabled, high repeatability */
#define SHT30_CMD_SINGLESHOT_H   0x2C06
/* Single-shot mode, clock stretching enabled, medium repeatability */
#define SHT30_CMD_SINGLESHOT_M   0x2C0D
/* Single-shot mode, clock stretching enabled, low repeatability */
#define SHT30_CMD_SINGLESHOT_L   0x2C10
/* Soft reset */
#define SHT30_CMD_SOFT_RESET     0x30A2
/* Read status register */
#define SHT30_CMD_READ_STATUS    0xF32D

/* ── Public API ── */

/** Initialise SHT30 (soft reset + verify status register) */
bool sht30_init(void);

/**
 * Read temperature and humidity (blocking, ~15ms conversion time).
 * @param temp_c  Output: temperature in degrees Celsius (signed, -40 to +125)
 * @param rh_pct  Output: relative humidity in percent (0 to 100)
 * @return true on success, false on I2C/CRC error
 */
bool sht30_read(int8_t *temp_c, uint8_t *rh_pct);

#ifdef __cplusplus
}
#endif

#endif /* __SHT30_H */
```

- [ ] **Step 2: Create sht30.c**

```c
/**
 * @file    sht30.c
 * @brief   SHT30 temperature + humidity sensor driver
 *
 * Datasheet: Sensirion SHT30, Digital Humidity and Temperature Sensor
 *
 * Conversion formulas (from datasheet):
 *   T = -45 + 175 * (S_T / 65535)    [°C, signed]
 *   RH = 100 * (S_RH / 65535)        [%RH, unsigned]
 *
 * CRC-8: polynomial 0x31, initial value 0xFF
 */

#include "sht30.h"
#include "i2c_driver.h"
#include "mykovolt.h"

/* I2C address — defined in testfixture_config.h, fallback for dev kit compatibility */
#ifndef I2C_ADDR_SHT30
#define I2C_ADDR_SHT30 0x44
#endif

/* ======== Private helpers ======== */

static bool send_command(uint16_t cmd) {
    /* Use i2c_write_reg16 with len=0 to send just the 2-byte command */
    return i2c_write_reg16(I2C_ADDR_SHT30, cmd, (const uint8_t *)0, 0);
}

static uint8_t crc8(const uint8_t *data, uint8_t len) {
    uint8_t crc = 0xFF;
    for (uint8_t i = 0; i < len; i++) {
        crc ^= data[i];
        for (uint8_t b = 0; b < 8; b++) {
            if (crc & 0x80) {
                crc = (crc << 1) ^ 0x31;
            } else {
                crc <<= 1;
            }
        }
    }
    return crc;
}

/* ======== Public API ======== */

bool sht30_init(void) {
    /* Soft reset */
    if (!send_command(SHT30_CMD_SOFT_RESET)) {
        return false;
    }
    /* Wait for reset (max 1.5ms per datasheet) */
    for (volatile int i = 0; i < 5000; i++);

    /* Read status register to verify device is alive */
    uint8_t status[3];
    if (!i2c_read_reg16(I2C_ADDR_SHT30, SHT30_CMD_READ_STATUS, status, 3)) {
        return false;
    }
    /* Verify CRC */
    if (crc8(status, 2) != status[2]) {
        return false;
    }
    return true;
}

bool sht30_read(int8_t *temp_c, uint8_t *rh_pct) {
    /* Send single-shot command (clock stretching, high repeatability) */
    if (!send_command(SHT30_CMD_SINGLESHOT_H)) {
        return false;
    }

    /* Read 6 bytes: T_msb, T_lsb, T_crc, RH_msb, RH_lsb, RH_crc */
    uint8_t data[6];
    if (!i2c_read_raw(I2C_ADDR_SHT30, data, 6)) {
        return false;
    }

    /* Verify CRCs */
    if (crc8(data, 2) != data[2]) {
        return false;
    }
    if (crc8(data + 3, 2) != data[5]) {
        return false;
    }

    /* Convert raw values */
    uint16_t raw_t = ((uint16_t)data[0] << 8) | data[1];
    uint16_t raw_rh = ((uint16_t)data[3] << 8) | data[4];

    /* T = -45 + 175 * raw / 65535 → integer math:
     * temp_c = -45 + (175 * raw_t) / 65535
     * To avoid overflow with 32-bit: (175 * raw_t) can be up to 175*65535 = 11,468,625 (fits in 32-bit) */
    int32_t temp_x100 = -4500 + (17500 * (int32_t)raw_t) / 65535;
    /* Round to nearest degree */
    int8_t temp = (int8_t)((temp_x100 + 50) / 100);

    /* RH = 100 * raw / 65535 → integer math:
     * rh = (100 * raw_rh) / 65535, clamped to [0, 100] */
    uint8_t rh = (uint8_t)((100 * raw_rh) / 65535);
    if (rh > 100) rh = 100;

    if (temp_c) *temp_c = temp;
    if (rh_pct) *rh_pct = rh;

    return true;
}
```

- [ ] **Step 3: Verify it compiles standalone (syntax check)**

Run: `arm-none-eabi-gcc -c -mcpu=cortex-m0plus -mthumb -Os -Wall -Wextra -Werror=implicit-function-declaration -I firmware/Core/Inc -DSTM32L011xx firmware/Core/Src/sht30.c -o /tmp/sht30.o`
Expected: PASS — no errors or warnings

- [ ] **Step 4: Commit**

```bash
git add firmware/Core/Inc/sht30.h firmware/Core/Src/sht30.c
git commit -m "feat: add SHT30 temperature/humidity sensor driver"
```

---
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

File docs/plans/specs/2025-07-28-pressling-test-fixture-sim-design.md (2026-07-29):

# Pressling Test Fixture & Simulation Calibration Design

**Datum:** 2025-07-28
**Status:** Draft — awaiting user approval
**Scope:** Cell-agnostic pressling test PCB + simulation calibration loop

---

## 1. Overview

The pressling (fungal MFC) is an experimental power source — its viability as a real energy supply for MykoVolt is unproven. This design creates the tooling to **measure, compare, and iterate** on pressling power generation across many cell form factors, electrode materials, and environmental conditions.

### Two-Track Strategy

| Track | Role | Status |
|---|---|---|
| **Dev Kit** | Application PCB — FDC1004 soil moisture sensor, FRAM logging, NFC readout | Existing, unchanged |
| **Test Fixture** | Measurement PCB — characterizes any pressling/cell form, logs I/V data via NFC | New, this spec |

The test fixture answers: *Can a pressling deliver enough current to run the dev kit (or a future wireless node)?* If not, the fallback is a PHA 3D-printed biopolymer enclosure with a small primary cell (CR2032 or similar).

---

## 2. Test Fixture PCB Specification

### 2.1 Requirements

1. Accept **any cell form factor** via screw terminals (disc, cylinder, pouch, series stack, parallel array)
2. Measure **open-circuit voltage (V_OC)** and **current under programmable loads**
3. Log measurements to FRAM with RTC timestamps for long-duration unattended tests (days–weeks)
4. Provide NFC readout so data can be collected without opening the test chamber
5. Record environmental conditions (temperature, humidity) alongside power data
6. Be powered by USB during benchtop use, or by the pressling itself for in-soil tests

### 2.2 Hardware Components

| Component | Role | Package |
|---|---|---|
| STM32L011F4 | MCU (same as dev kit) | UFQFPN-20 |
| MB85RC16 | 2KB FRAM ring buffer (same as dev kit) | SOT-23-5 |
| ST25DV04K | NFC tag for data readout (same as dev kit) | SOIC-8 |
| PCF8523 | RTC for timestamps (same as dev kit) | SOIC-8 |
| INA219 | Current/voltage/power sensor (I2C) | SOT-23-8 |
| SHT30 | Temperature + humidity (I2C) | SOT-23-5 |
| BQ25570 | Boost converter (optional — bypassable via jumper) | VQFN-16 |
| 4× MOSFET + load resistors | Programmable load bank (4 steps) | SOT-23 |
| 4× screw terminals | Cell connection (anode, cathode, Vsense+, Vsense-) | 5mm pitch |
| USB-C | Bench power and debug | USB-C receptacle |

### 2.3 Screw Terminal Configuration

The 4 terminals are the core of the "accept anything" approach:

- **ANODE** — connects to cell anode
- **CATHODE** — connects to cell cathode
- **VSENSE+** — high-side current shunt input (INA219)
- **VSENSE−** — low-side current shunt input (INA219)

The user wires the cell terminals to ANODE/CATHODE for power. For precision current measurement, the cell also connects to VSENSE+/VSENSE− (4-wire measurement, eliminates contact resistance). Both configurations are supported.

### 2.4 Load Bank

Four MOSFET-switched load resistors provide programmable I/V curve sweeps:

| Load | Resistance | Current at 0.4V | Use |
|---|---|---|---|
| R1 (trickle) | 10 kΩ | 40 µA | Continuous light load |
| R2 (low) | 100 Ω | 4 mA | Light continuous load |
| R3 (medium) | 10 Ω | 40 mA | Moderate load |
| R4 (heavy) | 1 Ω | 400 mA | Heavy load / short-circuit test |

Loads are engaged individually or in parallel via GPIO-controlled MOSFETs. This allows the firmware to sweep an I/V curve by enabling each load step and recording the steady-state voltage and current via INA219.

### 2.5 Power Architecture

Two modes:

1. **USB powered (benchtop):** USB-C provides 5V. BQ25570 is bypassed via jumper. INA219 and MCU run from USB. Pressling connects only to screw terminals for measurement.

2. **Pressling powered (in-soil):** No USB. BQ25570 boosts pressling voltage to 3.3V for MCU, FRAM, NFC. INA219 runs directly from pressling rail (operates down to 0V Vbus). Load bank drains from pressling directly — this is the power being measured.

### 2.6 PCB Physical

- Same 4-layer FR-4 stack as dev kit (F.Cu, In1.Cu, In2.Cu, B.Cu)
- 30×20 mm (same footprint as dev kit)
- Same connector/antenna layout for NFC

### 2.7 Measurements Logged Per Entry

Each FRAM entry (12 bytes) stores:

| Field | Type | Bytes |
|---|---|---|
| timestamp (seconds since epoch) | uint32 | 4 |
| V_OC (mV) | uint16 | 2 |
| load_current (mA, signed) | int16 | 2 |
| load_resistor_index (0=none, 1-4=R1-R4) | uint8 | 1 |
| temperature (°C, signed) | int8 | 1 |
| humidity (% RH) | uint8 | 1 |
| status flags | uint8 | 1 |
| CRC | uint8 | 1 |
| **Total** | | **12 bytes** |

149 entries × 12 bytes = 1788 bytes in the 2048-byte FRAM (256 bytes reserved for header, same as dev kit).
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

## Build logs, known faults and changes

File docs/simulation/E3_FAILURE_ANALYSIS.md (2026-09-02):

# E3 Co-Culture Simulation — Failure Analysis (2026-09-03)

> **Status:** ❌ `sim_e3.py` is **structurally invalid** for the hypothesis.
> This file documents **why no simulation result is trustworthy** — so the
> repo never ships a fake co-culture gain. Do NOT quote the 0.12×–12.2×
> numbers the script emits during iteration; they are deterministic
> artifacts of degenerate dynamics, not fungal electrochemistry.

## The Claim We Tested
> A *T. versicolor* + *P. ostreatus* co-culture on a Mg-air cell amplifies
> power **super-additively** beyond the single-strain results (E1 laccase
> boost + E2 air-channel gain). Papers: #47, #56, #45, #109.

## The Three Structural Blockers (proven via trajectory debug)

| # | Symptom in `sim_e3.py` | Root cause | Why it corrupts the result |
|---|---|---|---|
| **1. Logistic collapse kills all variance** | All 2,000 Monte-Carlo runs converge to **identical final state** (Mg=0.4985, O2=0.209, pH=5.0); P10==P50==P90 for every depth. | `dT = MU_T·T·(1−T/K)·...` drives T,P to carrying capacity **K=1e8 within 24 h**, then `dT,dP → 0`. Once biomass locks, corrosion/O₂/pH/power lose all state-dependence → noise vanishes (±5% on derivatives of zero). | A stochastic 14-day simulator **physically cannot** show zero variance. The model has degenerated to a fixed-point attractor. |
| **2. Depth response is inverted** | `depth_factor(20, 0.209) = 2.4` — the **20 cm case reports more power than surface**. | `gain = O2 / O2_only_at_depth`; at surface O₂=0.209 → gain=8.36 → capped at 2.4 (HYP_PERM). The formula rewards *high* ambient O₂ at *deep* depths (wrong sign); and O₂ replenish (`k_diff·(O2_SURF−O2)`) keeps O₂ pinned at 0.209 everywhere → **no real depth gradient forms**. | Reproduces *none* of #47's depth curve (480→850→320→60→12 µW). Deeper should mean *less* O₂ → *less* power, not more. |
| **3. OCV / corrosion decoupled from delivered current** | Power is clamped to `min(boost_conv, LOAD_DEMAND=150µW)` then ×depth_factor. The **cell never starves** → `Mg_exhausted` gate never trips even at 0.12× surface power. | `i_parasite = CORR_PAR/24 / CORR_AH` uses a **static parasitic drain** unrelated to actual operating current; delivered-current contribution to Mg loss is negligible by comparison, so Mg declines at the open-circuit rate regardless of power draw. | Violates Faraday coupling (#56): at low current, Mg self-corrosion *should* dominate life; the model can't show "biology accelerates corrosion until anode collapse" (#88). |

## Evidence: trajectory debug (seed=0, depth=2cm, first 20 h)

```
h=0:  T=1e5 → pwr=54.8 µW  (realistic, matches #109 order-of-magnitude)
h=20: T=1.68e7, P=4.13e8  (logistic blow-up begins)
h~30: T,P → 1e8 (K)        (derivatives → 0)
h=336: all seeds identical  (no stochastic spread survives)
```
→ The single-cell voltage/polarization (#109: 54.8 µW) is physically sane.
→ But the **population dynamics kill every signal** afterward.

## What a *correct* model needs
1. **Spatially resolved O₂** — a 1-D diffusion PDE through the soil-column
   (surface 0.209 → 20 cm 0.03), with *hyphal permeability as a spatially
   varying diffusivity* (#47: mycelium lifts the 20cm O₂ from 6% → 16%).
   A single well-mixed compartment **cannot** represent a depth gradient.
2. **Coupled growth ↔ resource depletion** — T and P growth rate must
   *degrade* as O₂ or Mg depletes, not run to a fixed carrying capacity.
3. **Coulomb-counted Mg with state dependence** — anode loss must scale
   with *delivered* current at the *operating voltage*, so low-power
   depth operation genuinely extends life (#56).

This is a **genuine sub-project** (≈2 days), not a one-line fix.

## Papers grounding the failure verdict (all CrossRef-verified)
| Paper | Finding | Implication for E3 |
|---|---|---|
| `10.1038/s41564-021-00983-5` (#71) | Co-cultures **rarely synergistic** without engineered cross-talk | Low prior — explains why the "simple" ODE shows no gain |
| `10.1016/j.electacta.2011.12.026` (#45) | Laccase biocathode benefit measured at **1 mA/cm²** (Zn-air) | At Mg-air's **µA** regime, laccase overpotential gain is marginal (hence our flat 55 µW) |
| `10.1016/j.electacta.2016.07.073` (#56) | Mg corrosion is **parasitic-dominated** (self-discharge > useful current) | A correct model MUST show Mg-depletion as the dominant lifetime limiter |
| `10.1016/j.biort.2023.04.006` (#47) | 5× recovery via **spatial** hyphal air-channels | Requires spatial PDE, not ODE |

## Honest current verdict
> **E3 co-culture amplification is *unproven* and currently *not predicted* by any
> structurally valid model in this repo.** The only verified Mg-air gains
> remain E1 (laccase biocathode, +16 % at surface) and E2 (hyphal
> air-channel, **5× depth recovery**). Co-culture adds the #71 low-synergy
> risk on top of the already-marginal E1 benefit.

## TaskFleet record
| Task | Title | Status |
|---|---|---|
| `T-8cb82f6a` | E3.0a: MPPT impedance model | ✅ committed (`sim_e3.py` v3) |
| `T-024f3e10` | E3.0b: O2 diffusion + Coulomb-counting | ⚠️ implemented but **structurally limited** (blockers above) |
| `T-31c89739` | E3.0c: Calibrate to #47 within ±20% | ❌ **blocked** — no valid calibration until blockers fixed |
| `T-4ce2a8a9` | E3.0 MASTER: gains + Go/No-Go @ 4 depths | ❌ **blocked** — subordinate to E3.0c |

## What to do next (your call)
- **(A)** Close E3 as "*unproven — defer to E1/E2 single-strain MVP*" (Mg-air remains the verified core battery; mushrooms = upgrade only if E1/E2 bench-beats baseline).
- **(B)** Allocate ~2 dev-days for a **spatial PDE model** (genuinely reproduces #47 depth curve) — *only if* you want the co-culture hypothesis quantified rather than bench-tested.
- **(C)** **Run E1 + E2 bench first**, measure real 12.5 µW/cm² + 5×-depth-recover, and *then* decide if co-culture is worth a bench trial — the verified single-strain data will bound the hypothesis without simulation.

*No simulation output in `sim_e3.py` should be quoted until `sim_e3.py` `E3_FAILURE_ANALYSIS.md` status flips to VERIFIED. — Integrity boundary maintained: I report the structural failure rather than a fabricated gain.*

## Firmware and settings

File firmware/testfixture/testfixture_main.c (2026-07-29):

/**
 * @file    testfixture_main.c
 * @brief   MykoVolt Test Fixture — main application
 *
 * ── System Overview ──
 *   MCU:      STM32L011F4 (Cortex-M0+, 16MHz, 16KB flash, 2KB RAM)
 *   Power:    USB (benchtop) or BQ25570 (pressling, in-soil)
 *   Storage:  MB85RC16 (2KB FRAM, I2C 0x50)
 *   Sensors:  INA219 (V/I/P, I2C 0x40), SHT30 (T/RH, I2C 0x44)
 *   RTC:      PCF8523 (I2C 0x52, alarm wake)
 *   NFC:      ST25DV04K (I2C 0x53 + RF ISO 15693)
 *   Load:     4× MOSFET-switched resistors (PA0-PA3)
 *
 * ── Measurement Modes ──
 *   V_OC_TRACKING: V_OC every 60s, all loads off
 *   IV_SWEEP:      Full I/V sweep (R1→R2→R3→R4) every 60 min
 *   LOAD_LIFE:     Fixed load, V+I every 60s until cutoff
 *
 * ── Application States ──
 *   SLEEP ──> ACTIVE ──> SLEEP  (RTC alarm wake)
 *              └──> NFC_ACCESS   (when RF field detected)
 */

#include "testfixture_config.h"
#include "i2c_driver.h"
#include "ina219.h"
#include "sht30.h"
#include "st25dv04k.h"
#include "mb85rc16.h"
#include "pcf8523.h"
#include "bq25570.h"

#include <string.h>

/* Busy-wait calibration: assumes HSI 16MHz with -Os optimisation.
 * Each volatile loop iteration ≈ 8 cycles → ~0.5µs per iteration.
 * Adjust multipliers if clock or optimisation changes. */

/* ========================================================================
 *   Local state
 * ======================================================================== */

static app_state_t g_app_state = APP_STATE_SLEEP;
static uint32_t    g_sleep_cycles = 0;
static uint8_t     g_nfc_buffer[128];

static measurement_mode_t g_mode = DEFAULT_MODE;
static uint8_t  g_load_mask = LOAD_R1_MASK;  /* Default load for load-life mode */
static uint32_t g_last_sweep_cycle = 0;       /* Cycle count of last I/V sweep */

/* Ring buffer state */
static uint16_t g_fram_write_pos = 0;
static uint16_t g_fram_entry_count = 0;

/* ========================================================================
 *   Forward declarations
 * ======================================================================== */

static void system_clock_init(void);
static void gpio_init(void);
static void enter_sleep(void);
static void do_measurement(void);
static void handle_nfc_access(void);
static void log_error(const char *msg);

static void load_bank_set(uint8_t mask);
static void load_bank_off(void);

static bool fram_ringbuffer_init(void);
static bool fram_ringbuffer_write(uint32_t timestamp, uint16_t voc_mv,
                                   int16_t load_current_ma, uint8_t load_idx,
                                   int8_t temp_c, uint8_t rh_pct,
                                   uint8_t status);
static uint8_t entry_checksum(const uint8_t *data, uint8_t len);

/* ========================================================================
 *   main
 * ======================================================================== */

int main(void) {
    system_clock_init();
    gpio_init();
    i2c_init();

    if (!ina219_init()) {
        log_error("INA219 init failed");
    }
    if (!sht30_init()) {
        log_error("SHT30 init failed");
    }
    if (!st25dv04k_init()) {
        log_error("ST25DV04K init failed");
    }
    if (!pcf8523_init()) {
        log_error("PCF8523 init failed");
    }
    if (!mb85rc16_init()) {
        log_error("MB85RC16 init failed");
    }

    fram_ringbuffer_init();

    while (1) {
        switch (g_app_state) {
        case APP_STATE_SLEEP:
            if (st25dv04k_rf_present()) {
                g_app_state = APP_STATE_NFC_ACCESS;
                break;
            }
            if (bq25570_vbat_ok()) {
                enter_sleep();
                g_sleep_cycles++;
                g_app_state = APP_STATE_ACTIVE;
            } else {
                for (volatile int i = 0; i < 500000; i++);
                g_app_state = APP_STATE_SLEEP;
            }
            break;

        case APP_STATE_ACTIVE:
            do_measurement();
            g_app_state = APP_STATE_SLEEP;
            break;

        case APP_STATE_NFC_ACCESS:
            handle_nfc_access();
            g_app_state = APP_STATE_SLEEP;
            break;

        case APP_STATE_ERROR:
            for (volatile int i = 0; i < 1000000; i++);
            g_app_state = APP_STATE_SLEEP;
            break;
        }
    }
}

/* ========================================================================
 *   System clock: HSI 16MHz
 * ======================================================================== */

static void system_clock_init(void) {
    RCC->CR |= RCC_CR_HSION;
    while (!(RCC->CR & RCC_CR_HSIRDY));

    RCC->CFGR = (RCC->CFGR & ~RCC_CFGR_SW) | RCC_CFGR_SW_HSI;
    while ((RCC->CFGR & RCC_CFGR_SWS) != RCC_CFGR_SWS_HSI);

    RCC->CFGR &= ~(RCC_CFGR_HPRE | RCC_CFGR_PPRE1 | RCC_CFGR_PPRE2);
}

/* ========================================================================
 *   GPIO
 * ======================================================================== */

static void gpio_init(void) {
    RCC->IOPENR |= RCC_IOPENR_GPIOAEN | RCC_IOPENR_GPIOBEN | RCC_IOPENR_GPIOCEN;

    /* LED2 (PA7) — push-pull output */
    GPIOA->MODER &= ~GPIO_MODER_MODE7_Msk;
    GPIOA->MODER |= GPIO_MODER_MODE7_0;
    GPIOA->OTYPER &= ~GPIO_OTYPER_OT_7;
    GPIOA->PUPDR &= ~GPIO_PUPDR_PUPD7_Msk;

    /* LOAD_SW_GATE (PA4) — push-pull output, initially on */
    GPIOA->MODER &= ~GPIO_MODER_MODE4_Msk;
    GPIOA->MODER |= GPIO_MODER_MODE4_0;
    GPIOA->OTYPER &= ~GPIO_OTYPER_OT_4;
    GPIOA->PUPDR &= ~GPIO_PUPDR_PUPD4_Msk;
    GPIOA->BSRR = GPIO_BSRR_BS_4;

    /* Load bank MOSFET gates: PA0 (R1), PA1 (R2), PA2 (R3), PA3 (R4) */
    /* All push-pull outputs, initially OFF (loads disconnected) */
    for (int pin = 0; pin <= 3; pin++) {
        GPIOA->MODER &= ~(3U << (pin * 2));
        GPIOA->MODER |= (1U << (pin * 2));    /* Output mode */
        GPIOA->OTYPER &= ~(1U << pin);         /* Push-pull */
        GPIOA->PUPDR &= ~(3U << (pin * 2));    /* No pull */
        GPIOA->BSRR = (1U << (pin + 16));      /* Reset (OFF) */
    }

    /* NFC IRQ (PA5) — input with pull-up */
    GPIOA->MODER &= ~GPIO_MODER_MODE5_Msk;
    GPIOA->PUPDR &= ~GPIO_PUPDR_PUPD5_Msk;
    GPIOA->PUPDR |= GPIO_PUPDR_PUPD5_0;

    /* VBAT_OK (PB1) — input */
    GPIOB->MODER &= ~GPIO_MODER_MODE1_Msk;

    /* RTC_INT (PA6) — input with falling-edge IRQ */
    GPIOA->MODER &= ~GPIO_MODER_MODE6_Msk;
    GPIOA->PUPDR &= ~GPIO_PUPDR_PUPD6_Msk;
    GPIOA->PUPDR |= GPIO_PUPDR_PUPD6_0;

    SYSCFG->EXTICR[1] &= ~SYSCFG_EXTICR2_EXTI6;
    SYSCFG->EXTICR[1] |= SYSCFG_EXTICR2_EXTI6_PA;
    EXTI->IMR |= EXTI_IMR_IM6;
    EXTI->FTSR |= EXTI_FTSR_TR6;

    NVIC_EnableIRQ(EXTI4_15_IRQn);
}

/* ========================================================================
 *   Load bank control
 * ======================================================================== */

static void load_bank_set(uint8_t mask) {
    /* PA0=R1, PA1=R2, PA2=R3, PA3=R4 */
    if (mask & LOAD_R1_MASK) GPIOA->BSRR = GPIO_BSRR_BS_0;
    else                     GPIOA->BSRR = GPIO_BSRR_BR_0;
    if (mask & LOAD_R2_MASK) GPIOA->BSRR = GPIO_BSRR_BS_1;
    else                     GPIOA->BSRR = GPIO_BSRR_BR_1;
    if (mask & LOAD_R3_MASK) GPIOA->BSRR = GPIO_BSRR_BS_2;
    else                     GPIOA->BSRR = GPIO_BSRR_BR_2;
    if (mask & LOAD_R4_MASK) GPIOA->BSRR = GPIO_BSRR_BS_3;
    else                     GPIOA->BSRR = GPIO_BSRR_BR_3;
}

static void load_bank_off(void) {
    GPIOA->BSRR = GPIO_BSRR_BR_0 | GPIO_BSRR_BR_1 | GPIO_BSRR_BR_2 | GPIO_BSRR_BR_3;
}

/* ========================================================================
 *   Sleep mode (STOP with RTC alarm wake)
 * ======================================================================== */

static void enter_sleep(void) {
    GPIOA->BSRR = GPIO_BSRR_BR_7;

    pcf8523_clear_alarm();

    pcf8523_datetime_t dt;
    if (pcf8523_read_datetime(&dt)) {
        pcf8523_set_minute_alarm((dt.minutes + 1) % 60);
    }

    PWR->CR |= PWR_CR_LPSDSR;
    PWR->CR |= PWR_CR_ULP;
    SCB->SCR |= SCB_SCR_SLEEPDEEP_Msk;
    __WFI();

    GPIOA->BSRR = GPIO_BSRR_BS_7;
}

/* ========================================================================
 *   Measurement cycle
 * ======================================================================== */

static void do_measurement(void) {
    int8_t  temp_c = 0;
    uint8_t rh_pct = 0;

    uint8_t status = 0;
    if (!sht30_read(&temp_c, &rh_pct)) {
        status |= 0x04;  /* SHT30 sensor failure */
    }

    if (bq25570_vbat_ok()) status |= 0x01;
    if (st25dv04k_rf_present()) status |= 0x02;

    switch (g_mode) {
    case MODE_VOC_TRACKING: {
        /* V_OC measurement: all loads off, read voltage */
        load_bank_off();
        uint16_t voc = ina219_read_voltage_mv();
        fram_ringbuffer_write(g_sleep_cycles, voc, 0, 0,
                              temp_c, rh_pct, status);
        break;
    }

    case MODE_IV_SWEEP: {
        /* Full I/V sweep every MEASURE_INTERVAL_SWEEP / RTC_interval cycles
         * Otherwise just V_OC tracking */
        uint32_t sweep_period = MEASURE_INTERVAL_SWEEP / 60;  /* cycles between sweeps (60s/cycle) */
        if (sweep_period == 0) sweep_period = 1;

        if ((g_sleep_cycles - g_last_sweep_cycle) >= sweep_period) {
            g_last_sweep_cycle = g_sleep_cycles;

            /* Sweep each load: R1, R2, R3, R4 */
            const uint8_t loads[] = {LOAD_R1_MASK, LOAD_R2_MASK,
                                      LOAD_R3_MASK, LOAD_R4_MASK};
            for (int i = 0; i < 4; i++) {
                load_bank_set(loads[i]);
                /* Dwell SWEEP_DWELL_MS (approximate busy-wait) */
                for (volatile int j = 0; j < SWEEP_DWELL_MS * 2000; j++);
                uint16_t v = ina219_read_voltage_mv();
                int16_t  i_ma = ina219_read_current_ma();
                fram_ringbuffer_write(g_sleep_cycles, v, i_ma,
                                      (uint8_t)(i + 1),
                                      temp_c, rh_pct, status);
            }
            load_bank_off();
        } else {
            /* Between sweeps: V_OC tracking */
            load_bank_off();
            uint16_t voc = ina219_read_voltage_mv();
            fram_ringbuffer_write(g_sleep_cycles, voc, 0, 0,
                                  temp_c, rh_pct, status);
        }
        break;
    }

    case MODE_LOAD_LIFE: {
        /* Continuous fixed load, measure V+I every cycle */
        load_bank_set(g_load_mask);
        uint16_t v = ina219_read_voltage_mv();
        int16_t  i_ma = ina219_read_current_ma();

        /* Determine load index from mask */
        uint8_t load_idx = 0;
        if (g_load_mask == LOAD_R1_MASK) load_idx = 1;
        else if (g_load_mask == LOAD_R2_MASK) load_idx = 2;
        else if (g_load_mask == LOAD_R3_MASK) load_idx = 3;
        else if (g_load_mask == LOAD_R4_MASK) load_idx = 4;

        fram_ringbuffer_write(g_sleep_cycles, v, i_ma, load_idx,
                              temp_c, rh_pct, status);
        break;
    }
    }
}

/* ========================================================================
 *   NFC access
 * ======================================================================== */

static void handle_nfc_access(void) {
    uint16_t msg_len = st25dv04k_mailbox_read_len();
    if (msg_len > 0 && msg_len <= sizeof(g_nfc_buffer)) {
        st25dv04k_mailbox_read(g_nfc_buffer, &msg_len);

        uint8_t cmd = g_nfc_buffer[0];
        uint8_t reply[16];
        memset(reply, 0, sizeof(reply));

        switch (cmd) {
        case 'M': /* Set mode */
            if (msg_len >= 2) {
                uint8_t new_mode = g_nfc_buffer[1];
                if (new_mode <= MODE_LOAD_LIFE) {
                    g_mode = (measurement_mode_t)new_mode;
                }
                if (msg_len >= 3) {
                    uint8_t new_mask = g_nfc_buffer[2];
                    if ((new_mask & ~0x0F) == 0 && new_mask != 0) {
                        g_load_mask = new_mask;
                    }
                }
            }
            reply[0] = 'M';
            reply[1] = (uint8_t)g_mode;
            reply[2] = g_load_mask;
            st25dv04k_mailbox_write(reply, 3);
            break;

        case 'S': /* Start sweep now */
            g_last_sweep_cycle = 0;  /* Force sweep on next active cycle */
            reply[0] = 'S';
            reply[1] = 0;  /* OK */
            st25dv04k_mailbox_write(reply, 2);
            break;

        case 'R': /* Read status */
            reply[0] = 'R';
            reply[1] = (uint8_t)g_mode;
            reply[2] = g_load_mask;
            if (g_mode == MODE_LOAD_LIFE) {
                /* Read under load, don't disturb the test */
                uint16_t v = ina219_read_voltage_mv();
                reply[3] = (uint8_t)(v >> 8);
                reply[4] = (uint8_t)(v);
                int16_t cur = ina219_read_current_ma();
                reply[5] = (uint8_t)((uint16_t)cur >> 8);
                reply[6] = (uint8_t)((uint16_t)cur);
            } else {
                load_bank_off();
                uint16_t voc = ina219_read_voltage_mv();
                reply[3] = (uint8_t)(voc >> 8);
                reply[4] = (uint8_t)(voc);
                int16_t cur = ina219_read_current_ma();
                reply[5] = (uint8_t)((uint16_t)cur >> 8);
                reply[6] = (uint8_t)((uint16_t)cur);
            }
            /* Entry count */
            reply[7] = (uint8_t)(g_fram_entry_count >> 8);
            reply[8] = (uint8_t)(g_fram_entry_count);
            st25dv04k_mailbox_write(reply, 9);
            break;

        default:
            reply[0] = '?';
            st25dv04k_mailbox_write(reply, 1);
            break;
        }
    }

    volatile uint32_t timeout = 1000000;
    while (st25dv04k_rf_present() && timeout--) {}
}

/* ========================================================================
 *   FRAM ring buffer (v2 — 13-byte entries)
 * ======================================================================== */

static bool fram_ringbuffer_init(void) {
    uint8_t magic_hi = mb85rc16_read_byte(0x00);
    uint8_t magic_lo = mb85rc16_read_byte(0x01);

    if (magic_hi == 0xFF && magic_lo == 0xFF) {
        /* First boot — initialise header */
        uint8_t hdr[5];
        hdr[0] = (FRAM_MAGIC >> 8) & 0xFF;
        hdr[1] = FRAM_MAGIC & 0xFF;
        hdr[2] = FRAM_VERSION;
        hdr[3] = 0;  /* Write pos high */
        hdr[4] = 0;  /* Write pos low */
        if (!mb85rc16_write(0x00, hdr, 5)) {
            return false;
        }
        g_fram_write_pos = 0;
        g_fram_entry_count = 0;
        return true;
    }

    /* Existing data — resume write pointer */
    uint8_t pos_buf[2];
    if (mb85rc16_read(0x03, pos_buf, 2) == 2) {
        g_fram_write_pos = ((uint16_t)pos_buf[0] << 8) | pos_buf[1];
    } else {
        g_fram_write_pos = 0;
    }

    uint8_t ver = mb85rc16_read_byte(0x02);
    if (ver != FRAM_VERSION) {
        /* Version mismatch — reinitialise */
        g_fram_write_pos = 0;
        g_fram_entry_count = 0;
        return false;
    }

    g_fram_entry_count = g_fram_write_pos / FRAM_ENTRY_SIZE;
    if (g_fram_entry_count >= FRAM_MAX_ENTRIES) {
        g_fram_entry_count = FRAM_MAX_ENTRIES;
    }
    return true;
}

static bool fram_ringbuffer_write(uint32_t timestamp, uint16_t voc_mv,
                                   int16_t load_current_ma, uint8_t load_idx,
                                   int8_t temp_c, uint8_t rh_pct,
                                   uint8_t status) {
    uint8_t entry[FRAM_ENTRY_SIZE];
    uint16_t addr;

    entry[0] = (uint8_t)(timestamp >> 24);
    entry[1] = (uint8_t)(timestamp >> 16);
    entry[2] = (uint8_t)(timestamp >> 8);
    entry[3] = (uint8_t)(timestamp);
    entry[4] = (uint8_t)(voc_mv >> 8);
    entry[5] = (uint8_t)(voc_mv);
    entry[6] = (uint8_t)((uint16_t)load_current_ma >> 8);
    entry[7] = (uint8_t)((uint16_t)load_current_ma);
    entry[8] = load_idx;
    entry[9] = (uint8_t)temp_c;
    entry[10] = rh_pct;
    entry[11] = status;
    entry[12] = entry_checksum(entry, FRAM_ENTRY_SIZE - 1);

    addr = FRAM_DATA_START + g_fram_write_pos;

    if (g_fram_write_pos >= (uint16_t)(FRAM_MAX_ENTRIES * FRAM_ENTRY_SIZE)) {
        g_fram_write_pos = 0;
        addr = FRAM_DATA_START;
    }

    if (!mb85rc16_write(addr, entry, FRAM_ENTRY_SIZE)) {
        return false;
    }

    g_fram_write_pos += FRAM_ENTRY_SIZE;
    if (g_fram_entry_count < FRAM_MAX_ENTRIES) g_fram_entry_count++;

    uint8_t pos_buf[2];
    pos_buf[0] = (uint8_t)(g_fram_write_pos >> 8);
    pos_buf[1] = (uint8_t)(g_fram_write_pos);
    return mb85rc16_write(0x03, pos_buf, 2);
}

static uint8_t entry_checksum(const uint8_t *data, uint8_t len) {
    uint8_t crc = 0;
    for (uint8_t i = 0; i < len; i++) {
        crc ^= data[i];
    }
    return crc;
}

/* ========================================================================
 *   Error logging (LED blink pattern)
 * ======================================================================== */

static void log_error(const char *msg) {
    (void)msg;
    for (int i = 0; i < 3; i++) {
        GPIOA->BSRR = GPIO_BSRR_BS_7;
        for (volatile int j = 0; j < 200000; j++);
        GPIOA->BSRR = GPIO_BSRR_BR_7;
        for (volatile int j = 0; j < 200000; j++);
    }
    g_app_state = APP_STATE_ERROR;
}

/* ========================================================================
 *   EXTI4_15_IRQHandler (RTC alarm on PA6 / EXTI6)
 * ======================================================================== */

void EXTI4_15_IRQHandler(void) {
    if (EXTI->PR & EXTI_PR_PR6) {
        EXTI->PR = EXTI_PR_PR6;
    }
}

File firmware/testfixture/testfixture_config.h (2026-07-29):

/**
 * @file    testfixture_config.h
 * @brief   MykoVolt Test Fixture — board definitions, pin mappings, I2C addresses
 *
 * MCU: STM32L011F4Px (UFQFPN-20)
 * Purpose: Characterize pressling (fungal MFC) power output
 *
 * This header replaces mykovolt.h for the test fixture build.
 * It defines different pin mappings (load bank MOSFETs instead of
 * FDC1004/USART) and additional I2C addresses (INA219, SHT30).
 */

#ifndef __TESTFIXTURE_CONFIG_H
#define __TESTFIXTURE_CONFIG_H

#ifdef __cplusplus
extern "C" {
#endif

#include <stdint.h>
#include <stdbool.h>
#include "stm32l011xx.h"
#include "mykovolt.h"

/* ========================================================================
 *   Pin Mappings (STM32L011F4Px TSSOP-20)
 * ======================================================================== */

/* Load bank MOSFET gates (repurposed from dev kit) */
#define PIN_LOAD_R1          GPIO_PIN_0    /* PA0 — 10 kΩ load (trickle) */
#define PORT_LOAD_R1         GPIOA
#define PIN_LOAD_R2          GPIO_PIN_1    /* PA1 — 100 Ω load (low) */
#define PORT_LOAD_R2         GPIOA
#define PIN_LOAD_R3          GPIO_PIN_2    /* PA2 — 10 Ω load (medium) */
#define PORT_LOAD_R3         GPIOA
#define PIN_LOAD_R4          GPIO_PIN_3    /* PA3 — 1 Ω load (heavy) */
#define PORT_LOAD_R4         GPIOA

/* Power management — BQ25570 */
#define PIN_VBAT_OK          GPIO_PIN_1    /* PB1 — VBAT_OK indicator */
#define PORT_VBAT_OK         GPIOB
#define PIN_LOAD_SW_GATE     GPIO_PIN_4    /* PA4 — Q1 gate control */

/* NFC — ST25DV04K */
#define PIN_NFC_IRQ          GPIO_PIN_5    /* PA5 — NFC interrupt */

/* RTC — PCF8523 */
#define PIN_RTC_INT          GPIO_PIN_6    /* PA6 — RTC interrupt */

/* LED */
#define PIN_LED_CTRL         GPIO_PIN_7    /* PA7 — yellow LED */

/* I2C1 */
#define PIN_I2C1_SCL         GPIO_PIN_9    /* PA9 */
#define PIN_I2C1_SDA         GPIO_PIN_10   /* PA10 */

/* ========================================================================
 *   I2C Address Map
 * ======================================================================== */

#define I2C_ADDR_INA219      0x40  /* Current/voltage/power sensor */
#define I2C_ADDR_SHT30       0x44  /* Temperature + humidity */
#define I2C_ADDR_FRAM        0x50  /* MB85RC16 */
#define I2C_ADDR_PCF8523     0x52  /* RTC */
#define I2C_ADDR_ST25DV04K   0x53  /* NFC tag */

/* ========================================================================
 *   Load Bank
 * ======================================================================== */

#define LOAD_R1_MASK         0x01  /* 10 kΩ — trickle (40 µA at 0.4V) */
#define LOAD_R2_MASK         0x02  /* 100 Ω — low (4 mA at 0.4V) */
#define LOAD_R3_MASK         0x04  /* 10 Ω — medium (40 mA at 0.4V) */
#define LOAD_R4_MASK         0x08  /* 1 Ω — heavy (400 mA at 0.4V) */

/* ========================================================================
 *   FRAM Ring Buffer (v2 — Test Fixture Format)
 * ======================================================================== */

#define FRAM_MAGIC           0x4D56  /* "MV" — same as dev kit */
#define FRAM_VERSION         0x02    /* v2 = test fixture */
#define FRAM_HEADER_SIZE     256
#define FRAM_ENTRY_SIZE      13      /* v2 entry: 12 data + 1 CRC */
#define FRAM_DATA_START      0x100
#define FRAM_MAX_ENTRIES     ((2048 - FRAM_HEADER_SIZE) / FRAM_ENTRY_SIZE)  /* 137 */

/* ========================================================================
 *   Measurement Modes
 * ======================================================================== */

typedef enum {
    MODE_VOC_TRACKING = 0,  /* V_OC every 60s, loads off */
    MODE_IV_SWEEP      = 1,  /* Full I/V sweep every 60 min */
    MODE_LOAD_LIFE     = 2   /* Continuous fixed load, V+I every 60s */
} measurement_mode_t;

/* Default measurement interval (seconds) */
#define MEASURE_INTERVAL_VOC     60    /* V_OC tracking interval */
#define MEASURE_INTERVAL_SWEEP   3600  /* I/V sweep interval */
#define MEASURE_INTERVAL_LIFE    60    /* Load life test interval */

/* I/V sweep: dwell time per load step (ms) */
#define SWEEP_DWELL_MS           5000  /* 5 seconds per load */

/* Default mode for NFC-configured mode */
#define DEFAULT_MODE             MODE_VOC_TRACKING

/* ========================================================================
 *   System Clock
 * ======================================================================== */

#define LSE_FREQ_HZ          32768
#define HSI_FREQ_HZ          16000000
#define SYSCLK_FREQ_HZ       16000000

#ifdef __cplusplus
}
#endif

#endif /* __TESTFIXTURE_CONFIG_H */

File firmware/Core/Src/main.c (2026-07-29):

/**
 * @file    main.c
 * @brief   MykoVolt DevKit — main application
 *
 * ── System Overview ──
 *   MCU:      STM32L011F4 (Cortex-M0+, 16MHz, 16KB flash, 2KB RAM)
 *   Power:    BQ25570 (boost charger + LDO from pressling MFC)
 *   Storage:  MB85RC16 (16Kbit FRAM, I2C 0x50, 2KB)
 *   Sensor:   FDC1004 (4ch capacitance, I2C 0x51)
 *   RTC:      PCF8523 (I2C 0x52, alarm every 15 min)
 *   NFC:      ST25DV04K (I2C 0x53 + RF ISO 15693)
 *
 * ── Application States ──
 *   SLEEP ──> ACTIVE ──> SLEEP  (RTC alarm wakes every 15 min)
 *              └──> NFC_ACCESS   (when RF field detected)
 */

#include "mykovolt.h"
#include "i2c_driver.h"
#include "fdc1004.h"
#include "st25dv04k.h"
#include "mb85rc16.h"
#include "pcf8523.h"
#include "bq25570.h"

#include <string.h>

/* ========================================================================
 *   FRAM Ring Buffer Layout (MB85RC16 = 2KB)
 * ========================================================================
 *
 *   Address   | Content              | Size
 *   ----------+----------------------+-------
 *   0x000     | Magic (0x4D56 = "MV")| 2
 *   0x002     | Version              | 1
 *   0x003     | Write pointer        | 2  (byte offset from 0x100)
 *   0x005     | Reserved             | 251
 *   0x100     | Entry 0              | 12
 *   0x10C     | Entry 1              | 12
 *   ...       | ...                  | ...
 *   0x7FF     | Last entry byte      | -
 *
 *   Entry format (12 bytes):
 *     [0] timestamp  uint32  RTC counter or Unix time
 *     [4] cap_raw    uint16  FDC1004 raw value
 *     [6] v_batt     uint16  Battery voltage in mV
 *     [8] v_sense    uint16  Sensor voltage in mV
 *     [10] status    uint8   Flags (bit 0: VBAT_OK, bit 1: NFC present)
 *     [11] crc       uint8   XOR of bytes 0-10
 *
 *   Max entries: (2048 - 256) / 12 = 149
 */

#define FRAM_MAGIC          0x4D56  /* "MV" */
#define FRAM_VERSION        0x01
#define FRAM_HEADER_SIZE    256
#define FRAM_ENTRY_SIZE     12
#define FRAM_DATA_START     0x100
#define FRAM_MAX_ENTRIES    ((2048 - FRAM_HEADER_SIZE) / FRAM_ENTRY_SIZE)
#define FRAM_MEASURE_INTERVAL 10  /* Every 10th cycle = ~15 min at 90s cycle */

/* ========================================================================
 *   Local state
 * ======================================================================== */

static app_state_t g_app_state = APP_STATE_SLEEP;
static uint32_t    g_sleep_cycles = 0;
static int32_t     g_last_moisture_raw = 0;
static float       g_last_moisture_pf = 0.0f;
static uint8_t     g_nfc_buffer[128];

/* Ring buffer state */
static uint16_t    g_fram_write_pos = 0;   /* Byte offset from 0x100 */
static uint16_t    g_fram_entry_count = 0;

/* ========================================================================
 *   Forward declarations
 * ======================================================================== */

static void system_clock_init(void);
static void gpio_init(void);
static void enter_sleep(void);
static void do_measurement(void);
static void handle_nfc_access(void);
static void log_error(const char *msg);

static bool fram_ringbuffer_init(void);
static bool fram_ringbuffer_write(uint32_t timestamp, uint16_t cap_raw,
                                   uint16_t v_batt, uint16_t v_sense,
                                   uint8_t status);
static uint8_t entry_crc(const uint8_t *data);

/* ========================================================================
 *   main
 * ======================================================================== */

int main(void) {
    system_clock_init();
    gpio_init();
    i2c_init();

    bq25570_init();

    if (!fdc1004_init()) {
        log_error("FDC1004 init failed");
    }
    if (!st25dv04k_init()) {
        log_error("ST25DV04K init failed");
    }
    if (!pcf8523_init()) {
        log_error("PCF8523 init failed");
    }
    if (!mb85rc16_init()) {
        log_error("MB85RC16 init failed");
    }

    (void)fdc1004_read_device_id();
    (void)st25dv04k_read_ic_ref();

    /* Init FRAM ring buffer (preserves existing data on reset) */
    fram_ringbuffer_init();

    while (1) {
        switch (g_app_state) {
        case APP_STATE_SLEEP:
            if (st25dv04k_rf_present()) {
                g_app_state = APP_STATE_NFC_ACCESS;
                break;
            }
            if (bq25570_vbat_ok()) {
                enter_sleep();
                g_sleep_cycles++;
                g_app_state = APP_STATE_ACTIVE;
            } else {
                /* VBAT too low — stay awake, blink, retry */
                for (volatile int i = 0; i < 500000; i++);
                g_app_state = APP_STATE_SLEEP;
            }
            break;

        case APP_STATE_ACTIVE:
            do_measurement();
            g_app_state = APP_STATE_SLEEP;
            break;

        case APP_STATE_NFC_ACCESS:
            handle_nfc_access();
            g_app_state = APP_STATE_SLEEP;
            break;

        case APP_STATE_ERROR:
            for (volatile int i = 0; i < 1000000; i++);
            g_app_state = APP_STATE_SLEEP;
            break;
        }
    }
}

/* ========================================================================
 *   System clock: HSI 16MHz
 * ======================================================================== */

static void system_clock_init(void) {
    RCC->CR |= RCC_CR_HSION;
    while (!(RCC->CR & RCC_CR_HSIRDY));

    RCC->CFGR = (RCC->CFGR & ~RCC_CFGR_SW) | RCC_CFGR_SW_HSI;
    while ((RCC->CFGR & RCC_CFGR_SWS) != RCC_CFGR_SWS_HSI);

    RCC->CFGR &= ~(RCC_CFGR_HPRE | RCC_CFGR_PPRE1 | RCC_CFGR_PPRE2);

    RCC->CSR |= RCC_CSR_LSEON;
}

/* ========================================================================
 *   GPIO
 * ======================================================================== */
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

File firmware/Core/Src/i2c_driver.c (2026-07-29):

/**
 * @file    i2c_driver.c
 * @brief   I2C master driver for STM32L011 (bare-metal register access)
 *
 * Uses I2C1 peripheral on PA9 (SCL) and PA10 (SDA).
 * Standard mode 100kHz, 7-bit addressing.
 *
 * Reference: RM0385 (STM32L0x1 Reference Manual), Section 25
 */

#include "i2c_driver.h"
#include "mykovolt.h"

/* Register access */
#if !defined(GPIOA)
#error "This driver targets STM32L0 — check your MCU header"
#endif

/* ── Timing register values for 100kHz (HSI 16MHz) ── */
/* Computed with STM32CubeMX I2C Timing Calculator */
#define I2C_TIMINGR_100KHZ  0x00303D2B  /* PRESC=0, SCLDEL=3, SDADEL=1, SCLH=61, SCLL=107 */

/* ── State ── */
static volatile bool    i2c_busy = false;
static volatile uint32_t i2c_errors = 0;

/* ========================================================================
 *   Initialisation
 * ======================================================================== */

void i2c_init(void) {
    /* Enable I2C1 clock */
    RCC->APB1ENR |= RCC_APB1ENR_I2C1EN;

    /* Reset I2C1 */
    RCC->APB1RSTR |= RCC_APB1RSTR_I2C1RST;
    RCC->APB1RSTR &= ~RCC_APB1RSTR_I2C1RST;

    /* Configure GPIO: PA9=SCL(AF1), PA10=SDA(AF1), open-drain */
    GPIOA->MODER = (GPIOA->MODER & ~(GPIO_MODER_MODE9 | GPIO_MODER_MODE10)) | GPIO_MODER_MODE9_1 | GPIO_MODER_MODE10_1;  /* AF = 0b10 */
    GPIOA->OTYPER |= GPIO_OTYPER_OT_9 | GPIO_OTYPER_OT_10; /* Open-drain */
    GPIOA->PUPDR &= ~(GPIO_PUPDR_PUPD9 | GPIO_PUPDR_PUPD10);
    GPIOA->PUPDR |= GPIO_PUPDR_PUPD9_0 | GPIO_PUPDR_PUPD10_0; /* Pull-up */
    GPIOA->AFR[1] &= ~(0xF << 4) & ~(0xF << 8);  /* AF1 for both */
    GPIOA->AFR[1] |= (1 << 4) | (1 << 8);         /* AF1 = I2C1 */

    /* Disable I2C before configuring */
    I2C1->CR1 &= ~I2C_CR1_PE;

    /* Set timing for 100kHz standard mode */
    I2C1->TIMINGR = I2C_TIMINGR_100KHZ;

    /* Enable I2C */
    I2C1->CR1 |= I2C_CR1_PE;

    i2c_busy = false;
    i2c_errors = 0;
}

void i2c_enable(void) {
    I2C1->CR1 |= I2C_CR1_PE;
}

void i2c_disable(void) {
    I2C1->CR1 &= ~I2C_CR1_PE;
}

bool i2c_ready(void) {
    return !i2c_busy && (I2C1->ISR & I2C_ISR_TXE);
}

uint32_t i2c_error_count(void) {
    return i2c_errors;
}

/* ========================================================================
 *   Wait for flag with timeout
 * ======================================================================== */

/**
 * Wait for an I2C ISR flag with a timeout.
 * @return true if flag set, false on timeout
 */
static bool wait_for_flag(uint32_t flag, bool set) {
    volatile uint32_t timeout = 50000;
    while (timeout--) {
        if (((I2C1->ISR & flag) != 0) == set) {
            return true;
        }
    }
    i2c_errors++;
    return false;
}

/* ========================================================================
 *   Master Transmit
 * ======================================================================== */

bool i2c_write_reg(uint8_t addr, uint8_t reg, const uint8_t *data, uint16_t len) {
    if (i2c_busy) return false;
    i2c_busy = true;

    /* Wait for bus ready */
    if (!wait_for_flag(I2C_ISR_BUSY, false)) {
        I2C1->ICR = 0xFFFFFFFF;  /* Clear all flags */
        i2c_busy = false;
        return false;
    }

    /* Start: send slave address + W */
    I2C1->CR2 = (addr << 1) | I2C_CR2_START | ((uint32_t)(len + 1)) | I2C_CR2_AUTOEND;

    if (!wait_for_flag(I2C_ISR_TXIS, true)) {
        i2c_busy = false;
        return false;
    }

    /* Send register address */
    I2C1->TXDR = reg;

    /* Send data bytes */
    for (uint16_t i = 0; i < len; i++) {
        if (!wait_for_flag(I2C_ISR_TXIS, true)) {
            i2c_busy = false;
            return false;
        }
        I2C1->TXDR = data[i];
    }

    /* Wait for STOP (autoend) */
    if (!wait_for_flag(I2C_ISR_STOPF, true)) {
        i2c_busy = false;
        return false;
    }

    I2C1->ICR = I2C_ICR_STOPCF;
    i2c_busy = false;
    return true;
}
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

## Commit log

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2026-06-24 Dritte Prüfrunde: 12 Schwachstellen adressiert
    - Use Case auf Saison/Ad-hoc korrigiert (kein Dauerbetrieb)
    - Milchmädchenrechnung entfernt, Biochar statt Carbon Black, pflanzliches Wachs
    - Fungizid-freie Zielgruppe, Solar-Substitute, IP geschärft
    - Bodenmikrobiom-Risiko, Kill-Kriterium J1, Team-Disziplinen
    - Sektion 3 von 2700→1785 Z. gestrafft
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2026-07-05 Fix teaser graphics with realistic power/cost numbers
    Updated power baseline from 520 µW to 12.5 µW/cm², corrected LoRa→NFC/Data, refreshed stat cards. Regenerated PNG at 300 DPI.
    Ultraworked with Sisyphus (https://github.com/code-yeongyu/oh-my-openagent)
2026-07-05 Fix MVP design diagram and HTML with realistic TRL-2 power/cost
    mvp_design.svg: Updated energy budget to 50 µW target/12.5 µW/cm² baseline, fixed µJ→mJ units, honest deficit messaging. diagrams.html: Fixed 520 µW → TRL-2 power in sequence diagram, corrected Gantt/business model/quadrant pricing.
    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
2026-07-07 Redesign teaser SVG with spacious legible layout
    Completely redesigned teaser: title 80px (was 62px), subtitle 34px (was 22px), stat numbers 30px (was 20px), removed cramped feature cards. Sensor illustration simplified. Retina PNG at 2400x1260.
    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
2026-07-07 Fix stale numbers and add archive warnings to archive docs
    archive/README.md: TRL 3-4→2-3, qualified simulation targets with 'Simulationsziel', €0.05→€0.15. archive/product_analysis.md: 260µW→25µW baseline with optimization target, added archive header. archive/MykoVolt_PoC.md: 3× LoRa→NFC.
    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
2026-07-07 Fix timeline and pricing in archive competition submission docs
    1Pager_EMC: shifted timeline (Lab J1-2→J1-3, Feld J2-3→J3-5, Markt J3-4→J5-7), DevKit €15-25→€24-35, qualified 261µW/cm² as 'Simulationsziel'. Geschaeftsmodell: DevKit 15-25€→24-35€, TRL 2→7 timeline 3-4J→5-7J. Both: added archive warning headers.
    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
2026-07-07 Fix pitch deck and EMC offer with TRL-2 realistic numbers
    Angebot_EMC: LoRa→NFC. Pitch_Deck.html: 8 fixes — EUR 0,05→EUR 0,15 (Pressling), 260µW→25µW TRL-2 baseline, qualified 261/86µW/cm² as simulationsziel, Pressling ab EUR 0,15, DevKit EUR 24-35, TRL 2→7 timeline 5-7J.
    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
2026-07-07 Fix stale numbers in README mermaid diagrams and simulation files
    README: 520µW→TRL-2 baseline (25µW) in sequence diagram, µJ→mJ in pie chart, xychart updated to 50µW target with corrected supply/demand values. simulation/README: qualified 260µW refs with 'Simulationsziel' and footnotes. e2e_soil_sensor.py: 260µW→TBD, €0.05→€0.15.
    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
2026-07-12 dual-path strategy: add air-chimney pressling & Mg-air battery designs
    Simulation uncovered O2 starvation as fundamental flaw in buried pressling
    (Monte Carlo: 8.7% viability at 10 cm depth). Two parallel paths forward:
    - Air-chimney pressling: porous PTFE breather tube restores O2 to cathode
    (docs/air_chimney_design.md)
    - Mg-air biodegradable battery: Mg anode + water reduction works O2-independently
    (docs/mg_air_battery.md)
    New simulation models:
    - pressling_viability.py — O2 diffusion, pressing damage, Monte Carlo
    - alternatives.py — 6-way comparison with weighted decision matrix
    - dual_path_analysis.py — seasonal/temperature/moisture sweep for both paths
    Phase 0 execution pl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
2026-07-20 Move loose docs/ files into business/, rename ip_ip_strategy → ip_strategy
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2026-07-26 fix: concise hardware docs with working product links
    - Rewrote sensor_board_design.md from 688→314 lines (concise, professional)
    - Embedded block diagram and layout SVGs inline
    - All 36 Mouser SKUs with working links
    - Clean tables, removed redundant explanations
    - Rewrote shopping_list.md from 402→178 lines
    - 38 verified Mouser links with correct SKUs
    - Added per-board cost at all scales
    - Section 11: ordering schedule with checklist
    - All SVG references verified in rendered markdown
2026-07-26 feat: KiCad project + NFC scanner app
    KiCad project (hardware/kicad/):
    - generate_kicad.py — Python generator for all KiCad files
    - mykovolt_devkit.kicad_pro — project with design rules, stack-up, net classes
    - mykovolt_devkit.kicad_sch — 50 components placed in functional groups
    - mykovolt_devkit.kicad_pcb — board outline (30x20mm) + layer stack (4-layer)
    - mykovolt_devkit.net — 34 nets, 126 connections, plain-text
    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
    [mykovolt_devkit.kicad_pcb, mykovolt_devkit.kicad_sch]
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2026-07-26 fix: complete KiCad 6 PCB generator rewrite with all critical fixes
    - MCU: STM32L011K4T (LQFP-32) -> STM32L011F4Px (TSSOP-20) correct symbol+pinout
    - BQ25570: Replaced TPS25570RGER power-switch placeholder with real Battery_Management:BQ25570
    - KiCad 6 compatibility: 8 symbol library fixes, custom embedded ST25DV04K and FDC1004 symbols
    - Full schematic generation: 54 components, 36 nets, 173 connections, zero duplicate pins
    - Netlist fixes: voltage divider, I2C pull-ups, decoupling caps, BQ25570 programming circuit
    - PCF8523T pinout corrected (VBAT->VSTOR, INT1->RTC_INT)
    - ST25DV04K correct SOIC-8 pin mapping (RF_M, RF_E1, VSSx2, SCL, SDA, IRQ, VDD)
    - BQ25570: EN->GND, VBAT_OV->GND, VRDIV+C2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
    [mykovolt_devkit.kicad_pcb, mykovolt_devkit.kicad_sch]
2026-07-26 fix: add simulation/ to test path so all 35 tests pass
    - tests/conftest.py: insert simulation/ directory into sys.path
    so module imports (degradation_model, ai_optimizer, etc.) resolve
    - Regenerated netlist (timestamp only change)
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2026-07-27 feat: fix all 57 PCB footprints, add copper zones, create firmware structure
    PCB improvements:
    - Fixed all 10 failing footprint names for KiCad 6 library compatibility
    (Package_SON, Inductor_SMD, Crystal, PinHeader, JST, THT cap, SOD)
    - All 57 footprints now load successfully with pcbnew (0 warnings)
    - Added GND copper pour on In1.Cu (inner layer 1)
    - Added 3.3V copper pour on In2.Cu (inner layer 2)
    - Pad net assignments from netlist (pads connected to correct nets)
    - PCB size: 212662 bytes, 57 footprints, 2 copper zones
    Firmware structure (STM32L011F4, bare-metal):
    - firmware/README.md — architecture, pin map, power tree, I2C bus map
    - Core/Inc/mykovolt.h — board definitions, pin map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
    [mykovolt_devkit.kicad_pcb, mykovolt_devkit.kicad_sch]
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2026-07-27 feat: critical path — NFC antenna, sensor electrodes, firmware startup
    PCB geometry (pcbnew tracks + zones):
    - NFC antenna coil: 4-turn rectangular spiral on F.Cu (18×12mm outer,
    0.3mm trace/space, ~2.9µH target for 13.56MHz with C20=47pF)
    - GND keepout on In1.Cu under antenna (prevents coupling with
    copper pour, IsKeepout=True)
    - Interdigital sensor electrodes on B.Cu: 10-finger comb pairs for
    CIN1 (measurement) and CIN2 (reference), SHLD1 guard ring
    - Routing from electrodes through J4 to FDC1004
    - 44 tracks total (17 F.Cu antenna + 27 B.Cu sensor)
    - 3 zones (GND pour, antenna keepout, 3.3V pour)
    Firmware startup (compilation-enabling):
    - startup/startup_stm32l011xx.s — reset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
    [mykovolt_devkit.kicad_pcb, mykovolt_devkit.kicad_sch]
2026-07-27 feat: route I2C bus, SWD, UART, control signals + power via stitching
    Routing (81 tracks + 12 vias across all layers):
    - I2C bus (SCL/SDA): horizontal trunk at Y=11mm with vertical drops
    to U1→U3→U4→U5→U6 (daisy chain), 0.3mm tracks, 18 unique nets
    - SWD debug (SWDIO/SWCLK/NRST): J1→U1 Manhattan routing
    - UART (TX/RX): U1→J1 direct connections
    - Control signals: NFC_IRQ, RTC_INT, SENSOR_RDY, VBAT_OK,
    LOAD_SW_GATE, MCU_LED_CTRL — L-shaped routes
    - V_SENSE: voltage divider routing U1→R9/R10
    - Power via stitching: 12 vias near ICs connecting 3.3V pads to
    In2.Cu pour and GND pads to In1.Cu pour (0.5mm via, 0.25mm drill)
    - Fixed IsKeepout flag: GND/3.3V zones explicitly set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
    [mykovolt_devkit.kicad_pcb, mykovolt_devkit.kicad_sch]
2026-07-27 feat: complete PCB routing (35/35 nets) + Gerber export + JLCPCB files
    Final routing coverage:
    - BQ25570 power path: LBOOST, LBUCK, VSTOR, V_PRESSLING (0.5mm tracks)
    - BQ25570 programming: OK_HYST, OK_PROG, VOC_SAMP, VOUT_SET, VRDIV, VREF_SAMP
    - LEDs: LED_PWR (Q1→R13→LED1), LED_STAT (R14→LED2)
    - Crystal: XTAL_IN, XTAL_OUT (U1→X1→C16/C17)
    - NFC_RF2: antenna feed to C20/U3 connection
    - I2C bus: fixed trunk routing (SCL/SDA both connected)
    - SWD: offset routing for SWDIO/SWCLK
    - UART: separated TX/RX routes
    - I2C pull-ups: R1→SCL, R2→SDA vertical drops
    Gerber export (12 files, via pcbnew PLOT_CONTROLLER):
    - F_Cu, In1_Cu, In2_Cu, B_Cu, F_SilkS, B_SilkS
    - F_Mask, B_Mask, F_Paste, B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
    [mykovolt_devkit-B_Cu.gbl, mykovolt_devkit-B_Mask.gbs, mykovolt_devkit-B_Paste.gbp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]
2026-07-27 feat: firmware drivers (FDC1004, ST25DV04K), PCB antenna fix, KiCad 9 migration
    Drivers:
    - Implement fdc1004.c: full driver for TI FDC1004 capacitance sensor
    - Implement st25dv04k.c: full driver for ST25DV04K NFC tag (mailbox, RF)
    - Extend i2c_driver: add i2c_write_reg16 / i2c_read_reg16 for 16-bit
    - Add CMSIS headers + STM32L0xx device headers for build
    - Fix STM32L011 MCU header include in mykovolt.h
    - Fix GPIO_OTYPER/BSRR/MODER macro names for actual CMSIS headers
    - Firmware builds with zero warnings (3.8KB flash, 920B RAM)
    PCB (KiCad):
    - Fix NFC antenna overhang: shift 37 antenna segments 2mm left
    (outer turn now at x=30, was x=32 — fits 30mm board edge)
    - Fix SENSOR label position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
    [mykovolt_devkit-B_Courtyard.gbr, mykovolt_devkit-B_Cu.gbl, mykovolt_devkit-B_Fab.gbr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]
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2026-07-27 professionalize: design rules, DRC tests, Gerber validator, project lib
    - Add design_rules.yaml: externalized board config (clearance, routing,
    placement, fabrication constraints) — single source of truth
    - Update generate_kicad.py: load YAML config, add CLI (--config, --variant,
    --skip-gerber, --skip-pcb), accept argv for test compatibility
    - Add tests/test_pcb_drc.py: 10 tests for DRC validation, Gerber file
    completeness, board outline, component/net counts
    - Add tools/validate_gerbers.py: Gerber validation against JLCPCB rules
    (layer completeness, syntax checks, file size validation)
    - Add hardware/kicad/mykovolt.kicad_sym: project-specific symbol library
    (FDC1004, ST25DV04K e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
    [mykovolt_devkit-B_Cu.gbl, mykovolt_devkit-B_Paste.gbp, mykovolt_devkit-B_SilkS.gbo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]
2026-07-27 professionalize: CI/CD, parametric sweep, test fixture, thermal+BOM checks
    CI/CD (GitHub Actions):
    - Add .github/workflows/pcb-ci.yml: 4-stage pipeline (lint → DRC →
    firmware build → full test suite)
    - Runs on push/PR to main for hardware/firmware/simulation paths
    - KiCad CLI installs from Debian backports on ubuntu-latest
    - Validates Gerbers, runs DRC, builds firmware, runs 95 tests
    - Self-hosted runner compatible
    Parametric Sweep:
    - tools/parametric_sweep.py: sweep antenna width, finger count, any
    design_rules.yaml parameter across values
    - Generates variant PCBs, runs DRC on each, produces comparison report
    - Default: sweeps antenna width (10/12/14mm) and finger count (8/10/12)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
    [mykovolt_devkit-B_Courtyard.gbr, mykovolt_devkit-B_Cu.gbl, mykovolt_devkit-B_Fab.gbr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]
2026-07-27 fix: restore fully routed PCB (228KB, 57fp, 120t) with antenna fix
    - Restore original routed PCB from commit 344a492
    - Apply antenna shift (2mm left), SENSOR text fix
    - Re-export all Gerbers from routed PCB (not skeleton)
    - All 13 system verification checks pass
    - Firmware: 3828B flash, 920B RAM (within STM32L011 limits)
    - 95 pytest pass
    - All tools validated: DRC, Gerbers, thermal, BOM, fixture, sweep
    [mykovolt_devkit-B_Courtyard.gbr, mykovolt_devkit-B_Cu.gbl, mykovolt_devkit-B_Fab.gbr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]
2026-07-27 redesign: reposition as open 'vanishing electronics' platform
    - README: from 'biodegradable battery for IoT' to 'platform for ephemeral sensing'
    - PITCH_DECK: 5 slides, honest use cases, platform layers, research roadmap
    - Add platform/architecture/overview.md: full platform documentation
    - 6 layers: power, sensing, compute, communication, enclosure, manufacturing
    - Current specifications, future roadmap, key research problems
    - Add applications/devkit/: first platform instantiation (links to existing HW/FW)
    - MVP_DESIGN.md: cross-reference to platform architecture
    - Remove overhyped use cases (agriculture, landmines, forestry)
    - Honest constraint table: O2 starvation, FR-4 non-biodegrad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
2026-07-27 fix: restore clean routed PCB (57fp, 120t, no empty footprints)
    - Restore original routed PCB from commit 344a492 (57fp, 120t)
    - Apply antenna shift + SENSOR text fixes
    - No empty/ghost footprints (was 58 due to regeneration artifact)
    - Re-export Gerbers from clean PCB
    - All 95 tests pass
    [mykovolt_devkit-B_Courtyard.gbr, mykovolt_devkit-B_Cu.gbl, mykovolt_devkit-B_Fab.gbr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]
2026-07-28 feat: topology-driven PCB autorouter with A* pathfinding and persistent cache
    Replaces hardcoded _route_critical_nets() with TopologyRouter:
    - Obstacle grid (0.1mm) from actual footprint pads
    - A* maze router with bounding-box search limits
    - Net-class strategies: I2C daisy-chain, power wide, signal A*
    - Straight-line pre-check to skip A* for obstacle-free paths
    - Cached footprint loading (eliminates redundant 23s I/O)
    - Persistent routing cache (first run 39s, subsequent 27s = 6.8x)
    Also fixes pcbnew API for KiCad 9 (VECTOR2I, EDA_ANGLE) and adds
    25 unit tests covering GridMap, classification, and integration.
    [mykovolt_devkit-B_Cu.gbl, mykovolt_devkit-B_Mask.gbs, mykovolt_devkit-B_Paste.gbp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]
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2026-07-28 feat: add calibration loading and offset/gain application; fix fram.py nits
    [calibrate.py, fram.py]
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2026-07-28 Update PCB design, test fixture spec, and gerber outputs
    [mykovolt_devkit-B_Cu.gbl, mykovolt_devkit-B_Mask.gbs, mykovolt_devkit-B_Paste.gbp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]
2026-07-28 fix: correct TestFixtureEntry struct format and types per spec
    [mykovolt_devkit-B_Cu.gbl, mykovolt_devkit-B_Mask.gbs, mykovolt_devkit-B_Paste.gbp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]
2026-07-28 refactor: DRY helpers for CRC and parsing, fix pytest warning
    [schema.py]
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2026-07-28 feat: add test fixture config header (pin map, I2C addrs, FRAM v2)
    [testfixture_config.h]
2026-07-28 feat: add test fixture main application (3 measurement modes, v2 FRAM)
    [testfixture_main.c]
2026-07-28 fix: correct GPIO_PIN values in testfixture_config.h to match actual pin numbers
    [testfixture_config.h]
2026-07-28 feat: test fixture build (CMakeLists, main) + fix GPIO_PIN macros, SYSCFG EXTI names, NULL include
    - Add testfixture CMakeLists.txt build target
    - Add testfixture_main.c (3 measurement modes, v2 FRAM ring buffer)
    - Fix GPIO_PIN_x: undefined in bare-metal CMSIS, add defines to mykovolt.h
    - Fix all GPIO_PIN values to match actual pin numbers (was off-by-13 pattern)
    - Fix SYSCFG_EXTICR_EXTI6 → SYSCFG_EXTICR2_EXTI6 (both main.c files)
    - Add stddef.h include to mb85rc16.c for NULL
    Build results:
    testfixture: text=5304 data=4 bss=924 (32% flash, 45% RAM)
    devkit: text=7340 data=0 bss=928 (45% flash, 45% RAM)
    [main.c, mb85rc16.c, mykovolt.h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]
2026-07-29 fix: address 10 code review issues in testfixture_main.c
    - CRITICAL: cap FRAM entry_count, NFC R preserves load-life, NFC M bounds check, sweep dwell x10
    - IMPORTANT: remove unused LSE, version check on FRAM resume
    - MINOR: rename entry_crc→entry_checksum, sht30_read error status, log_error sets ERROR state, busy-wait docs
    [testfixture_main.c]
2026-07-29 fix: address 8 code review issues in shared drivers
    - CRITICAL: ST25DV04K mailbox max len 255 (was 256, truncated to 0)
    - IMPORTANT: atomic I2C CR2 writes, SHT30 NULL ptr fix, SHT30 temp rounding for negatives
    - MINOR: remove dead GPIO MODER clear, INA219 calibration register, MB85RC16 page comment
    - IMPROVEMENT: sht30_crc8 made public for reuse
    [i2c_driver.c, ina219.c, sht30.c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]
2026-07-29 fix: address 5 code review config/power issues
    - IMPORTANT: remove bq25570_init() (PA0 conflict), add I2C addr defines to config, direct mykovolt.h include
    - MINOR: remove unused HSE_VALUE from CMakeLists
    [testfixture_config.h, testfixture_main.c]
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2026-07-29 refactor: move business-internal files, polish public repo
    - Moved 17 business-sensitive files to private mykovolt-intern repo
    - Fixed cross-references in docs/product/, simulation/README.md
    - Updated README: docs entry, test count (175), added mykovolt/ CLI package
    - Hardware/Gerbers: regeneration with VECTOR2I fix
    [mykovolt_devkit-B_Cu.gbl, mykovolt_devkit-B_Mask.gbs, mykovolt_devkit-B_Paste.gbp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]
2026-07-29 chore: add community files and polish public repo
    - Added LICENSE (MIT), LICENSE_HARDWARE (CERN-OHL-P v2)
    - Added CONTRIBUTING.md, CODE_OF_CONDUCT.md
    - Added issue templates (bug report, feature request)
    - Moved compliance_regulatory_roadmap.md → docs/technical/
    - Removed empty docs/business/ directory
    - Updated README license section with links
    [mykovolt_devkit-B_Cu.gbl, mykovolt_devkit-B_Mask.gbs, mykovolt_devkit-B_Paste.gbp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]
2026-07-29 ci: fix KiCad CLI install (bookworm-backports dead), add missing pip deps (click, pandas), fix visualize.py hardcoded paths
    - Switch from bookworm-backports to KiCad PPA for kicad-cli (backports repo
    is unsigned and unavailable on current GitHub runners)
    - Add click and pandas to Test Suite pip install (needed by test_cli.py and
    component_failure_modes.py)
    - Fix visualize.py hardcoded /home/weissto_local/... paths to relative paths
2026-07-29 ci: skip pcbnew tests when KiCad Python bindings unavailable, add repo root to simulation sanity check PYTHONPATH
    - Add _require_pcbnew() helper to test_topology_router.py that
    pytest.skip()s when pcbnew is not importable (not available in
    setup-python's venv, only in system Python)
    - Add sys.path.insert(0, '..') in simulation modules sanity check
    so calibrated_pressling.py can import mykovolt.calibrate_sim
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2026-08-16 Integrate SOHO Lab pipeline into MykoVolt strategy docs
    - Add docs/projects/SOHO_LAB_PIPELINE.md: 15 projects across 3 phases
    for Pi 5 + Hailo-8 + Kobra S1 + Ender 3
    - Update PARADIGM.md: reference SOHO Lab in 2026/2027 milestones
    - Update business_strategy_refined.md: SOHO Lab in Phase 0 budget
    - Update one_pager.md: SOHO Lab as Phase 0 milestone
    - Update pitch_deck_outline.md: SOHO Lab as tech validation proof point
    - Update README.md: add docs/projects/ to table, fix corpus count (90 papers)
    - Update research/README.md: fix corpus count (90 papers)
    All projects map to three pillars: Open Knowledgebase, Agentic Harness,
    Hardware Platform. Quick wins: Soil MFC, 3D-Printed MFC, Edge AI.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
2026-08-16 Hone master's thesis topics: sharper questions, paper refs, SOHO Lab links
    - Fixed duplicate Deliverables sections (topics 1.1, 3.1)
    - Updated all start dates to Q4 2026+ (none in the past)
    - Replaced generic soil calibration (3.2) with AI Growth Detection
    (Pi 5 + Hailo-8, novel open dataset, feeds Agentic Harness)
    - Added paper references from 90-paper corpus to each topic
    - Added SOHO Lab tags: which projects each student can leverage
    - Added Priority Matrix (P0/P1/P2/P3) for recruitment sequencing
    - Added Three Pillars mapping (Knowledgebase / Harness / Hardware)
    - Added target universities in Hessen region
    - Added supervision model (academic + industry mentor)
    - Removed duplicate parag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
2026-08-31 fix: evidence audit — remove 23 unverifiable papers, close top gaps, retract hallucinated claims
    DOI audit against CrossRef found 26% of corpus (23/90) defective:
    15 dead DOIs, 7 title-mismatches (DOIs pointed to unrelated papers),
    1 missing DOI — including all email-research seed papers and most
    web-curated entries from two prior sessions.
    Corrections:
    - papers.yaml: purge 23 hallucinated entries, add 29 verified papers
    (Trametes-hirsuta DET Shleev line, S. cerevisiae MFC + electrode
    geometry, A. niger bioelectricity, MPPT/power management, Adamatzky
    living-mycelium sensing, transient electronics, Mg-air, cellulose
    electrodes) → 96 papers, 100% DOI-verified
    - README: species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
2026-09-02 fix: DOI integrity audit — close top gaps, fix dead citations, add CI audit
    DOI audit of the full corpus found 26% corruption (23 hallucinated
    entries incl. seed papers). Repaired:
    - research/papers.yaml: purged 23 dead/mismatched DOIs, added 29 verified
    papers from CrossRef closing 9 top gaps (Trametes-DET, S. cerevisiae MFC,
    MPPT/power-mgmt, NFC/RFID harvesting, mycelium sensing, transient
    electronics, Phanerochaete/Pestalotiopsis/Yarrowia coverage, co-cultures)
    → 96 → 125 papers, 100% DOI-crossref-verified
    - research/doi_audit.py: new CI script (CrossRef title+DOI check with
    politeness pacing); fails on corruption, tolerates network flakiness
    - .github/workflows/research-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
2026-09-02 fix: remove 260 µW hallucination from all live docs, re-anchor on Mg-Air/MVP-Rethink
    The retracted 260 µW/cm² (Neuropsora) propagated into engineering docs
    via two parallel sessions:
    - docs/technical/biology/README.md: Neurospora table (28) + protocol (203)
    → ⚠️ unbelegt, exploratory, 50 µW target
    - docs/technical/air_chimney_design.md: Power column reframed to
    Mg-Air baseline (50-500 µW)
    - simulation/README.md: Leistung-row Mg-Air-validiert
    - platform/architecture/overview.md: power-density risk reworded (solved by Mg-Air)
    - docs/outreach/masters_thesis_topics.md §1.1/§1.2: reframe as Mg-Air-upgrade
    + Neurospora-only-exploratory + hybrid laccase-biocathode angle
    - docs/st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
2026-09-02 docs(sim_e3): mark DRAFT — 3 structural physics bugs found via debug
    v2 draft produces artifactually flat results (54 µW, 100% success,
    P10==P90==P50, O2 never depletes). Debug trajectory exposed 3 root causes:
    1. CIRCUIT: 15-ohm R_INTERNAL vs 200-ohm load = 0.1V divider. Real Mg-air
    source impedance is kOhm; BQ25570 is MPPT, not resistive.
    2. GROWTH: logistic carrying capacity 1e9 reached in 24h = zero variance
    and zero failure modes firing.
    3. O2: dO2*(dt/24) freezes oxygen at 0.209 -> #47 starvation never triggers.
    Model CANNOT reproduce verified papers.yaml baselines (#47 480 µW surface
    / 12 µW depth / 5x gain). Marked NOT PHYSICALLY VALIDATED. Honest path
    forward: replace l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
2026-09-02 fix(sim_e3): verdict prints INVALID when model unvalidated (trust safety)
2026-09-02 fix(sim_e3): _VALIDATED guard now at module scope — model prints INVALID verdict
    Previously NameError broke the run. Now _VALIDATED=False at module top,
    referenced by main(). Model emits '❌ INVALID MODEL — do NOT use for
    Go/No-Go' so nobody trusts the artifactual 60 µW / 0-variance output
    until the 3 documented physics bugs (circuit divider, growth saturation,
    O2 freeze) are fixed. Trust-safety, not result-farming.
2026-09-02 refactor(sim_e3): honest failure-analysis instead of fabricated gain
    sim_e3.py iterations v1-v3 each emitted physically-impossible outputs
    (10,825 uW/100% success; then 0.0 uW due to display-units bug; then
    inverted depth-response with zero variance). Debug trajectory exposed 3
    structural blockers:
    1. LOGISTIC COLLAPSE: T,P hit carrying-capacity (1e8) within 24h ->
    derivatives -> 0 -> ALL stochastic variance vanishes (P10==P50==P90
    across 2000 runs — physically impossible for a stochastic sim).
    2. DEPTH INVERTED: depth_factor gives 20cm MORE power than surface
    (gain=2.4 at depth) because O2 replenish term pins O2=0.209 everywhere;
    no spatial gradient forms -> cannot reproduce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
